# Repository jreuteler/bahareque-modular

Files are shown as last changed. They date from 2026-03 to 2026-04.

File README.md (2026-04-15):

# BaharequeModular

### Open-Source Prefabricated Panel Construction System

**Community-built, 80–100 year housing from local materials.**

> *This project is in active development. This initial publication is a work in progress — documentation will be refined, technical drawings improved, and the system built and tested in Colombia (Eje Cafetero region). All findings, test results, and design iterations will be published here as they happen. Feedback, suggestions, and contributions are welcome — file an issue or submit a pull request.*

---

## Related Techniques

This system builds on a worldwide family of traditional frame-and-infill construction: **bahareque** (Colombia), **quincha** (Peru/Chile), **wattle-and-daub** (global), **Fachwerk/colombage** (Europe), **dhajji-dewari** (Kashmir), **gaiola pombalina** (Portugal), **bajareque** (Honduras), **taquezal** (Nicaragua), **tabique** (Mexico/Philippines), **tsuchikabe** (Japan), **pau-a-pique** (Brazil). See [Philosophy](en/01-philosophy.md) for how each tradition informs this design.

## Why This Exists

Billions of people live in housing that fails — in earthquakes, floods, or simply from age. Most "affordable housing" lasts 15–20 years, trapping families in endless rebuild cycles.

**Bioconstruction** (bamboo, earth, lime) gives beautiful, breathable buildings with millennia of proven performance in tropical climates — but often lacks structural safety for seismic zones.

**Modern construction** (steel, concrete) gives safety and permits — but is expensive, requires specialized skills, and has no soul.

This system bridges both:

- **Traditional where it's seen** — lime plaster, guadua bamboo, natural textures
- **Modern where it matters** — galvanized steel L-angle frame carries seismic loads
- **80–100 year lifespan** — you build once, not every generation
- **Community-producible** — screw-clamping needs no welding, no specialized tools
- **Permaculture-integrated** — uses local bamboo, turns invasive grass into fiber reinforcement
- **Open source** — because the knowledge to build safe, beautiful, affordable housing should not be locked behind patents or consulting fees

## Quick Specs

| | |
|---|---|
| **Panel size** | 1.0 m × 2.5 m (vertical, scalable to any height) |
| **Dry-assembly weight** | ~75 kg (2 people — shipped to site before in-situ mortar pour) |
| **Finished weight (baseline mix)** | ~440 kg (≈ 176 kg/m²) |
| **Finished weight (optimized bahareque mix)** | ~360 kg (≈ 144 kg/m²) |
| **Frame** | L 40×40×4 mm, hot-dip galvanized steel (ASTM A36 / ICONTEC NTC 2542) |
| **Infill** | Structural bamboo strips, screw-clamped (30 % cavity density at baseline spec) |
| **Bracing** | Diagonal bamboo strips (3–5× seismic improvement) |
| **Mortar (baseline)** | 1:4 cement:sand + pozzolanic admixture |
| **Mortar (optimized)** | Pozzolanic lime + fly ash/RHA + pasto estrella fiber |
| **Pour method** | In-situ vertical pour (preferred) or workshop vibration-table pour |
| **Finish** | Lime plaster + lime wash |
| **Wall thickness** | ~85 mm |
| **Variants** | P (pass-through), O (outlet), S (switch), W (water) |
| **Integrated electrical** | 12V lighting + 120V mains, snap-connect between panels |

> _Combined-profile diagram pending — the previous SVG (`svg/11-combined-profile-face.svg`) shows T-bar geometry and is not representative of the current L 40×40×4 angle frame. See [`SVG-STATUS.md`](SVG-STATUS.md) for the full SVG regeneration task list._

## Repository Structure

```
bahareque-modular/
├── README.md              ← You are here
├── LICENSE-CERN-OHL-S-v2.txt
├── LICENSE-CC-BY-SA-4.0.txt
├── en/                    ← English documentation
│   ├── 01-philosophy.md
│   ├── 02-panel-anatomy.md
│   ├── 03-materials.md
│   ├── 04-construction-process.md
│   ├── 05-structural-performance.md
│   ├── 06-corrosion-prevention.md
│   ├── 08-contributing.md
│   ├── 09-cost-estimate.md
│   ├── 10-environmental-impact.md
│   ├── 11-transport-handling.md
│   ├── 12-climate-adaptation.md
│   ├── 13-bamboo-treatment.md
│   └── 14-acoustic-upgrade.md
├── de/                    ← Deutsche Dokumentation
├── es/                    ← Documentación en español
├── pt/                    ← Documentação em português
├── it/                    ← Documentazione in italiano
├── fr/                    ← Documentation en français
├── svg/                   ← Technical diagrams (language-neutral)
└── stl/                   ← 3D printable panel model
```

## Licensing

| Content | License |
|---|---|
| Hardware designs (SVGs, STLs, construction specs) | [CERN-OHL-S v2](LICENSE-CERN-OHL-S-v2.txt) |
| Documentation (text, educational content) | [CC BY-SA 4.0](LICENSE-CC-BY-SA-4.0.txt) |

**What this means:** You can freely use, modify, and distribute everything. But modifications must remain open source under the same licenses. No one can close this — not even us.

### License FAQ — Plain Language

**Can I build a house with this system?**
Yes. Free. No permission needed. No fees. No registration.

**Can I build panels and sell them?**
Yes. But you must share any design modifications you make under the same open licenses. You cannot patent your modifications.

**Can I teach a course using these documents?**
Yes. Credit the project and share any new materials you create under CC BY-SA 4.0.

**Can I patent a variation of this system?**
No. The CERN-OHL-S v2 license requires that anyone who distributes the design or products based on it grants a royalty-free patent license. This prevents anyone — including us — from patenting the system or its derivatives.

**Can a company use this commercially?**
Yes. Companies can manufacture and sell panels built with this system. They must share any design modifications under CERN-OHL-S v2. They cannot add patent restrictions.

**Why two licenses?**
CERN-OHL-S v2 is designed for physical hardware — it protects the panel design, construction method, and STL files, and includes patent defense. CC BY-SA 4.0 is designed for written works — it protects the documentation, diagrams, and educational content, and is recognized worldwide in 40+ languages. Together they cover everything.

**What if someone ignores the license?**
The same thing that happens with any open-source license violation: the community notices, the violation is documented, and legal action can follow. CC BY-SA has been upheld in courts worldwide. CERN-OHL-S is backed by CERN's legal framework.

**Can someone take this project private / close the source?**
No. Both licenses are copyleft / share-alike. Every derivative must remain open under the same terms. This is permanent and irrevocable.

## Contributing

This is a living project. We need:

- **Builders** — try it, document your experience, share what worked and what didn't
- **Engineers** — structural testing, seismic analysis, code compliance research
- **Bamboo experts** — adaptation notes for species beyond Guadua angustifolia
- **Translators** — help bring the documentation to more languages
- **Designers** — improve the SVGs, create assembly animations, render visualizations

File an issue. Submit a PR. All contributions inherit the same open licenses.

## Origin & Contact

Designed by **Jan Reuteler** (janreuteler@icloud.com), Switzerland.

Developed for the Colombian Andes (Eje Cafetero, ~2,000 m altitude) using locally available *Guadua angustifolia* — the strongest structural bamboo in the Americas. The principles apply to any tropical or subtropical region with access to structural bamboo, cement, and basic steel fabrication.

---

# BaharequeModular

### Offenes vorgefertigtes Paneel-Bausystem

**Gemeinschaftlich gebaut, 80–100 Jahre Lebensdauer, aus lokalen Materialien.**

> *Dieses Projekt befindet sich in aktiver Entwicklung. Diese erste Veröffentlichung ist ein Zwischenstand — die Dokumentation wird laufend verbessert, technische Zeichnungen verfeinert und das System in Kolumbien (Region Eje Cafetero) gebaut und getestet. Alle Erkenntnisse, Testergebnisse und Designänderungen werden hier veröffentlicht. Feedback, Vorschläge und Beiträge sind willkommen — erstellen Sie ein Issue oder einen Pull Request.*

## Warum dieses Projekt existiert

Milliarden Menschen leben in Häusern, die versagen — bei Erdbeben, Überschwemmungen oder einfach durch Alterung. Die meisten «bezahlbaren» Häuser halten 15–20 Jahre und zwingen Familien in endlose Wiederaufbauzyklen.

**Biokonstruktion** (Bambus, Erde, Kalk) liefert schöne, atmungsaktive Gebäude mit jahrtausendealter Bewährung in tropischen Klimazonen — aber oft ohne ausreichende Erdbebensicherheit.

**Moderne Bauweise** (Stahl, Beton) liefert Sicherheit und Baugenehmigungen — ist aber teuer, erfordert Fachkräfte und hat keine Seele.

Dieses System vereint beides:

- **Traditionell, wo man es sieht** — Kalkputz, Guadua-Bambus, natürliche Texturen
- **Modern, wo es zählt** — verzinkter Stahl-T-Profilrahmen trägt Erdbebenlasten
- **80–100 Jahre Lebensdauer** — einmal bauen, nicht jede Generation
- **Gemeinschaftlich herstellbar** — Schraubklemmsystem braucht kein Schweissen, kein Spezialwerkzeug
- **Permakultur-integriert** — nutzt lokalen Bambus, verwandelt invasive Gräser in Faserverstärkung
- **Open Source** — weil das Wissen, sicheres, schönes, bezahlbares Wohnen zu bauen, nicht hinter Patenten oder Beraterhonoraren eingesperrt sein darf

## Kurzspezifikationen

| | |
|---|---|
| **Paneelgrösse** | 1,0 m × 2,5 m (vertikal, skalierbar auf jede Höhe) |
| **Gewicht — Trockenmontage** | ~75 kg (2 Personen, vor Ort-Mörtelguss) |
| **Gewicht — fertig (Standardmischung)** | ~440 kg (≈ 176 kg/m²) |
| **Gewicht — fertig (optimierte Bahareque-Mischung)** | ~360 kg (≈ 144 kg/m²) |
| **Rahmen** | L-Winkel 40×40×4 mm, feuerverzinkter Stahl (ASTM A36) |
| **Füllung** | Bambus-Strukturstreifen, schraubgeklemmt (30 % Hohlraumdichte) |
| **Aussteifung** | Diagonale Bambus-Aussteifung (3–5× Erdbebenverbesserung) |
| **Mörtel** | 1:4 Zement:Sand + puzzolanisches Zusatzmittel (Standard), oder hydraulischer Kalk + Flugasche/RHA + Pasto-Estrella-Fasern (optimiert) |
| **Gussverfahren** | Vor-Ort-Vertikalguss (bevorzugt) oder Werkstatt-Rütteltisch |
| **Oberfläche** | Kalkputz + Kalkanstrich |
| **Wandstärke** | ~85 mm |

> _Hinweis: Die Übersetzungen (DE/ES/FR/IT/PT) außerhalb dieser Schnellspezifikation spiegeln noch die vorherige T-Profil-Spezifikation wider und werden in einem nachfolgenden Update angeglichen._

## Lizenzierung

| Inhalt | Lizenz |
|---|---|
| Hardware-Designs (SVGs, STLs, Bauspezifikationen) | CERN-OHL-S v2 |
| Dokumentation (Texte, Bildungsinhalte) | CC BY-SA 4.0 |

Sie dürfen alles frei nutzen, verändern und verbreiten. Änderungen müssen unter denselben Lizenzen offen bleiben.

### Lizenz-FAQ

**Kann ich ein Haus mit diesem System bauen?**
Ja. Kostenlos. Ohne Genehmigung. Ohne Gebühren. Ohne Registrierung.

**Kann ich Paneele herstellen und verkaufen?**
Ja. Aber Sie müssen alle Designänderungen unter denselben offenen Lizenzen teilen. Sie können Ihre Änderungen nicht patentieren.

**Kann ich einen Kurs mit diesen Dokumenten geben?**
Ja. Nennen Sie das Projekt und teilen Sie neues Material unter CC BY-SA 4.0.

**Kann jemand eine Variante dieses Systems patentieren?**
Nein. Die CERN-OHL-S v2 Lizenz verlangt, dass jeder, der das Design oder darauf basierende Produkte verbreitet, eine gebührenfreie Patentlizenz erteilt.

**Kann ein Unternehmen dies kommerziell nutzen?**
Ja. Unternehmen können Paneele herstellen und verkaufen. Designänderungen müssen unter CERN-OHL-S v2 geteilt werden. Patentbeschränkungen dürfen nicht hinzugefügt werden.

**Kann jemand dieses Projekt schliessen?**
Nein. Beide Lizenzen sind Copyleft / Share-Alike. Jedes Derivat muss offen bleiben. Dies ist dauerhaft und unwiderruflich.

## Ursprung & Kontakt

Entworfen von **Jan Reuteler** (janreuteler@icloud.com), Schweiz.

Entwickelt für die kolumbianischen Anden (Eje Cafetero, ~2.000 m Höhe) mit lokal verfügbarer *Guadua angustifolia* — dem stärksten Strukturbambus der Amerikas. Die Prinzipien sind auf jede tropische oder subtropische Region mit Zugang zu Strukturbambus, Zement und einfacher Stahlverarbeitung anwendbar.

---

# BaharequeModular

### Sistema Abierto de Paneles Prefabricados

**Construido por la comunidad, 80–100 años de vida útil, con materiales locales.**

> *Este proyecto está en desarrollo activo. Esta publicación inicial es un trabajo en progreso — la documentación se irá refinando, los dibujos técnicos mejorados, y el sistema será construido y probado en Colombia (región del Eje Cafetero). Todos los hallazgos, resultados de pruebas e iteraciones de diseño se publicarán aquí. Comentarios, sugerencias y contribuciones son bienvenidos — abra un issue o envíe un pull request.*

## Por qué existe este proyecto

Miles de millones de personas viven en viviendas que fallan — en terremotos, inundaciones o simplemente por el paso del tiempo. La mayoría de la «vivienda asequible» dura 15–20 años, atrapando a las familias en ciclos interminables de reconstrucción.

**Bioconstrucción** (guadua, tierra, cal) ofrece edificios hermosos y transpirables con milenios de rendimiento comprobado en climas tropicales — pero frecuentemente sin suficiente seguridad sísmica.

**Construcción moderna** (acero, concreto) ofrece seguridad y permisos — pero es costosa, requiere mano de obra especializada y carece de alma.

Este sistema une ambos mundos:

- **Tradicional donde se ve** — pañete de cal, guadua, texturas naturales
- **Moderno donde importa** — marco de acero galvanizado en T soporta cargas sísmicas
- **80–100 años de vida útil** — se construye una sola vez, no cada generación
- **Producible por la comunidad** — el sistema de sujeción por tornillo no requiere soldadura ni herramientas especializadas
- **Integrado con permacultura** — usa guadua local, convierte pastos invasivos en refuerzo de fibra
- **Código abierto** — porque el conocimiento para construir vivienda segura, bella y asequible no debe estar encerrado detrás de patentes ni honorarios de consultoría

## Especificaciones rápidas

| | |
|---|---|
| **Tamaño del panel** | 1,0 m × 2,5 m (vertical, escalable a cualquier altura) |
| **Peso — ensamble en seco** | ~75 kg (2 personas, antes del vertido in-situ del mortero) |
| **Peso — terminado (mezcla base)** | ~440 kg (≈ 176 kg/m²) |
| **Peso — terminado (mezcla bahareque optimizada)** | ~360 kg (≈ 144 kg/m²) |
| **Marco** | Ángulo L 40×40×4 mm, acero galvanizado en caliente (ASTM A36 / ICONTEC NTC 2542) |
| **Relleno** | Tiras de bambú estructural, sujetadas con tornillos (30 % de densidad de cavidad) |
| **Arriostramiento** | Tiras diagonales de bambú (mejora sísmica 3–5×) |
| **Mortero** | 1:4 cemento:arena + adición puzolánica (base), o cal hidráulica + ceniza volante/RHA + fibras de pasto estrella (optimizado) |
| **Método de vertido** | Vertido vertical in-situ (preferido) o mesa vibratoria en taller |
| **Acabado** | Pañete de cal + lechada de cal |

> _Nota: Las traducciones (DE/ES/FR/IT/PT) fuera de esta especificación rápida aún reflejan la especificación anterior de perfil T y se actualizarán en una revisión posterior._
| **Espesor de muro** | ~85 mm |

## Licenciamiento

| Contenido | Licencia |
|---|---|
| Diseños de hardware (SVGs, STLs, especificaciones constructivas) | CERN-OHL-S v2 |
| Documentación (textos, contenido educativo) | CC BY-SA 4.0 |

Puede usar, modificar y distribuir todo libremente. Las modificaciones deben permanecer abiertas bajo las mismas licencias. Nadie puede cerrar esto — ni siquiera nosotros.

### Preguntas Frecuentes sobre la Licencia

**¿Puedo construir una casa con este sistema?**
Sí. Gratis. Sin permiso. Sin tarifas. Sin registro.

**¿Puedo fabricar paneles y venderlos?**
Sí. Pero debe compartir cualquier modificación de diseño bajo las mismas licencias abiertas. No puede patentar sus modificaciones.

**¿Puedo dar un curso usando estos documentos?**
Sí. Cite el proyecto y comparta cualquier material nuevo bajo CC BY-SA 4.0.

**¿Se puede patentar una variación de este sistema?**
No. La licencia CERN-OHL-S v2 requiere que cualquier persona que distribuya el diseño o productos basados en él otorgue una licencia de patente libre de regalías.

**¿Puede una empresa usar esto comercialmente?**
Sí. Las empresas pueden fabricar y vender paneles. Deben compartir modificaciones de diseño bajo CERN-OHL-S v2. No pueden agregar restricciones de patente.

**¿Alguien puede cerrar el código fuente de este proyecto?**
No. Ambas licencias son copyleft / share-alike. Cada derivado debe permanecer abierto. Esto es permanente e irrevocable.

## Origen y contacto

Diseñado por **Jan Reuteler** (janreuteler@icloud.com), Suiza.

Desarrollado para los Andes colombianos (Eje Cafetero, ~2.000 m de altitud) usando *Guadua angustifolia* disponible localmente — el bambú estructural más fuerte de las Américas. Los principios son aplicables a cualquier región tropical o subtropical con acceso a bambú estructural, cemento y fabricación básica de acero.

---

# BaharequeModular

### Sistema Aberto de Painéis Pré-fabricados

**Construído pela comunidade, 80–100 anos de vida útil, com materiais locais.**

> *Este projeto está em desenvolvimento ativo. Esta publicação inicial é um trabalho em andamento — a documentação será refinada, os desenhos técnicos melhorados, e o sistema será construído e testado na Colômbia (região do Eje Cafetero). Todos os resultados e iterações de design serão publicados aqui. Comentários, sugestões e contribuições são bem-vindos.*

Documentação completa: [pt/](pt/)

**Licença:** Hardware: CERN-OHL-S v2 · Documentação: CC BY-SA 4.0

Pode construir, fabricar, vender, ensinar — tudo livre. Modificações devem permanecer abertas. Ninguém pode patentear variações. Ninguém pode fechar o código. Permanente e irrevogável.

Projetado por **Jan Reuteler** (janreuteler@icloud.com), Suíça.

---

# BaharequeModular

### Sistema Aperto di Pannelli Prefabbricati

**Costruito dalla comunità, 80–100 anni di vita utile, con materiali locali.**

> *Questo progetto è in sviluppo attivo. Questa pubblicazione iniziale è un lavoro in corso — la documentazione verrà perfezionata, i disegni tecnici migliorati, e il sistema sarà costruito e testato in Colombia (regione dell'Eje Cafetero). Tutti i risultati e le iterazioni di design saranno pubblicati qui. Commenti, suggerimenti e contributi sono benvenuti.*

Documentazione completa: [it/](it/)

**Licenza:** Hardware: CERN-OHL-S v2 · Documentazione: CC BY-SA 4.0

Si può costruire, fabbricare, vendere, insegnare — tutto libero. Le modifiche devono rimanere aperte. Nessuno può brevettare variazioni. Nessuno può chiudere il codice. Permanente e irrevocabile.

Progettato da **Jan Reuteler** (janreuteler@icloud.com), Svizzera.

---

# BaharequeModular

### Système Ouvert de Panneaux Préfabriqués

**Construit par la communauté, 80–100 ans de durée de vie, avec des matériaux locaux.**

> *Ce projet est en développement actif. Cette publication initiale est un travail en cours — la documentation sera affinée, les dessins techniques améliorés, et le système sera construit et testé en Colombie (région de l'Eje Cafetero). Tous les résultats et itérations de conception seront publiés ici. Commentaires, suggestions et contributions sont les bienvenus.*

Documentation complète : [fr/](fr/)

**Licence :** Hardware : CERN-OHL-S v2 · Documentation : CC BY-SA 4.0

Vous pouvez construire, fabriquer, vendre, enseigner — tout est libre. Les modifications doivent rester ouvertes. Personne ne peut breveter des variations. Personne ne peut fermer le code. Permanent et irrévocable.

Conçu par **Jan Reuteler** (janreuteler@icloud.com), Suisse.

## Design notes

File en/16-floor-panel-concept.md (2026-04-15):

# Floor Panel Concept — Bamboo Bowstring Beam

> **Status: Concept under refinement — not tested.** This document describes a proposed extension of the BaharequeModular panel system for horizontal floor/ceiling spans. All structural estimates are analytical and require lab validation. Contributions, critique, and testing offers are welcome.

## The Goal

Extend BaharequeModular from a wall system to a **complete building system** — walls, floors, and ceilings from the same production line, same materials, same skills. No concrete slab. No steel beams. No rebar.

## The Problem

A standard 85 mm wall panel fails when laid horizontally to span 4–5 m as a floor. The mortar cracks in tension on the bottom face — the panel was designed for compression (walls), not bending (floors).

## The Solution: Bamboo Bowstring Beam

A single T-bar frame (the same part used in wall panels) with a **tied-arch** mechanism inside:

- **Bamboo compression arch** — strips forced into a parabolic curve by graduated perpendicular cross-pieces sitting on top of the T-bar web
- **Bamboo tension tie** — 26 strips (30 × 35 mm) screw-clamped in a single layer across the bottom T-bar flange
- **Mortar** fills and stabilizes everything
- **Minimal steel in the span** — one longitudinal T-bar as central spine, plus perimeter T-bar frame for connections

Floor Panel Side View

Each material does what it does best:

| Material | Role | Strength used |
|---|---|---|
| Bamboo arch | Compression | 45 MPa (only 20–31% utilized) |
| Bamboo tie | Tension | 25 MPa at 30% utilization |
| Bamboo cross-pieces | Geometry control | Forces arch into parabolic shape |
| Mortar | Fill + stability | Compression zone above arch |
| T-bar frame | Edge connection | Shear at supports, connection to walls |

Floor Panel Top View

## How It Works

A bowstring beam (tied arch) converts the vertical floor load into horizontal thrust. The arch carries this thrust in compression. The tie resists it in tension. The two are in equilibrium — the mortar fills between them, providing stability and distributing local loads.

```
     load (people, furniture)
     ↓ ↓ ↓ ↓ ↓ ↓ ↓ ↓ ↓ ↓ ↓
┌───────────────────────────────┐
│  mortar (compression fill)    │
│   ╭───── bamboo ARCH ─────╮  │ ← compression
│   │    forced up by         │ │
│   │    cross-pieces         │ │
│   ╰─────────────────────────╯ │
│  ════ bamboo TIE ════════════ │ ← tension
└───────────────────────────────┘
     ↑                       ↑
   wall                    wall
```

The arch rise (distance from tie to arch crown) determines how much thrust is generated. A taller arch = less thrust = fewer tie strips needed.

## Specifications (180 mm panel, recommended)

| Property | Value |
|---|---|
| Panel dimensions | 1.0 m wide × 4.0 or 5.0 m span |
| Total depth | 180 mm |
| T-bar frame | Standard T 60×60 mm (7 mm thick, 53 mm web) — single frame at bottom |
| Longitudinal T-bar | Standard T 60×60 mm (7 mm thick, 53 mm web) — single bar centered along the span |
| Bamboo arch | 27 strips × 20×20 mm × 2 layers, forced into parabola |
| Cross-pieces | 30×30 mm perpendicular bamboo, graduated 0→40 mm |
| Bamboo tie | 26 strips × 30×35 mm, single layer, screw-clamped (13 per side of longitudinal T-bar) |
| Arch rise | 127 mm (tie to crown) |
| Weight | ~325 kg/m² |

## Structural Performance

| Span | Thrust | Arch ratio | Combined tie ratio | Deflection | Status |
|---|---|---|---|---|---|
| 4.0 m | 121 kN | 0.31 (69% reserve) | 0.42 (58% reserve) | 2.2 mm / 13.3 limit | OK |
| 5.0 m | 189 kN | 0.49 (51% reserve) | 0.65 (35% reserve) | 5.0 mm / 16.7 limit | OK |

Floor load: 4.5 kN/m² (dead 2.5 + live 2.0, per NSR-10 residential). Self-weight included.

Combined tie capacity: bamboo tie (205 kN) + longitudinal T-bar in tension (86 kN) = 291 kN.

## Longitudinal T-Bar — Central Spine

A single standard T-bar (T 60×60 mm (7 mm thick, 53 mm web)) runs the full span length, centered in the 1 m width, positioned 10 mm above the bottom panel surface. This converts the panel from a pure bowstring into a hybrid bowstring + reinforced beam.

```
CROSS-SECTION (looking along span):

    ←────────── 1,000 mm ──────────→
    ┌──────────────────────────────────┐
    │           mortar                 │
    │    ╭──── bamboo arch ────╮       │  180 mm
    │    │                     │       │
    │    ╰─────────────────────╯       │
    │  ═ tie ═══ ┬─┤ ═══ tie ═════    │
    │            │w│                   │  ← longitudinal T-bar
    │         ┌──┴─┴──┐                │     10 mm from bottom
    └─────────┘flange └────────────────┘
              ←30mm→
         13 strips    13 strips
         each side    each side
```

### Why It Matters

The bamboo tie alone carries 205 kN — at a 5 m span with 189 kN of thrust, that is 98% utilization (2% reserve). This is the weakest link in the entire panel.

The longitudinal T-bar adds 86 kN of steel tension capacity (345 mm² × 250 MPa yield), bringing the combined capacity to 291 kN — a **42% increase** for just 13.5 kg of steel.

| | Bamboo tie only | Bamboo tie + T-bar |
|---|---|---|
| Tension capacity | 205 kN | 291 kN |
| Tie ratio (5 m) | 0.98 | 0.65 |
| Safety factor (5 m) | 2.04 | 2.90 |

### Additional Benefits

- **Redundancy** — hybrid system: if the bowstring mechanism partially fails, the T-bar alone carries 78% of the required bending moment as a reinforced beam
- **Deflection** — steel stiffness (E = 200 GPa) significantly reduces mid-span deflection
- **Clamping anchor** — the V-profile strips at the supports can be welded to the longitudinal T-bar where they cross, creating a steel-to-steel connection
- **Soffit rail** — the flange at 10 mm from bottom provides a continuous steel rail for temporary soffit panel clamps during the pour

### Specification

| Property | Value |
|---|---|
| Profile | Standard T 60×60 mm (7 mm thick, 53 mm web) |
| Length | Full span (4.0 or 5.0 m) |
| Position | Centered in 1 m width, 10 mm from bottom surface |
| Weight | 10.8 kg (4 m) / 13.5 kg (5 m) |
| Cost | ~$15–20 |
| Tie strip layout | 13 strips per side (26 total, same as before) |

The same T-bar profile used in the perimeter frame. Same stock, same supplier, one extra cut per panel.

## Critical Detail: Tie Strip Clamping

The bamboo tension tie carries the full horizontal thrust of the arch — 121 kN (4 m span) or 189 kN (5 m span), shared across 26 strips. Per strip:

| Span | Tension per strip | With safety factor 2.0 |
|---|---|---|
| 4.0 m | 4,654 N | 9,308 N |
| 5.0 m | 7,269 N | 14,538 N |

If the clamping fails, the entire bowstring mechanism fails. This is the most critical connection in the panel.

### The Problem with Smooth Clamping

Each tie strip crosses the transverse T-bar at each support end. The T-bar flange is only 30 mm wide — providing 30 mm of clamping length per end. With smooth steel-on-bamboo friction (μ ≈ 0.4), the pull-out capacity is marginal at 4 m and insufficient at 5 m.

### Solution: V-Profile Clamping Strip

A steel clamping strip with a stamped **V-tooth profile** (teeth facing the bamboo) converts the connection from friction to mechanical interlock:

```
    screw    screw    screw
       ↓        ↓        ↓
      ╔═╗      ╔═╗      ╔═╗
──────╝ ╚──────╝ ╚──────╝ ╚──  top V-strip (teeth down)
  ╲╱╲╱╲╱╲╱╲╱╲╱╲╱╲╱╲╱╲╱╲╱╲╱╲   teeth indent into bamboo
  ════════════════════════════   bamboo tie strips
  ╱╲╱╲╱╲╱╲╱╲╱╲╱╲╱╲╱╲╱╲╱╲╱╲╱   teeth indent into bamboo (offset)
──────────────────────────────  bottom V-strip (teeth up)
══════════════════════════════  T-bar flange
```

Two V-profile strips sandwich the bamboo — the bottom strip sits on the T-bar flange (teeth up), the top strip presses down (teeth down). The teeth are **offset by half a pitch** (3 mm) so they engage different fibers on each face, avoiding stress concentration and splitting risk.

### Clamping Strip Specification

| Property | Value |
|---|---|
| Material | 3 mm galvanized steel flat bar |
| Width | 100 mm |
| V-tooth pitch | 6 mm |
| V-tooth depth | 2 mm |
| Length | 1,000 mm (full panel width — one strip clamps all 26 ties) |
| Screws | M5, every 2nd strip (13 screws per end) |
| Quantity | 4 per panel (top + bottom at each support end) |
| Cost | ~$5/panel |
| Fabrication | Stamp or press V-profile into flat bar with toothed die |

### Capacity Estimate

Each V-tooth creates a shear lip in the bamboo:

- Shear area per tooth: 30 mm (strip width) × 1.5 mm (indent) = 45 mm²
- Bamboo shear strength parallel to grain: ~7 MPa
- Resistance per tooth: 315 N
- Teeth per strip (100 mm at 6 mm pitch): ~16 teeth
- Mechanical interlock per face: 16 × 315 = **5,040 N**
- Double-sided (top + bottom): 2 × 5,040 = **10,080 N per end**
- **Both ends: ~20,160 N**

| Span | Required (SF=2.0) | Double V-profile capacity | Reserve |
|---|---|---|---|
| 4.0 m | 9,308 N | 20,160 N | 117% |
| 5.0 m | 14,538 N | 20,160 N | 39% |

These estimates are conservative — they ignore the mortar bond that encases the entire clamping zone after the pour.

### Support Node: Teak End Block

The V-profile clamping must anchor to something solid at the supports. HDPE blocks — used as spacers in wall panels — are too soft for this role: HDPE creeps under sustained load (losing 60–70% of strength over decades) and is 15× less stiff than wood. A floor panel under permanent dead load needs a material that holds its shape for 50+ years.

**Solution: a teak end block at each support.**

```
CROSS-SECTION AT SUPPORT:

    ┌──────────────────────────────┐ 180 mm
    │          mortar              │
    │    ┌────────────────────┐    │
    │    │                    │    │
    │    │    TEAK BLOCK      │    │ 60 mm
    │    │    60 × 60 mm      │    │
    │    │                    │    │
    │    └────────────────────┘    │
    │    ════ tie strips ═════    │
    └──────────────────────────────┘
         ←── 60 mm ──→
           (along span)
```

| Property | Value |
|---|---|
| Species | Tectona grandis (teak) |
| Cross-section | 60 × 60 mm |
| Length | 1,000 mm (full panel width) |
| Grain direction | Parallel to thrust (along span) |
| Quantity | 2 per panel (one per support end) |
| Weight | ~2.4 kg per block |
| Cost | ~$3.50 per block |
| Source | B-grade pieces and offcuts from structural teak — hidden inside mortar, appearance irrelevant |

**Why teak works here:**

| Property | HDPE | Teak |
|---|---|---|
| Compressive strength ∥ grain | 22 MPa | 58 MPa |
| Stiffness | 1.0 GPa | 13 GPa |
| 50-year creep | 60–70% loss | <5% loss |
| Rot resistance | Immune | Class 1 (natural oils) |
| Screw-holding (M5) | Poor | ~1,350 N withdrawal per screw |
| Bolt holes (M12) | Crush risk | Clean, tight, no splitting |

Arch bearing stress on the teak block (5 m span): 189,000 N / 60,000 mm² = 3.15 MPa — just **5.4% utilization** of teak's 58 MPa capacity.

**The teak block serves as a multi-function structural node:**

1. **Arch bearing** — arch strips push against its inner face
2. **V-strip mounting** — screws for the clamping strips bite into teak
3. **Overlength bolt passage** — M12 × 110 mm bolts drill clean through 60 mm
4. **Geometry anchor** — defines exact arch start point at each support
5. **No treatment needed** — teak's natural oils resist rot inside mortar

HDPE spacer blocks remain in mid-span zones where forces are low and their role is geometry only.

### Testing Priority

A pull-out test of a single clamped strip is the simplest and most critical validation: clamp one 30 × 35 mm bamboo strip between V-profile strips on a teak block, pull to failure, measure peak force. This can be done with a hydraulic jack and a bathroom scale in minutes.

## Integrated Services

Services are embedded during the pour — same approach as wall panels:

- **Electrical conduit** (12V + 120V) in the core — ceiling lights below, floor outlets above
- **Water pipes** (CPVC/PEX) horizontal runs in the core
- **Recessed LED lights** — junction boxes flush with bottom T-bar flange
- **Snap-connect** at panel edges — circuits continue from wall to floor to wall

## Acoustic Performance

The mortar mass provides STC 52–55 (airborne sound). Impact noise (footsteps) is addressed by:

- **Pasto estrella fiber** (3–5% by volume) in the upper mortar zone — free invasive grass, millions of fiber-mortar interfaces absorb vibration
- **Cork underlay** (3 mm) under terracotta tiles — $4/m², adds IIC +15–20
- Combined: IIC 58–63 (luxury hotel level) at minimal cost

## Construction Process

Poured in place on top of wall panels:

1. Set T-bar frame on connector shelf (~25 kg — easy to carry)
2. **Bolt adjacent floor panel frames together** — 2× M12 through shared longitudinal flanges (at 1/3 and 2/3 of span)
3. Bolt floor frame to connector shelf — 2× M12 vertical at each support end
4. Clamp soffit panel from below — positioned **10–15 mm below the T-bar bottom flange** to allow mortar to flow under and fully encase the steel frame from below. The soffit defines the ceiling surface.
5. Screw-clamp bamboo tie strips to bottom flange
6. Insert teak end blocks at support zones
7. Lay bamboo arch strips into teak block recesses at designated heights
8. Install conduit, pipes, junction boxes
9. Pour mortar — flows down past the flange, encasing the bottom of the T-bar frame. Standard mix for lower zone, fiber-rich for upper zone.
10. Vibrator probe along the span — eliminates voids, ensures mortar fills under and around the flange
11. Screed top surface flat
12. Cure 7+ days
13. Remove soffit → reuse for next bay. The ceiling face is a smooth mortar surface with the steel frame fully hidden inside (10–15 mm mortar cover below the flange).
14. Lime plaster ceiling directly onto the mortar surface — no bare steel visible
15. Cork + terracotta tiles on top

> **Access panel rule:** Always leave at least one floor panel frame unbolted and unpoured per bay until all neighboring panels are poured and cured. This access panel allows workers to reach the panel-to-panel bolts for tightening and inspection. It is bolted and poured last.

## What's Novel

Exhaustive search of academic literature, patents, and built projects found **no existing system** that combines:

1. Bamboo compression arch within a floor element
2. Bamboo tension tie at the bottom
3. Tied-arch (bowstring) mechanism
4. Mortar encasement

Each principle is well-established individually. The combination is new. Closest prior art:

| Existing work | What's different |
|---|---|
| Curved laminated bamboo-concrete T-beam (2023) | No tension tie, glulam not strips |
| Bamboo-reinforced concrete (Ghavami, 1979+) | Always straight reinforcement, never arched |
| Bowstring trusses (steel/timber) | Never bamboo, never mortar-encased |
| Ferrocement bamboo panels (India) | Flat, short spans, no arch |

## What Needs Testing

Before building floor panels, the following must be validated:

1. **Does the tied-arch action develop?** — Load a test panel, measure horizontal thrust at supports
2. **Does the forced arc hold under load?** — Do cross-pieces maintain the arch geometry?
3. **Bamboo tie tension** — Does the 30×35 mm clamped bundle maintain capacity under arch thrust?
4. **Composite action** — Does the mortar-bamboo bond hold in the arch under compression?
5. **Impact sound** — Measure IIC with and without pasto estrella fiber
6. **Connection** — Test the overlength bolt system (wall-floor-wall triple flange)

A single bending test (simply supported, uniform load) answers questions 1–4 in one afternoon.

## Weight Optimization: Dense Bamboo End Zones

In a bowstring beam, the arch rise is near zero at the supports — the mortar above the arch is at maximum depth but carries no compression. Shear is maximum at the supports, but at only 5% utilization (0.075 MPa vs 1.5 MPa capacity). This means the end zones contain the most mortar doing the least structural work.

**The idea:** replace most of the mortar in the end zones with densely packed bamboo strips.

### Geometry

End zone: first and last 750 mm of the span. The mortar depth above the arch varies from ~140 mm at the support to ~80 mm at 750 mm.

### Fabrication

1. Bundle bamboo strips (20 × 30 mm) tightly, wire-tied into a solid block
2. Cut block ~10 mm wider than the panel cavity (~1,010 mm)
3. Press-fit into the end zone above the arch — the bamboo's natural spring wedges it tight against the T-bar web and panel edges, self-clamping with no fasteners
4. During the mortar pour, mortar penetrates the small irregular gaps between strips, locking everything permanently

With rectangular strips packed tight, the natural surface irregularity of split bamboo yields approximately 60% bamboo / 40% mortar by volume.

### Weight Saving

| | Solid mortar (current) | Dense bamboo packing |
|---|---|---|
| Bamboo | — | 0.099 m³ × 700 kg/m³ = 69 kg |
| Mortar | 0.165 m³ × 2,100 kg/m³ = 347 kg | 0.066 m³ × 2,100 kg/m³ = 139 kg |
| **Total (both ends)** | **347 kg** | **208 kg** |
| **Saving** | — | **~139 kg (11% of panel weight)** |

### Why It Works

- **Shear transfer:** bamboo has good shear strength (~8 MPa) — the dense pack with mortar-filled gaps transfers support shear better than unreinforced mortar alone
- **Bearing capacity:** bamboo excels in compression (45 MPa) — directly above the support, this is an advantage
- **No bending moment** at the supports — the end zones don't need mortar's mass for structural depth
- **Simple fabrication:** pre-assembled blocks can be cut to width and press-fit, adding one easy step to the construction process

## Future Option: Half-Culm Voided Panel

For spans beyond 5 m, split guadua culms (⌀100 mm, open cavity down, drilled air holes) can be embedded in the compression zone above the arch. The hollow cores displace mortar, and the culm walls contribute compression capacity. This increases depth (220+ mm) without proportional weight increase. See detailed analysis in the Suroeste project documentation.

## Implications

If validated, this floor panel makes BaharequeModular a **complete building system**:

- **Walls** — standard 85 mm panel
- **Floors/ceilings** — 180 mm bowstring panel
- **Connections** — bolted T-bar flanges at every junction
- **Electrical** — integrated in all panels, snap-connected
- **Plumbing** — integrated in floor and wall panels
- **Ceiling finish** — lime plaster on floor panel bottom

One panel system. One production line. One set of skills. No rebar, no structural steel beams — bamboo and mortar carry the loads, with one standard T-bar as a central spine for redundancy. Steel only at edges and center for connections and tension backup.

**A bamboo bowstring beam cast in mortar. It doesn't exist yet. We intend to build and test it.**

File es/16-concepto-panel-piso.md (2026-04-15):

# Concepto de Panel de Piso — Viga Arco de Bambú

> **Estado: Concepto en desarrollo — no probado.** Este documento describe una propuesta de extensión del sistema BaharequeModular para luces horizontales de piso/techo. Todas las estimaciones estructurales son analíticas y requieren validación en laboratorio. Contribuciones, críticas y ofertas de ensayos son bienvenidas.

## El Objetivo

Extender BaharequeModular de un sistema de muros a un **sistema constructivo completo** — muros, pisos y techos desde la misma línea de producción, mismos materiales, mismas habilidades. Sin losa de concreto. Sin vigas de acero. Sin refuerzo de acero.

## El Problema

Un panel de muro estándar de 85 mm falla cuando se coloca horizontalmente para cubrir luces de 4–5 m como piso. El mortero se fisura en tracción en la cara inferior — el panel fue diseñado para compresión (muros), no para flexión (pisos).

## La Solución: Viga Arco de Bambú (Bowstring Beam)

Un solo marco de perfil T (la misma pieza usada en paneles de muro) con un mecanismo de **arco atirantado** interior:

- **Arco de bambú en compresión** — tiras forzadas en una curva parabólica por piezas transversales perpendiculares graduadas sobre el alma del perfil T
- **Tirante de bambú en tracción** — 26 tiras (30 × 35 mm) sujetadas con tornillos en una sola capa en el ala inferior del perfil T
- **Mortero** rellena y estabiliza todo
- **Cero acero en la luz** — acero solo en el marco perimetral del perfil T para conexiones

Vista lateral del panel de piso

Cada material hace lo que mejor sabe hacer:

| Material | Función | Resistencia utilizada |
|---|---|---|
| Arco de bambú | Compresión | 45 MPa (solo 20–31% utilizado) |
| Tirante de bambú | Tracción | 25 MPa al 30% de utilización |
| Piezas transversales | Control geométrico | Fuerzan el arco en forma parabólica |
| Mortero | Relleno + estabilidad | Zona de compresión sobre el arco |
| Marco de perfil T | Conexión perimetral | Corte en apoyos, conexión a muros |

Vista superior del panel de piso

## Cómo Funciona

Una viga arco (arco atirantado) convierte la carga vertical del piso en empuje horizontal. El arco lleva este empuje en compresión. El tirante lo resiste en tracción. Los dos están en equilibrio — el mortero rellena entre ellos, proporcionando estabilidad y distribuyendo cargas locales.

## Especificaciones (panel de 180 mm, recomendado)

| Propiedad | Valor |
|---|---|
| Dimensiones del panel | 1,0 m ancho × 4,0 o 5,0 m de luz |
| Profundidad total | 180 mm |
| Marco de perfil T | Estándar 30×30×3 mm, alma de 85 mm — un solo marco en la parte inferior |
| Arco de bambú | 27 tiras × 20×20 mm × 2 capas, forzado en parábola |
| Piezas transversales | Bambú de 30×30 mm, graduadas de 0→40 mm |
| Tirante de bambú | 26 tiras × 30×35 mm, una sola capa, sujetadas con tornillos |
| Flecha del arco | 127 mm (tirante a corona) |
| Peso | ~325 kg/m² |

## Rendimiento Estructural

| Luz | Empuje | Ratio arco | Ratio tirante | Deflexión | Estado |
|-----|---|---|---|---|---|
| 4,0 m | 121 kN | 0,31 (69% reserva) | 0,92 (8% reserva) | 2,2 mm / 13,3 límite | OK |
| 5,0 m | 189 kN | 0,49 (51% reserva) | 0,98 (2% reserva) | 5,0 mm / 16,7 límite | OK |

Carga de piso: 4,5 kN/m² (muerta 2,5 + viva 2,0, según NSR-10 residencial). Peso propio incluido.

## Detalle Crítico: Sujeción de las Tiras del Tirante

El tirante de bambú lleva todo el empuje horizontal del arco — 121 kN (luz de 4 m) o 189 kN (luz de 5 m), repartido entre 26 tiras. Por tira:

| Luz | Tracción por tira | Con factor de seguridad 2,0 |
|-----|---|---|
| 4,0 m | 4.654 N | 9.308 N |
| 5,0 m | 7.269 N | 14.538 N |

Si la sujeción falla, todo el mecanismo de arco atirantado falla. Esta es la conexión más crítica del panel.

### El Problema con Sujeción Lisa

Cada tira del tirante cruza el perfil T transversal en cada apoyo. El ala del perfil T tiene solo 30 mm de ancho — proporcionando 30 mm de longitud de sujeción por extremo. Con fricción lisa acero-bambú (μ ≈ 0,4), la capacidad de extracción es marginal a 4 m e insuficiente a 5 m.

### Solución: Tira de Sujeción con Perfil en V

Una tira de sujeción de acero con un **perfil dentado en V** estampado (dientes hacia el bambú) convierte la conexión de fricción a interbloqueo mecánico:

```
    tornillo  tornillo  tornillo
       ↓         ↓         ↓
      ╔═╗       ╔═╗       ╔═╗
──────╝ ╚───────╝ ╚───────╝ ╚──  Tira con perfil V (dientes abajo)
═════════╤════════╤════════╤════  Tiras de bambú del tirante
─────────┴────────┴────────┴────  Ala del perfil T (lisa)
```

El bambú se apoya sobre el ala lisa del perfil T. La tira en V presiona desde arriba, con los dientes indentando ~1,5–2 mm en la superficie del bambú. Para extraerse, el bambú debe cortar por cizallamiento cada indentación — no solo superar la fricción.

### Especificación de la Tira de Sujeción

| Propiedad | Valor |
|---|---|
| Material | Pletina de acero galvanizado de 3 mm |
| Ancho | 100 mm |
| Paso de dientes en V | 6 mm |
| Profundidad de dientes | 2 mm |
| Longitud | 1.000 mm (ancho completo del panel — una tira sujeta las 26 tiras del tirante) |
| Tornillos | M5, cada 2 tiras (13 tornillos por extremo) |
| Cantidad | 2 por panel (uno por apoyo) |
| Costo | ~$3/panel |
| Fabricación | Estampar o prensar perfil V en pletina con troquel dentado |

### Estimación de Capacidad

Cada diente en V crea un labio de cizallamiento en el bambú:

- Área de corte por diente: 30 mm (ancho de tira) × 1,5 mm (profundidad) = 45 mm²
- Resistencia al corte del bambú paralelo a la fibra: ~7 MPa
- Resistencia por diente: 315 N
- Dientes por tira (100 mm a paso de 6 mm): ~16 dientes
- Interbloqueo mecánico por extremo: 16 × 315 = **5.040 N**
- Más fricción en cara inferior: ~3.072 N
- **Total por extremo: ~8.112 N → ambos extremos: ~16.224 N**

| Luz | Requerido (FS=2,0) | Capacidad perfil V | Reserva |
|-----|---|---|---|
| 4,0 m | 9.308 N | 16.224 N | 74% |
| 5,0 m | 14.538 N | 16.224 N | 12% |

Estas estimaciones son conservadoras — ignoran la adherencia del mortero que encapsula toda la zona de sujeción después del vertido.

### Prioridad de Ensayo

Un ensayo de extracción de una sola tira sujetada es la validación más simple y crítica: sujetar una tira de bambú de 30 × 35 mm con el perfil V, tirar hasta la falla, medir la fuerza máxima. Esto se puede hacer con un gato hidráulico y una balanza en minutos.

## Lo Que es Nuevo

Búsqueda exhaustiva de literatura académica, patentes y proyectos construidos no encontró **ningún sistema existente** que combine:

1. Arco de bambú en compresión dentro de un elemento de piso
2. Tirante de bambú en tracción en la parte inferior
3. Mecanismo de arco atirantado (bowstring)
4. Encapsulamiento en mortero

Cada principio está bien establecido individualmente. La combinación es nueva. Coincidencias más cercanas:

| Trabajo existente | Qué falta |
|---|---|
| Viga T de bambú laminado curvo-concreto (2023) | Sin tirante de tracción, bambú laminado no tiras |
| Concreto reforzado con bambú (Ghavami, 1979+) | Siempre refuerzo recto, nunca en arco |
| Cerchas bowstring (acero/madera) | Nunca en bambú, nunca encapsuladas en mortero |
| Paneles de ferrocemento con bambú (India) | Planos, luces cortas, sin arco |

## Lo Que Necesita Pruebas

1. **¿Se desarrolla la acción de arco atirantado?** — Cargar un panel de prueba, medir el empuje horizontal en los apoyos
2. **¿Se mantiene el arco forzado bajo carga?** — ¿Las piezas transversales mantienen la geometría del arco?
3. **Tracción del tirante de bambú** — ¿El paquete de 30×35 mm sujetado mantiene su capacidad bajo el empuje del arco?
4. **Acción compuesta** — ¿Se mantiene la adherencia mortero-bambú en el arco bajo compresión?
5. **Sonido de impacto** — Medir IIC con y sin fibra de pasto estrella
6. **Conexión** — Probar el sistema de pernos de longitud extra (unión muro-piso-muro con triple ala)

Un solo ensayo de flexión (simplemente apoyado, carga uniforme) responde las preguntas 1–4 en una tarde.

## Optimización de Peso: Zonas de Extremo con Bambú Denso

En una viga arco atirantado, la flecha del arco es cercana a cero en los apoyos — el mortero sobre el arco tiene máxima profundidad pero no lleva compresión. El cortante es máximo en los apoyos, pero con solo 5% de utilización (0,075 MPa vs 1,5 MPa de capacidad). Esto significa que las zonas de extremo contienen más mortero haciendo menos trabajo estructural.

**La idea:** reemplazar la mayor parte del mortero en las zonas de extremo con tiras de bambú densamente empacadas.

### Geometría

Zona de extremo: primeros y últimos 750 mm de la luz. La profundidad de mortero sobre el arco varía de ~140 mm en el apoyo a ~80 mm a 750 mm.

### Fabricación

1. Empaquetar tiras de bambú (20 × 30 mm) apretadamente, amarradas con alambre en un bloque sólido
2. Cortar el bloque ~10 mm más ancho que la cavidad del panel (~1.010 mm)
3. Insertar a presión en la zona de extremo sobre el arco — la elasticidad natural del bambú lo acuña firmemente contra el alma del perfil T y los bordes del panel, auto-sujetándose sin fijaciones
4. Durante el vertido de mortero, este penetra los pequeños espacios irregulares entre tiras, bloqueando todo permanentemente

Con tiras rectangulares empacadas apretadamente, la irregularidad natural de la superficie del bambú rajado produce aproximadamente 60% bambú / 40% mortero por volumen.

### Ahorro de Peso

| | Mortero sólido (actual) | Empaque denso de bambú |
|---|---|---|
| Bambú | — | 0,099 m³ × 700 kg/m³ = 69 kg |
| Mortero | 0,165 m³ × 2.100 kg/m³ = 347 kg | 0,066 m³ × 2.100 kg/m³ = 139 kg |
| **Total (ambos extremos)** | **347 kg** | **208 kg** |
| **Ahorro** | — | **~139 kg (11% del peso del panel)** |

### Por Qué Funciona

- **Transferencia de cortante:** el bambú tiene buena resistencia al cortante (~8 MPa) — el empaque denso con mortero en los intersticios transfiere el cortante del apoyo mejor que el mortero sin refuerzo
- **Capacidad de aplastamiento:** el bambú sobresale en compresión (45 MPa) — directamente sobre el apoyo, esto es una ventaja
- **Sin momento flector** en los apoyos — las zonas de extremo no necesitan la masa del mortero para profundidad estructural
- **Fabricación simple:** bloques pre-ensamblados se pueden cortar al ancho e insertar a presión, agregando un paso fácil al proceso constructivo

## Implicaciones

Si se valida, este panel de piso convierte a BaharequeModular en un **sistema constructivo completo**:

- **Muros** — panel estándar de 85 mm
- **Pisos/techos** — panel bowstring de 180 mm
- **Conexiones** — alas de perfil T empernadas en cada unión
- **Electricidad** — integrada en todos los paneles
- **Plomería** — integrada en paneles de piso y muro
- **Acabado de techo** — pañete de cal en la cara inferior del panel de piso

Un sistema de paneles. Una línea de producción. Un conjunto de habilidades. Cero acero en cualquier luz — bambú y mortero llevan todo. Acero solo en los bordes para conexiones.

**Una viga arco de bambú fundida en mortero. Aún no existe. Queremos construirla y probarla.**

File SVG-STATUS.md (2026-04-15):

# SVG Regeneration — Status & Pending Tasks

The bahareque-modular documentation has shifted from a **T 60×60×7 mm T-bar** panel frame to an **L 40×40×4 mm equal-leg angle** panel frame. The text has been updated across all English chapters (see `en/02-panel-anatomy.md`, `en/03-materials.md`, `en/04-construction-process.md`, `en/05-structural-performance.md`, `en/10-environmental-impact.md`, `en/11-transport-handling.md`, `en/14-acoustic-upgrade.md`). The SVG diagrams have **not** been updated yet.

> **Chapter 07 (building integration) temporarily removed.** The panel-to-connector / ring-beam interface needs a full structural re-resolution for the L-angle panel side (the connector ring beam profile choice itself is open). The chapter has been moved out of the published docs to `../bahareque-modular-inprogress/` (sibling of this repo, not pushed to GitHub) until that decision is settled and the body text + SVGs can be revised together. The four SVGs that were chapter-07-only (`08-building-integration`, `14-floor-connection-detail`, `15-corner-piece-detail`, `16-foundation-channel`) are no longer referenced from any published chapter.

This file tracks which SVGs are **currently linked** in the documentation (representative of the L-angle spec or structurally neutral enough to reuse), and which are **pending regeneration** (still show T-bar geometry and have been unlinked from the docs pending revision).

## SVGs currently linked in docs (representative for L-angle spec)

These nine SVGs are retained in the documentation because they either do not show the panel frame profile specifically, or they show geometric elements that remain valid under the L-angle spec:

| File | Used in chapter | Notes |
|---|---|---|
| `svg/01-panel-exploded.svg` | 02-panel-anatomy | Exploded view — to be regenerated with L-angle frame in a future revision; retained provisionally |
| `svg/05-diagonal-bracing.svg` | (referenced conceptually in 02 and 05) | Diagonal bracing geometry — independent of frame profile choice |
| `svg/06-mortar-pour.svg` | 04-construction-process | Mortar pour process — independent of frame profile |
| `svg/07-assembly-sequence.svg` | 04-construction-process | High-level assembly sequence — retained provisionally pending L-angle regeneration |
| `svg/08-building-integration.svg` | 07-building-integration | Building-level integration diagram — largely independent of panel-frame detail |
| `svg/09-profile.svg` | 02-panel-anatomy, 05-structural-performance | Panel side profile (the )( profile) — geometry stays the same with L-angle |
| `svg/10-panel-face-view.svg` | 02-panel-anatomy | Panel face view — face layout independent of frame profile |
| `svg/12-floor-panel-side.svg` | 16-floor-panel-concept | Floor panel side view — separate element from wall panels |
| `svg/13-floor-panel-top.svg` | 16-floor-panel-concept | Floor panel top view — separate element |

## SVGs unlinked from docs (pending L-angle regeneration)

These SVGs show T-bar-specific geometry and have been **unlinked from the English chapters** until regenerated for the L 40×40×4 angle frame. The files themselves remain in `svg/` for reference but are no longer rendered into the published documentation:

| File | Was linked in | Issue | Pending action |
|---|---|---|---|
| `svg/02-tbar-profile.svg` | 02-panel-anatomy | Shows T 60×60×7 cross-section | **Regenerate as L 40×40×4 angle profile** |
| `svg/03-panel-cross-section.svg` | 02-panel-anatomy | Shows T-bar web in center of panel cross-section | **Regenerate with L-angle frame asymmetric about panel centerline** |
| `svg/04-screw-clamping.svg` | 04-construction-process | Shows clamping strip screwing through T-bar web | **Regenerate with clamping strip screwing through L-angle vertical web** |
| `svg/15-corner-piece-detail.svg` | 07-building-integration | Shows T-bar corner piece geometry | **Regenerate for L-angle corner detail** |
| `svg/16-foundation-channel.svg` | 07-building-integration | Shows T-bar bottom engaging foundation brick channel | **Regenerate for L-angle foundation interface** |
| `svg/17-wall-panel-frame.svg` | 04-construction-process | Shows rectangular T-bar frame | **Regenerate for L-angle rectangular frame** |
| `svg/14-floor-connection-detail.svg` | 07-building-integration | Shows T-bar panel connecting to T-bar ring beam / floor connector | **Regenerate with L-angle panel side + T 60×60 ring beam (ring beam T-bar is unchanged; panel-side interface geometry changes)** |
| `svg/11-combined-profile-face.svg` | (not currently linked) | Shows T-bar + panel face combined | **Regenerate or retire** |
| `svg/panel-2500mm.svg` | (not currently linked) | T-bar based | **Regenerate or retire** |
| `svg/panel-T60-150mm.svg` | (not currently linked) | T-bar based | **Regenerate or retire** |
| `svg/panel-T150-200mm.svg` | (not currently linked) | T-bar based | **Regenerate or retire** |
| `svg/panel-universal-cross-section.svg` | (not currently linked) | T-bar based | **Regenerate or retire** |

## Tasks — pending

1. **Regenerate core cross-section SVGs** for L 40×40×4 frame: `02-tbar-profile.svg` (rename to `02-angle-profile.svg`), `03-panel-cross-section.svg`, `17-wall-panel-frame.svg`
2. **Regenerate interface detail SVGs**: `04-screw-clamping.svg`, `15-corner-piece-detail.svg`, `16-foundation-channel.svg`, `14-floor-connection-detail.svg`
3. **Review & regenerate assembly / exploded SVGs** for L-angle: `01-panel-exploded.svg`, `07-assembly-sequence.svg`
4. **Retire or update** the panel size/thickness variant SVGs (`panel-2500mm.svg`, `panel-T60-150mm.svg`, `panel-T150-200mm.svg`, `panel-universal-cross-section.svg`, `11-combined-profile-face.svg`)
5. **Re-link updated SVGs** in the chapters once regenerated, replacing the inline `> _… pending …_` notes
6. **Cascade SVG updates to language translations** (`de/svg/`, `es/svg/`, `fr/svg/`, `it/svg/`, `pt/svg/`) — each language folder has its own `svg/` subfolder that mirrors the English set
7. **Regenerate PDFs** (`BaharequeModular-*.pdf`) via `generate_pdfs.py` after all text + SVG updates are complete

## Translations

The English chapters have been updated to reflect the L-angle spec and corrected weight figures. **The 5 translation folders (de, es, fr, it, pt) have NOT been updated** — they still reflect the T-bar spec and the old weight figures (155 kg total). When the English text is finalized, the translations need to be cascaded with the same changes, and the language-specific `svg/` folders need to sync with the regenerated English diagrams.

## Source of truth

If a diagram and the text disagree, **the text is the source of truth** until SVG regeneration catches up. The L 40×40×4 spec is definitive; any SVG still showing T-bar geometry is out of date and should not be used for fabrication or structural reference.

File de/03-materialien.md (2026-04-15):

# Materialien

## Stückliste (pro Paneel)

| Material | Spezifikation | Menge | Anmerkungen |
|---|---|---|---|
| L-Winkelstahl | L 40×40×4 mm, feuerverzinkt (ASTM A36 / ICONTEC NTC 2542 äquivalent) | 2× 1,0 m + 2× 2,5 m = 7,0 m | Kolumbianisches Lagermaterial (Gerdau Diaco, Aceros Arequipa, Acesco, Ferrasa). 6-m-Standardlängen, mit Trennschleifer geschnitten |
| Klemmleisten | 40×3 mm Flachstahl, verzinkt, passende Löcher | 4× 1,0 m = 4,0 m | Oben + unten, beide Seiten |
| Eckbleche + Schrauben | Flachblech-Verstärkungen + M12/M8 Schrauben | 1 Set | Steifere Eckverbindung anstelle reiner Schweissnaht |
| Schrauben | Edelstahl, selbstschneidend | ~28 pro Paneel | Durch Klemmleiste → Bambus → HDPE → Steg (alle ~70 mm, eine pro zwei Streifen) |
| HDPE-Blöcke | 30×30 mm Querschnitt, recycelt | 2× 1,0 m = 2,0 m | Auf oberen + unteren L-Winkel-Stegen |
| Bambusstreifen (vertikal) | Borat-behandelt, ~20 mm breit | ~54 Streifen × 2,5 m | ~27 pro Seite |
| Bambusstreifen (diagonal) | Borat-behandelt, 60×20 mm | 2× ~2,69 m | 1 pro Seite, gegenüberliegende Ecken |
| Verzinkter Draht | Bindedraht | ~5 m | ~16–20 Bindungen an Kreuzungen |
| PVC-Leerrohr | 16 mm Elektro | ~5 m | Kabelschutz |
| 12V-Kabel | 2-adrig | ~6 m | Beleuchtungsstromkreis |
| 120V-Kabel | 3-adrig (L+N+PE) | ~6 m | Netzstromkreis |
| E10-Fassungen | Schraubfassungen | 6 | 3 pro Seite |
| Snap-Stecker | 2-polig (12V) + 3-polig (120V) | 2 + 2 | An beiden Vertikalkanten |
| Hühnerdraht | Verzinktes Sechseckgeflecht, 25 mm | ~5,5 m² | Beide Seiten + Überlappung |
| Zementmörtel (Basis) | 1:4 Zement:Sand + Zusätze | ~0,147 m³ Netto-Hohlraum (nach 30 % Guadua + Stahlverdrängung) | ~310 kg nass / ~294 kg ausgehärtet (Dichte ~2 000 kg/m³) |
| Puzzolanischer Kalkmörtel mit Pasto estrella (optimiert) | Hydraulischer Kalk + 30 % Flugasche/RHA + Pasto-estrella-Fasern | ~0,147 m³ gleicher Hohlraum | ~270 kg nass / ~257 kg ausgehärtet (Dichte ~1 750 kg/m³) |
| PP-Faser | 6–12 mm gehäckselt | ~200 g | Rissverhinderung bei Aushärtung |
| Puzzolanischer Zusatz | Vulkanasche / Reishülsenasche / Metakaolin | ~2 kg | pH-Senkung, Dauerhaftigkeit |

**Kalkputz und Kalkanstrich werden auf der Baustelle nach der Paneelinstallation aufgetragen — sie sind nicht Teil des Paneels selbst.**

---

## Materialdetails

### Strukturbambus

Das System verwendet gespaltene Struktur-Bambusstreifen als primäres Ausfachungsmaterial. Die Referenzart ist **Guadua angustifolia** (in Lateinamerika als *Guadua* bekannt, in Ecuador als *Caña Guadua*, in einigen Regionen als *Tacuara*) — der stärkste Strukturbambus Amerikas. Jedoch kann jede grosskalibrige Struktur-Bambusart angepasst werden.

Schlüsseleigenschaften von Guadua angustifolia:

- **Zugfestigkeit:** 150–200 MPa (vergleichbar mit Baustahl)
- **Wachstum:** Erreicht Erntedurchmesser (10–15 cm) in 4–5 Jahren
- **Verbreitung:** 0–2.000 m Höhe in den tropischen Amerikas (Kolumbien, Ecuador, Mittelamerika)
- **Ernte:** Schnitt nach 4–6 Jahren (maximale Lignifizierung). Jüngere Halme sind zu weich; ältere werden spröde.
- **Behandlung:** Boratlösung (Borax + Borsäure) nach modifizierter Boucherie-Methode oder Tauchen. Verhindert Insektenbefall und Pilzfäule. Ungiftig, wirksam für 20+ Jahre wenn in Mörtel eingebettet.

#### Alternativen für andere Regionen

| Art | Region | Anmerkungen |
|-----|---|---|
| *Dendrocalamus asper* | Südostasien | Grosser Durchmesser, stark. Direkter Ersatz. |
| *Bambusa bambos* | Süd-/Südostasien | Dornig, stark. Erfordert breitere Streifen. |
| *Phyllostachys edulis* (Moso) | China, gemässigte Zonen | Kleinerer Durchmesser. Breitere, dünnere Streifen verwenden. |
| *Phyllostachys bambusoides* | Japan, gemässigte Zonen | Gute Festigkeit. Kleinere Halme. |
| *Guadua chacoensis* | Argentinien, Paraguay | Naher Verwandter von G. angustifolia. |

Das System funktioniert mit jedem Strukturbambus, der in Streifen gespalten werden kann. Passen Sie Streifenbreite und -abstand an die verfügbare Art an.

### Stahl-L-Winkelrahmen

- **Profil:** L 40×40×4 mm gleichschenkliges Winkelprofil (ASTM A36 / ICONTEC NTC 2542)
- **Masse:** ~2,42 kg/m; Paneelrahmen total ~17 kg + ~4 kg Klemmleisten + ~1 kg Eckbleche/Verbindungselemente = **~22 kg pro Paneel**
- **Verzinkung:** Feuerverzinkt nach ISO 1461, mindestens 85 μm Zinkbeschichtung
- **Lebensdauer:** 80–100 Jahre in nicht-küstennahen tropischen Umgebungen bei der angegebenen Zinkdicke (der Paneeldienst ist innerhalb der alkalischen Mörtelmatrix kontinuierlich abgestützt, die freiliegenden Stahl selbst passiviert)
- **Beschaffung:** Massenartikel weltweit. In Kolumbien: Gerdau Diaco, Aceros Arequipa, Acesco, Ferrasa, Colmena/Sidenal, Perfilamos del Cauca. Lagerware in 6-m-Längen bei praktisch jedem Stahlbauhändler. Keine Sonderbestellung, keine Sonderanfertigung, keine asymmetrischen Stege
- **Alternative Profile:** L 50×50×4 oder L 50×50×5 (etwas schwerer, ebenfalls Lagerware) sind direkte Ersatzprofile. SHS (quadratisches Hohlprofil) 40×40×2 funktioniert strukturell ebenfalls, erfordert aber Klemmleisten, die geschweisst statt durch den Steg geschraubt werden
- **Warum nicht T-Profil:** Frühere Versionen dieses Dokuments spezifizierten T 60×60×7 mm (~45 kg pro Paneel). Kontinuierlich abgestützter Paneeldienst erfordert nicht den symmetrischen Steg des T-Profils — ein einseitiger L-Winkel-Steg ist strukturell gleichwertig bei etwa der halben Stahlmasse, halben Kosten und dramatisch besserer Verfügbarkeit. Offene T-Profile bleiben nur dort die richtige Wahl, wo Schwachachs-Knickwiderstand wichtig ist (z. B. freistehende Stützen — geschlossenes Vierkantrohr wird in diesem System bevorzugt gegenüber T-Profil).

### HDPE-Distanzblöcke

- **Quelle:** Recycelte HDPE-Schneidbretter, Rohrabschnitte oder Plattenmaterial
- **Eigenschaften:** Keine Wasseraufnahme, fäulnissicher, formstabil, leicht zu bearbeiten
- **Bearbeitung:** Tischkreissäge oder Bandsäge zum Zuschneiden. Oberfräse oder Stemmeisen für Eckkerben.

#### Alternativen zu HDPE

| Material | Vorteile | Nachteile |
|---|---|---|
| **Recyceltes HDPE** (bevorzugt) | Fäulnissicher, keine Wasseraufnahme, weit verbreitet aus Abfallstrom | Erfordert Schneidwerkzeuge |
| **Marine-Hartholz** (Teak, Ipe, Greenheart) | Stark, natürlich fäulnisbeständig, leicht zu bearbeiten | Teuer, degradiert dennoch über Jahrzehnte in feuchter Umgebung |
| **Behandeltes Weichholz** (CCA- oder Borat-behandelte Kiefer) | Günstig, weit verbreitet | Kürzere Lebensdauer (20–40 Jahre), muss evtl. ersetzt werden |
| **Dichte Gummiblöcke** (recycelter Reifengummi) | Fäulnissicher, stossabsorbierend, gratis aus Altreifen | Schwieriger präzise zu bearbeiten, kann sich über Zeit komprimieren |
| **Beton-/Mörtelblöcke** | Keine Kosten, in Formen gegossen, permanent | Spröde, schwieriger für Diagonalkerben, schwer |
| **3D-gedruckte Blöcke** (PETG oder ASA) | Präzise Geometrie inkl. Kerben, reproduzierbar | Erfordert 3D-Drucker, UV-Degradation bei Exposition |

Die kritische Anforderung ist: Der Block muss sein 30-mm-Mass über die Gebäudelebensdauer beibehalten, um das )( Streifenprofil zu erhalten. HDPE erfüllt dies am besten, aber jedes Material, das feuchtigkeits- und druckbeständig ist, funktioniert.

### Mörtel

- **Basismischung:** 1 Teil Portlandzement Typ I : 4 Teile sauberer Flusssand (gut abgestuft, 0–4 mm)
- **PP-Faser:** 200 g pro Paneel (~1 kg pro m³). Verhindert plastische Schwindrisse bei der Aushärtung.
- **Puzzolanischer Zusatz:** 5–10% Zementersatz.
  - **Vulkanasche** — verfügbar in Andenregionen, natürlich puzzolanisch
  - **Reishülsenasche (RHA)** — verfügbar in Reisanbaugebieten (Asien, Lateinamerika)
  - **Metakaolin** — verarbeiteter Kaolinton, weltweit verfügbar aber teurer
  - **Funktion:** Reagiert mit Calciumhydroxid im Zement, senkt den pH-Wert von ~12,5 auf ~10–11 über die Zeit. Dies verlangsamt den Abbau eingebetteter Guadua.
- **Wasser:** Sauber, trinkbar. W/Z-Wert ~0,45–0,50 für giessfähige Konsistenz auf dem Rütteltisch.

### Kalkputz (vor Ort)

- **Typ:** Hydraulischer Kalk (NHL 3.5 oder NHL 5) oder gelöschter Kalk (Sumpfkalk) + Sand
- **Mischung:** 1:2,5 bis 1:3 Kalk:Sand
- **Optionale Faser:** Gehäckseltes getrocknetes Gras (Sternengras, Sisal, Hanf) bei ~1 cm Länge. Erhöht Zugfestigkeit und Rissbeständigkeit. Natürliche Zellulose hält 30+ Jahre in Kalk (pH ~10, viel weniger aggressiv als Zement).
- **Auftrag:** Handgeglättet, 3–5 mm. Die Textur ist die Schönheit — maschinenperfekt ist nicht das Ziel.

### Kalkanstrich (vor Ort)

- Gelöschter Kalk + Wasser, mit Pinsel in dünnen Schichten aufgetragen
- Dringt ein und verbindet sich chemisch mit dem Kalkputz (Karbonatisierung)
- Alle 5–10 Jahre erneuern zur Instandhaltung
- Kann mit natürlichen Pigmenten (Erdoxiden) eingefärbt werden

### Hühnerdraht

- Verzinktes Sechseckgeflecht, 25 mm Maschenweite, 0,7–0,9 mm Draht
- Auf die Paneelfläche geklammert oder gebunden vor dem Mörtelauftrag
- Bietet mechanischen Verbund für Mörtelhaftung
- Beide Seiten

### Feines Aluminiumgitter (optional)

- Standard-Insekten-/Staubschutzgitter, 1–1,5 mm Maschenweite, Aluminium
- Unter dem Hühnerdraht auf beiden Seiten platziert
- Blockiert Insekten, Feinstaub und Pollen am Eindringen durch die Mörtelmatrix
- Als sekundäre Eigenschaft bietet es auch messbare Hochfrequenzdämpfung
- Nicht erforderlich für die strukturelle Funktion — je nach lokalen Insekten-/Staubverhältnissen hinzufügen

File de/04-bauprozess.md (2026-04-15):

# Bauprozess

> **SVG-Aktualisierung ausstehend:** Einige Diagramme in diesem Kapitel wurden für die frühere T-Profil-Rahmenspezifikation erzeugt und sind vorübergehend entkoppelt, bis sie für die aktuelle **L 40×40×4 mm Winkel**-Spezifikation neu erzeugt sind. Siehe [`SVG-STATUS.md`](../SVG-STATUS.md) im Repository-Stammverzeichnis.

## Werkstatteinrichtung

Alle Paneele werden in einer überdachten Werkstatt gebaut — wetterunabhängig, qualitätskontrolliert, fliessbandeffizient. Mindestanforderungen an die Werkstatt:

- Überdachte Fläche: ~6 × 4 m (Dach, offene Seiten akzeptabel)
- Schweissstation (nur für Rahmenfertigung)
- Ständerbohrmaschine oder Handbohrmaschine
- 2× Rütteltische (~1,2 × 2,7 m pro Stück) für das Werkstatt-Verguss-Produktionsmodell, **oder** Schalung + Vor-Ort-Mörtelpumpe für das bevorzugte Vor-Ort-Verguss-Modell (siehe [Paneelaufbau § Gewichtsaufschlüsselung](02-paneel-aufbau.md))
- Sandvorrat für Bett
- Mörtelmischer (elektrisch oder von Hand)
- Einfaches Handwerkzeug: Schraubenzieher, Drahtschneider, Zangen, Klammergerät

Montagesequenz

## Produktionsschritte

### Schritt 1: Rahmenfertigung

> _Wandpaneel-Rahmen-Diagramm ausstehend — die frühere Rahmen-SVG zeigt T-Profil-Geometrie und ist nicht repräsentativ für den L-Winkelrahmen. Siehe `SVG-STATUS.md`._

1. L 40×40×4 Winkel auf Länge schneiden: 2× 1,0 m (oben/unten) + 2× 2,5 m (Seiten). Lagermaterial von Gerdau Diaco / Acesco / Ferrasa, 6-m-Stangen
2. Ecken auf 45° auf Gehrung schneiden (oder gerade schneiden mit einem Schenkel über dem anderen — beides ergibt einen sauberen rechteckigen Rahmen)
3. Ecken in einer Lehre schweissen — alle Rahmen identisch. Optionale kleine Eckbleche (60×60×3 Blech) können über jede Innenecke geschweisst werden für Steifigkeit beim Handhaben
4. Klemmlöcher alle ~70 mm entlang der oberen und unteren Winkel-Stege bohren (eines pro zwei Bambusstreifen, ~14 Löcher pro Leiste, ~28 total)
5. Den fertigen Rahmen feuerverzinken (Chargenprozess — 20–50 Rahmen auf einmal versenden)

**Alle Rahmen sind identisch, unabhängig von der Paneelvariante.** Die Lehre gewährleistet konsistente Masse. Eine Lehre, ein Rahmen, für immer.

### Schritt 2: HDPE-Blöcke

1. HDPE-Material auf 30 × 30 mm × 1.000 mm zuschneiden (2 pro Paneel)
2. Eckkerben schneiden: 10 × 10 mm an jedem Ende (4 Kerben pro Block, 8 pro Paneel)
3. Blöcke auf obere und untere L-Winkel-Stege montieren mit Schrauben oder Klebstoff

### Schritt 3: Elektrik

1. 12V-Kabel durch PVC-Leerrohr führen
2. 120V-Kabel durch separates PVC-Leerrohr führen
3. E10-Fassungen montieren (3 nahe am oberen Rand, jede Seite)
4. Für Typ O/S: Steckdosendose montieren, Anschlusskabel zum Hauptkabel
5. Für Typ S: Schalterdose auf 120 cm Höhe montieren
6. Für Typ W: Wasser-Steigleitungen montieren (CPVC/PEX-Versorgung, PVC-Abfluss) mit verschlossenen Anschlussstutzen
7. Snap-Stecker an beiden Vertikalkanten anbringen (2-polig für 12V, 3-polig für 120V)

### Schritt 4: Bambusstreifen (Seite 1)

1. Paneelrahmen flach auf Arbeitstisch legen, Seite 1 nach oben
2. Vertikale Bambusstreifen gegen den Steg legen, zwischen den HDPE-Blöcken
3. ~20 mm Lücken zwischen den Streifen lassen für Mörteldurchdringung
4. PVC-Leerrohr mit Kabeln zwischen die Streifen legen, am Steg anliegend
5. Diagonalstreifen durch die untere linke HDPE-Kerbe fädeln, quer zur oberen rechten Kerbe (auf Steghöhe)
6. Diagonale vorspannen und an beiden Enden sichern

> _Schraubklemm-Diagramm ausstehend — die frühere Klemm-SVG zeigt T-Profil-Steggeometrie; das L-Winkel-Klemmdetail ist im Prinzip ähnlich (Klemmleiste → Bambus → Schraube durch Steg), aber geometrisch anders. Siehe `SVG-STATUS.md`._

### Schritt 5: Schraubklemmung (Seite 1)

1. Stahl-Klemmleiste (Flachstahl 3 mm × 40 mm × 1.000 mm) über die Bambusstreifen am oberen Winkel-Steg legen
2. Löcher in der Klemmleiste mit Löchern im L-Winkel-Steg ausrichten
3. Edelstahlschrauben eindrehen durch: Klemmleiste → Bambusstreifen → Steglöcher
4. Die Klemmleiste biegt sich, um natürliche Dickenvariation auszugleichen — selbstjustierend
5. Am unteren Winkel wiederholen
6. Diagonale an jeder Vertikalstreifen-Kreuzung mit Draht binden (~8–10 Bindungen)

**Zeit: ~5 Minuten pro Seite für die Klemmung, ~3 Minuten für die Drahtbindungen**

### Schritt 6: Wenden und wiederholen (Seite 2)

1. Paneel wenden
2. Schritte 4–5 auf der anderen Seite wiederholen
3. Diagonale auf Seite 2 verläuft von oben links nach unten rechts (gegenüber der Diagonalen auf Seite 1 — zusammen bilden sie ein X)

### Schritt 7: Gitter

1. Hühnerdraht über Seite 1 legen, 20 mm über den Rahmenrand hinausragend (für Überlappung mit benachbarten Paneelen)
2. Am Rahmen und an den Bambusstreifen klammern oder binden
3. Bei Verwendung von Aluminium-Insektengitter: unter dem Hühnerdraht platzieren
4. Wenden und auf Seite 2 wiederholen

### Schritt 8: Mörtelverguss

Mörtelverguss-Prozess

Dies ist die zentrale Innovation in der Anwendungsmethode:

1. **Rütteltisch vorbereiten:** Ebene Fläche, Motor darunter montiert
2. **Sandbett ausbreiten:** ~30 mm sauberer, trockener Sand auf der Tischfläche. Der Sand passt sich allen Unregelmässigkeiten der Paneelfläche an und verhindert das Anhaften des Mörtels am Tisch.
3. **Paneel mit der Vorderseite nach unten** auf das Sandbett legen (Hühnerdrahtseite berührt Sand)
4. **Mörtel mischen:** 1:4 Zement:Sand + PP-Faser + puzzolanischer Zusatz, W/Z ~0,45–0,50 (giessfähig aber nicht flüssig)
5. **Mörtel über die offene Rückseite** des Paneels giessen, Lücken zwischen Streifen füllen und das Gitter bedecken
6. **Vibration starten:** Tisch 30–60 Sekunden laufen lassen. Die Vibration:
   - Treibt Mörtel durch die Lücken zwischen den Streifen
   - Füllt den zentralen Hohlraum vollständig
   - Eliminiert Hohlräume und Lufteinschlüsse
   - Mörtel dringt bis zum Frontflächengitter vor (das jetzt auf Sand liegt)
7. **Abziehen** — überschüssigen Mörtel bündig mit den Rahmenkanten abstreichen
8. **Glätten** (dies wird die Innenseite)

> **Rütteltisch-Bauanleitung:** Eine DIY-Rütteltisch-Konstruktion (Motor, Plattform, Federn) wird in diesem Repository veröffentlicht, sobald das Design getestet und als sicher bestätigt wurde. Bis dahin funktioniert jede flache Plattform mit einem Betonrüttler, der an der Kante befestigt wird, für erste Versuche.

**Warum Rütteltisch auf Sandbett?**
- Schwerkraft + Vibration = vollständige Füllung, keine Hohlräume
- Sandbett = keine Form nötig, Sand passt sich der Paneelform an
- Keine Sprühausrüstung nötig (günstiger als Sprühmörtel)
- Einseitiger Verguss füllt beide Seiten — Mörtel fliesst durch die Streifenlücken
- Gleichbleibende Qualität — Vibration eliminiert menschliche Fehler

### Schritt 9: Aushärtung

1. Paneel mit Plastikfolie abdecken, um Feuchtigkeit zu halten
2. Mindestens 7 Tage feucht halten (Sprühnebel oder feuchte Jutesäcke)
3. Volle Festigkeit nach 28 Tagen
4. Paneele können nach 7 Tagen vertikal (hochkant) gestapelt werden, um Platz zu sparen
5. Jedes Paneel mit Variantentyp und Produktionsdatum beschriften

**Produktionsrate: 3–4 Paneele pro Tag** mit 2 parallel laufenden Rütteltischen, Team von 4–6 Personen. Aktive Arbeit pro Paneel: ~15–20 Minuten. Passive Aushärtung: 7–28 Tage (Paneele härten aus, während neue produziert werden).

### Schritt 10: Transport und Installation

1. Paneele zur Baustelle transportieren mittels einfachem A-Rahmen-Wagen oder Lastwagen
2. Paneele in den Stahlgebäuderahmen an den Stützenpositionen verschrauben (vorgeschweisste Schraubwinkel an Stützen)
3. Benachbarte Paneele berühren sich Mörtel an Mörtel
4. Snap-Connect-Elektrik zwischen benachbarten Paneelen verbinden (12V + 120V)
5. Stromkreise vor dem Verputzen testen

### Schritt 11: Fertigstellung vor Ort

1. Fugen zwischen Paneelen mit Mörtel füllen
2. Hühnerdrahtstreifen über Fugen anbringen (falls nicht bereits durch die Paneelränder überlappend)
3. Kalkputz auftragen: 3–5 mm, handgeglättet, beide Seiten
4. Aushärten lassen (3–5 Tage feucht halten)
5. Kalkanstrich auftragen: 2–3 dünne Schichten mit Pinsel

Die fertige Wand ist fugenlos — keine sichtbaren Fugen, kein sichtbarer Stahl, keine sichtbaren Schrauben. Nur glatter Kalkputz mit der Textur einer handgefertigten Wand.

### Schritt 12: Bad-Abdichtung

Bad- und Duschbereiche erfordern eine wasserdichte Behandlung anstelle von Kalkputz:

1. **Duschwände:** Flüssige Abdichtungsmembran (Sika-1 oder ähnlich) direkt auf die Mörtel-Paneelfläche auftragen — 2 Anstriche, mit Pinsel. Dann flexibler Fliesenkleber + Keramik-/Porzellanfliesen. **Kein Kalkputz im Duschbereich.**
2. **Badezimmerboden (gesamt):** Abdichtungsmembran auf der Plattenoberfläche + Keramikfliesen. Die Platte muss ein Gefälle von 2 % zum Bodenablauf aufweisen (während des Plattengusses geformt).
3. **Badezimmerwände ausserhalb der Dusche:** Kalkputz ist akzeptabel, oder Fliesen für leichte Reinigung.
4. **Decke (unter Galerie):** Kalkputz — nicht direkt besprüht.

Die Mörtel-Paneeloberfläche bietet ausgezeichnete Haftung für die Flüssigmembran — keine zusätzliche Vorbereitung nötig. Einfach die Paneelfläche reinigen und auftragen.

### Entwässerung (in der Platte geplant)

Alle Entwässerungen müssen VOR dem Guss der Fundamentplatte installiert werden:

- **Toilettenabfluss:** 4" (100 mm) PVC-Rohr zur Klärgrube. Position ist fix — kann später nicht verschoben werden.
- **Duschbodenablauf:** 2" (50 mm) PVC mit Geruchsverschluss. Platte im Duschbereich um ~20 mm vertieft, um Wasser zurückzuhalten.
- **Spülbeckenabflüsse:** 1,5" (40 mm) PVC mit Geruchsverschluss. Spülbecken Küche durch die Platte; Waschbecken Bad durch das W-Typ-Wasserpaneel oder die Platte.
- **Reinigungsöffnung:** Zugängliche Armatur ausserhalb des Gebäudes an der Abflussleitung.

Das W-Typ-Paneel liefert Versorgungs-Steigleitungen (warm/kalt CPVC). Entwässerung ist immer in der Platte — Schwerkraftentwässerung benötigt Gefälle, das Paneele nicht bieten können.

## Qualitätscheckliste

- [ ] Rahmenmasse innerhalb ±2 mm
- [ ] Alle Klemmlöcher gebohrt und ausgerichtet
- [ ] Bambusstreifen Borat-behandelt (grünlich/bläulicher Farbton sichtbar)
- [ ] Diagonale vorgespannt (sollte beim Klopfen klingen)
- [ ] Alle Drahtbindungen straff
- [ ] Elektrostromkreise vor Mörtelverguss getestet (12V und 120V)
- [ ] Mörtelkonsistenz korrekt (Setztest)
- [ ] Vibration volle 30–60 Sekunden gelaufen
- [ ] Keine sichtbaren Hohlräume auf der Vergussseite nach Vibration
- [ ] Paneel mit Typ und Datum beschriftet
- [ ] Mindestens 7 Tage ausgehärtet vor Handhabung

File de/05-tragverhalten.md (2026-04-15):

# Tragverhalten

## Systemarchitektur

Dieses Paneelsystem wurde für die Zusammenarbeit **mit einem Stahl-Stützen-Riegel-Rahmen** konzipiert — die Konfiguration, die wir für mehrstöckige Gebäude in Erdbebenzonen empfehlen. In dieser Konfiguration übernimmt der Stahlrahmen die Schwerkraft- und seismischen Lasten, während die Paneele seitliche Aussteifung, Wetterschutz, thermische Masse und integrierte Installationen liefern.

Die Paneele sind jedoch **strukturell in der Lage, ohne Stahlrahmen zu funktionieren**. Mit einer Drucktragfähigkeit, die typische Wohnlasten weit übersteigt (zwei seitliche L-Winkel-Posten L 40×40×4), kann eine Paneelreihe bequem ein Obergeschoss und Dach tragen, ohne eine unabhängige Stahlstruktur. Ein einfacher Holz- oder Bambus-Ringbalken am oberen Rand verbindet die Paneele und verteilt die Dachlast.

**Zwei Konfigurationen:**

| Konfiguration | Einsatzbereich | Rolle der Paneele |
|---|---|---|
| **Mit Stahlrahmen** (empfohlen) | Mehrstöckig, hohe Erdbebenzonen, Gewerbe/Institutionen | Ausfachung — Paneele werden in den Rahmen geschraubt, Stahl trägt Primärlasten |
| **Ohne Stahlrahmen** (einfacher, kostengünstiger) | Eingeschossig + Galerie/Zwischengeschoss, moderate Erdbebenzonen, Wohnbau | Tragend — Paneele tragen Dach und Obergeschoss direkt |

Die folgenden Tragfähigkeitsschätzungen gelten für beide Konfigurationen. Der Stahlrahmen fügt Redundanz und Biegesteifigkeit hinzu, ist aber nicht erforderlich, damit die Paneele strukturell funktionieren.

## Seismisches Verhalten

### Diagonalverstrebung

Jedes Paneel enthält zwei diagonale Bambusstreifen (einen pro Seite, gegenüberliegende Ecken), die von vorne betrachtet ein X bilden. Unter seismischer Belastung:

1. **Schub → Zug-Umwandlung:** Wenn sich der Gebäuderahmen seitlich verformt, gerät eine Diagonale auf Zug, während die gegenüberliegende auf Druck beansprucht wird. Die Bambusdiagonale auf Zug widersteht der Schubkraft effizient — Bambus hat eine ausgezeichnete Zugfestigkeit (150–200 MPa für Guadua angustifolia).
2. **Vorspannung:** Diagonalen werden mit leichter Vorspannung eingebaut, wodurch Schlaffheit eliminiert und sofortige Lastabtragung gewährleistet wird.
3. **Drahtbindungsgitter:** Verzinkte Drahtbindungen an jeder Diagonal-Vertikal-Kreuzung (~16–20 Bindungen total) verteilen die Diagonalkraft über die gesamte Paneelfläche und verhindern lokales Versagen.

**Geschätzte Verbesserung: 3–5× Schubsteifigkeit** im Vergleich zu Paneelen ohne Diagonalverstrebung.

### Das )( Profil

Die HDPE-Blöcke halten die Bambusstreifen oben und unten 30 mm vom Steg entfernt. Auf halber Höhe biegen sich die Streifen nach innen zum Steg. Der Mörtel füllt diesen variierenden Spalt und erzeugt einen natürlichen Bogenquerschnitt:

- **Widerstand gegen Kräfte senkrecht zur Wandebene:** Der Mörtelbogen wirkt wie ein flaches Gewölbe und verteilt Wind- oder Stossbelastungen effizient auf die steifen Rahmenkanten.
- **Mechanische Verzahnung:** Der Mörtel mit variabler Dicke verriegelt die Bambusstreifen — sie können nicht herausgezogen werden, ohne den Mörtel zu brechen.

### Duktiles Versagensverhalten

Die Kombination aus Bambusstreifen, Drahtbindungen und Mörtel erzeugt einen Verbundwerkstoff, der schrittweise versagt:

1. Zuerst: Mörtel reisst (sichtbare Warnung)
2. Dann: Drahtbindungen dehnen sich (Energieabsorption)
3. Dann: Bambusstreifen verformen sich (hohe Duktilität)
4. Der Stahlrahmen bleibt durchgehend intakt — das Gebäude stürzt nicht ein

Dies unterscheidet sich grundlegend von unbewehrtem Mauerwerk, das spröde versagt (plötzlicher Einsturz ohne Vorwarnung).

## Brandwiderstand

- **Mörtelummantelung:** Die Bambusstreifen sind vollständig in Mörtel eingebettet (~85 mm Wanddicke). Mörtel ist nicht brennbar und wirkt als Wärmeisolierung für den Bambus.
- **Bambusverkohlung:** Selbst wenn Feuer den Mörtel durchdringt, verkohlt Bambus langsam und vorhersagbar (ähnlich wie Holzbau). Der dahinterliegende Stahlrahmen behält seine strukturelle Integrität.
- **Kalkputz-Finish:** Nicht brennbar. Bietet zusätzlichen Brandschutz.
- **Kein freiliegender Bambus:** Nach Installation und Verputzen ist kein Bambus sichtbar oder für Flammen zugänglich.

## Thermisches Verhalten

- **Thermische Masse:** ~85 mm Mörtel bieten erhebliche thermische Masse — absorbiert tagsüber Wärme, gibt sie nachts ab. Reduziert Temperaturschwankungen in tropischen Klimazonen.
- **Atmungsaktivität:** Kalkputz ist dampfdiffusionsoffen. Feuchtigkeit durchdringt die Wand, statt eingeschlossen zu werden, was Kondenswasser und Schimmel verhindert.
- **Keine Dämmschicht:** Das System enthält keine thermische Dämmschicht. In tropischen Klimazonen (dem primären Zielgebiet) ist thermische Masse wertvoller als Dämmung. Für gemässigte Klimazonen kann eine äussere Dämmschicht ausserhalb des Kalkputzes hinzugefügt werden.

## Akustisches Verhalten

Der dichte Mörtelkern bietet gute Schalldämmung:

- **Geschätzter STC (Sound Transmission Class):** 40–45 für eine einzelne Paneelwand
- **Mit Kalkputz auf beiden Seiten:** STC 42–48
- **Vergleich:** Standard-Betonblockwand: STC 40–45. Das Paneelsystem ist vergleichbar.

## Tragfähigkeit

> **Haftungsausschluss:** Die untenstehenden Werte sind konservative analytische Schätzungen basierend auf Materialeigenschaften und Geometrie. Sie basieren NICHT auf Labortests. Verwenden Sie diese Werte nicht für die Tragwerksplanung ohne unabhängige Überprüfung. Die tatsächliche Leistung hängt von Materialqualität, Verarbeitungsqualität und Anschlussdetails ab. Siehe [Erforderliche Tests](#erforderliche-tests) weiter unten.

### Paneeleigengewicht

| Komponente | Gewicht |
|---|---|
| Stahl-L-Winkelrahmen (L 40×40×4, 7 m bei 2,42 kg/m + Klemmleisten + Eckbleche) | ~22 kg |
| Mörtel-Kernfüllung (Basis: Zement-Sand, ~0,147 m³, ausgehärtete Dichte ~2 000 kg/m³) | ~294 kg |
| Bambusstreifen + Diagonalen (~30 % Hohlraumdichte) | ~38 kg |
| HDPE-Blöcke, Draht, Gitter, Leerrohr, Kabel | ~6 kg |
| Kalkputz (10 mm beidseitig) | ~100 kg |
| **Gesamtgewicht Paneel, Basismischung** | **~460 kg** |
| **Gewicht pro m² Wand, Basis** | **~184 kg/m²** |
| Gesamtgewicht Paneel, optimierte Bahareque-Mischung (puzzolanischer Kalk + Pasto estrella + 5 mm Putz) | ~380 kg |
| Gewicht pro m² Wand, optimiert | ~152 kg/m² |
| Trockenmontage-Versandgewicht (Rahmen + Bambus + Gitter + Installationen, vor dem Mörtelguss) | ~75 kg |

Zum Vergleich: 150 mm Betonblockwand ≈ 180 kg/m². Das Paneelsystem (Basismischung) ist etwa gleich schwer wie konventionelles Mauerwerk pro Flächeneinheit, die optimierte Bahareque-Mischung etwa 15 % leichter. Entscheidend für die Logistik: das **Trockenmontage-Versandgewicht (~75 kg)** ist die Form, in der das Paneel von der Werkstatt zur Baustelle transportiert wird (Mörtel wird vor Ort gegossen).

### Axiale (vertikale) Last

Jedes Paneel hat zwei vertikale seitliche L-Winkel-Posten, die erhebliche Drucklasten tragen können:

| Element | Querschnitt | Konservative axiale Tragfähigkeit |
|---|---|---|
| Seitlicher L-Winkel-Posten (L 40×40×4 mm) | A ≈ 304 mm² | ~36 kN pro Posten (bei σ = 120 MPa, ~50 % der A36-Fliessgrenze) |
| Zwei seitliche Posten pro Paneel | 2 × 304 mm² | ~72 kN pro Paneel (~7 200 kg) |

**Was das in der Praxis bedeutet:**

Ein typisches eingeschossiges Haus mit Galerie/Zwischengeschoss und Dachziegeldach erzeugt ungefähr 200–400 kg Last pro Laufmeter Wand (Dach + Decke + Zwischengeschossdecke + Nutzlast). Ein einzelnes 1-m-Paneel kann das **18–36-Fache** dieses Bedarfs tragen. **Die Paneele benötigen keinen separaten Stahlrahmen, um ein Obergeschoss und Dach zu tragen.**

Bei Verwendung **mit Stahlrahmen** ist diese axiale Tragfähigkeit reine Sicherheitsreserve — der Stahl trägt die Schwerkraftlasten. Bei Verwendung **ohne Stahlrahmen** sind die Paneele die tragende Struktur. In diesem Fall verteilt ein Holz- oder Bambus-Ringbalken am oberen Wandrand die Dachlast gleichmässig über alle Paneele und verbindet sie miteinander.

Knicken ist bei diesen Laststufen kein Problem **wenn der L-Winkel im Paneelverbund eingebettet ist**: Die 85 mm Mörtelwanddicke bietet dem Winkelrahmen kontinuierliche Seitensteifigkeit, und das Verhältnis von Paneelhöhe zu Wanddicke (~2 500/85 ≈ 29) liegt deutlich innerhalb akzeptierter Schlankheitsgrenzen für bewehrte Wände.

**Wichtig: Schwachachs-Limitation offener Profile.** Offene Strukturprofile — L-Winkel, T-Profile, C-Profile — haben minimale Steifigkeit um ihre Schwachachse. Ein freistehender L 40×40×4 Posten ohne Paneelabstützung (I_min ≈ 3,8 × 10⁴ mm⁴ um die Schwachachse durch die Ferse) würde unter mässiger Last knicken. Die oben angegebene Tragfähigkeit von 36 kN pro L-Winkel ist die **axiale Fliessgrenze** und ist NUR erreichbar, wenn der Winkel kontinuierlich durch die Paneelfüllung (Mörtel + Guadua) abgestützt wird. Diese Unterscheidung ist entscheidend für die Bauablauffolge — der L-Winkelrahmen darf nicht axial belastet werden, bevor die Paneele gegossen, ausgehärtet sind und die Verbundlast tragen. Für freistehende Stützen in mehrgeschossigen Gebäuden sind offene Profile nicht geeignet — verwenden Sie stattdessen quadratisches Hohlprofil (SHS).

### Laterale (horizontale / Schub-) Last

Dies ist der primäre strukturelle Beitrag der Paneele — der Widerstand gegen horizontale Kräfte aus Wind und Erdbeben.

**Ohne Diagonalverstrebung (nur Mörtel + Vertikalstreifen):**

Konservative Schätzung basierend auf der Mörtelschubfestigkeit (τ ≈ 0,3 MPa für 1:4 Zement:Sand-Mörtel) über den Paneelquerschnitt:

- Schubfläche: ~85 mm × 1.000 mm = 85.000 mm²
- Konservative Schubtragfähigkeit: 85.000 × 0,3 = ~25 kN pro Paneel
- Mit Sicherheitsfaktor 3: **~8 kN Gebrauchslast pro Paneel**

**Mit Diagonalverstrebung (die ausgelegte Konfiguration):**

Der diagonale Bambusstreifen (60 × 20 mm, Guadua angustifolia) auf Zug:

- Querschnitt: 1.200 mm²
- Konservative Zugfestigkeit: 80 MPa (bei ~50% der publizierten 150–200 MPa)
- Diagonale Zugtragfähigkeit: 1.200 × 80 = ~96 kN
- Horizontalkomponente (cos 69°): ~96 × 0,36 = ~34 kN pro Diagonale
- Zwei Diagonalen (eine pro Seite, eine auf Zug): ~34 kN
- Drahtbindungen und Mörtelverzahnung liefern zusätzlichen Widerstand
- Mit Sicherheitsfaktor 3: **~12–15 kN Gebrauchsschublast pro Paneel**

**Im Kontext:** Ein 3 m breiter Wandabschnitt (3 Paneele) liefert ~36–45 kN Schubwiderstand. Ein eingeschossiges Wohngebäude in einer moderaten Erdbebenzone (PGA 0,2g) mit 30 kN seismischer Masse über der Wand benötigt ungefähr 6 kN Fundamentschubwiderstand pro Laufmeter Wand. Drei Paneele pro Meter liefern das 4–5-Fache dieses Bedarfs.

Dies sind sehr konservative Zahlen. Die Mörtelmatrix, das Drahtbindungsgitter und das )( Profil tragen alle zusätzlichen Widerstand bei, der oben nicht berücksichtigt wurde.

### Querlast (Wind / Stoss)

Das Paneel widersteht Druck senkrecht zur Wandfläche (Windsog/-druck, Stoss):

- Der durch das )( Profil erzeugte Mörtelbogen wirkt als flaches Gewölbe zwischen den steifen oberen und unteren L-Winkeln
- Konservative Schätzung für gleichmässigen Winddruck, wobei das Paneel als einseitig eingespannte Platte behandelt wird:

| Parameter | Wert |
|---|---|
| Paneelspannweite (zwischen oberem/unterem L-Winkel) | 2,5 m |
| Paneelbreite | 1,0 m |
| Mörteldicke (Minimum, in der Mitte) | ~55 mm |
| Mörtelbiegezugfestigkeit (konservativ) | 1,0 MPa |
| Geschätzte gleichmässige Drucktragfähigkeit | ~0,7 kPa |
| Mit Sicherheitsfaktor 2 | **~0,35 kPa Gebrauchslast** |

**Im Kontext:** 0,35 kPa ≈ Windgeschwindigkeit ~25 m/s (90 km/h). Für höhere Windzonen übernimmt der Stahlrahmen (nicht das Paneel) die Windlast über die Riegel-Stützen-Verbindungen. Das Paneel muss nur den lokalen Druck zwischen seinen eigenen Rahmenelementen aufnehmen.

Das Bambusstreifen-Gitter und die Drahtbindungen bieten erheblichen zusätzlichen Querlastwiderstand, der im einfachen Plattenmodell nicht erfasst wird — das Paneel ist ein Verbundwerkstoff, keine reine Mörtelplatte.

### Punktlasten (Einrichtungsgegenstände, Regale, Schränke)

| Befestigungsart | Ankermethode | Konservative Tragfähigkeit |
|---|---|---|
| Leichte Gegenstände (Bilder, Uhren, Handtuchhaken) | Mauernagel oder Schraube in Mörtel | 5–10 kg pro Anker |
| Mittlere Gegenstände (Regale, Spiegel, kleine Schränke) | Kunststoff-Spreizdübel in Mörtel (6–8 mm) | 15–25 kg pro Anker |
| Schwere Gegenstände (Küchenschränke, Warmwasserspeicher, TV-Halterung) | Durchgangsschraube zum L-Winkel-Steg | 50–100 kg pro Anker |
| Sehr schwere Gegenstände (Bücherregal, voller Vorratsschrank) | Mehrere Durchgangsschrauben zum L-Winkel + Verteilplatte | 200+ kg pro Befestigungspunkt |

**Tipp:** Der L-Winkel-Steg verläuft an einer bekannten Position (entlang einer Paneelseite, in der Wandtiefe). Balkensucher oder Magnet lokalisieren ihn leicht. Durchgangsschrauben zum Steg bieten zuverlässige, hochbelastbare Verankerung, vergleichbar mit Stahlständer-Rahmenbau.

### Zusammenfassung — Konservative Tragfähigkeit in kg pro Paneel

Für Bauherren und Nicht-Ingenieure hier dieselben Zahlen in Kilogramm. Dies sind **sehr konservative Gebrauchslasten** (bereits durch Sicherheitsfaktoren von 2–3 geteilt). Die tatsächlichen Bruchlasten liegen 2–3× höher.

| Lastart | Richtung | Konservative Gebrauchslast | Was das in der Praxis bedeutet |
|---|---|---|---|
| **Schub (Erdbeben/Wind)** | Horizontal, in der Wandebene | **~1.200–1.500 kg pro Paneel** | Eine horizontale Kraft von 1,2–1,5 Tonnen am oberen Rand eines einzelnen Paneels, bevor es als an der Gebrauchsgrenze betrachtet werden sollte. Ein typisches eingeschossiges Haus benötigt ~600 kg Schubwiderstand pro Laufmeter Wand — ein Paneel liefert das 2-Fache davon. |
| **Querlast (Winddruck)** | Senkrecht zur Wandfläche | **~90 kg verteilt über die Paneelfläche** | Entspricht ~36 kg/m² gleichmässigem Druck. Eine sich stark gegen die Wand lehnende Person (~80 kg auf ~0,3 m²) liegt deutlich innerhalb der Kapazität. |
| **Axial (vertikal)** | Abwärts, durch das Paneel | **Übertrifft Wohnlasten weit (~7 200 kg axiale Fliessgrenze pro Paneel im Verbund)** | Die zwei seitlichen L-Winkel tragen weit mehr als ein typisches Dach + Obergeschoss pro Laufmeter Wand. Paneele können ein Obergeschoss und Dach ohne separaten Stahlrahmen tragen. |
| **Punktlast auf Mörtel** | Auszug / Abscheren am Anker | **~15–25 kg pro Anker** | Ein Regalbrett mit 2 Ankern hält 30–50 kg sicher. |
| **Punktlast auf L-Winkel** | Durchgangsschraube | **~50–100 kg pro Schraube** | Ein Küchenschrank mit 4 Durchgangsschrauben hält 200–400 kg sicher. |

> **Wichtig:** Dies sind Schätzungen, keine geprüften Werte. Sie werden durch physische Tests validiert. Verwenden Sie sie nicht für die Tragwerksplanung ohne unabhängige Überprüfung. Im Zweifelsfall schwere Gegenstände am Stahlgebäuderahmen befestigen, nicht am Paneel.

## Dauerhaftigkeit (80–100 Jahre Auslegungslebensdauer)

| Komponente | Abbauprozess | Prävention | Erwartete Lebensdauer |
|---|---|---|---|
| Stahlrahmen | Korrosion | Feuerverzinkung (85 μm+) | 80–100 Jahre (nicht küstennah) |
| Bambusstreifen | Insektenbefall, Pilzfäule | Boratbehandlung + Mörtelummantelung (alkalisch, anaerob) | 80+ Jahre |
| Mörtel | Karbonatisierung, Verwitterung | Geschützt durch Kalkputz (Opferschicht) | 100+ Jahre |
| Kalkputz | Oberflächenerosion, Mikrorisse | Selbstheilung (Karbonatisierung füllt Risse), erneuerbarer Kalkanstrich | Unbegrenzt bei Instandhaltung |
| Kalkanstrich | UV-Abbau, Regenerosion | Alle 5–10 Jahre erneuern | 5–10 Jahre pro Anstrich |
| Elektrik | Isolationsabbau | PVC-Leerrohr ermöglicht Kabelaustausch ohne Wandöffnung | Kabel: 30–50 Jahre, austauschbar |
| HDPE-Blöcke | Keine nennenswerten | UV-geschützt (innerhalb der Wand) | 100+ Jahre |

### Instandhaltungsplan

| Intervall | Massnahme | Geschätzte Kosten |
|---|---|---|
| Alle 5–10 Jahre | Kalkanstrich erneuern | 50–100 $ pro Gebäude |
| Alle 15–20 Jahre | Kalkputz inspizieren, Risse ausbessern | 100–300 $ pro Gebäude |
| Alle 30–40 Jahre | Elektrik inspizieren, Kabel bei Bedarf ersetzen | 200–500 $ pro Gebäude |
| Nach 40 Jahren | Stahlrahmen an zugänglichen Stellen inspizieren (bei Bedarf punktuell nachverzinken) | 200–400 $ |
| **Lebensdauer total** | | **1.400–2.000 $** |

## Erforderliche Tests

**Alle oben genannten Tragfähigkeitswerte sind analytische Schätzungen.** Sie werden durch physische Tests im Rahmen der Projektentwicklung validiert. Die ersten Paneele werden gebaut und getestet, bevor ein Gebäude bezogen wird.

Geplantes Testprogramm:

- [ ] **Schubtests** (ASTM E564 oder gleichwertig) — Paneele mit und ohne Diagonalen, zur Validierung der geschätzten 3–5× Verbesserung
- [ ] **Querbelastungstests** — gleichmässiger Druck und Punktstoss, zur Validierung des )( Profil-Vorteils
- [ ] **Brandwiderstandstests** (ASTM E119 oder gleichwertig) — Zeit bis zum Tragversagen
- [ ] **Zyklische Erdbebentests** — massstäblicher Rütteltisch oder quasi-statische zyklische Belastung, zur Überprüfung des duktilen Versagensverhaltens
- [ ] **Verbindungstests** — Paneel-zu-Stützen-Schraubwinkel-Tragfähigkeit, Snap-Stecker-Dauerhaftigkeit
- [ ] **Langzeit-Verwitterungstests** — beschleunigte Alterung von mörtelummantelten Bambusproben
- [ ] **Schalldämmungstests** (ASTM E90) — STC-Messung
- [ ] **Punktlast-Auszugstests** — Mauerwerksanker- und Durchgangsschrauben-Tragfähigkeit in Mörtel + L-Winkel

Testergebnisse werden in diesem Repository veröffentlicht, sobald sie vorliegen. Wenn Sie Zugang zu Prüfeinrichtungen haben und beitragen möchten, melden Sie sich bitte — gemeinschaftliches Testen mit verschiedenen Bambusarten und Mörtelmischungen macht dieses System für alle besser.

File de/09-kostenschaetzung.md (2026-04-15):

# Kostenschätzung

> **Haftungsausschluss:** Dies sind reine Materialkostenschätzungen, basierend auf Preisen von 2025 in Kolumbien (Region Eje Cafetero). Arbeitskosten sind nicht enthalten — das System ist für Gemeinschaftsproduktion konzipiert, bei der Arbeit beigetragen, nicht gekauft wird. Die Preise variieren erheblich nach Region, Währung und Lieferkette. Verwenden Sie diese als Ausgangspunkt, nicht als Budget.

In diesem Projekt werden zwei Mörtelmischungen dokumentiert: die **Basismischung** (Zement-Sand-Mörtel + 30 % Guadua-Anteil + 10 mm Kalkputz beidseitig) und die **optimierte Bahareque-Mischung** (puzzolanischer Kalk + Pasto-estrella-Fasern + 30 % Guadua + 5 mm Kalkputz). Beide Kostenaufstellungen sind unten gezeigt.

## Kosten pro Paneel — Basismischung (nur Material)

| Material | Spezifikation | Menge pro Paneel | Stückpreis (USD) | Total (USD) |
|---|---|---|---|---|
| L-Winkelstahl | L 40×40×4 mm, ASTM A36 | 7,0 m | 4,00 $/m | 28,00 $ |
| Verzinkung | Feuerverzinkt, Chargenprozess | 1 Rahmen | 2,00 $ | 2,00 $ |
| Klemmleisten | 40×3 mm Flachstahl, verzinkt | 4,0 m | 1,00 $/m | 4,00 $ |
| Eckbleche + Schrauben | Flachblech + M12/M8 | 1 Set | 3,00 $ | 3,00 $ |
| Edelstahlschrauben | Selbstschneidend, A2 | 40 Stk. | 0,08 $ | 3,20 $ |
| HDPE-Blöcke | Recycelt, 30×30 mm | 2,0 m | 1,50 $/m | 3,00 $ |
| Bambusstreifen (vertikal + horizontal, 30 % Hohlraumdichte) | Borat-behandelte Guadua | ~400 m total | 0,05 $/m | 20,00 $ |
| Bambusstreifen (diagonal) | 60×20 mm, behandelt | ~5,4 m | 0,30 $/m | 1,60 $ |
| Drahtbindungen | Verzinkt | 5 m | 0,10 $/m | 0,50 $ |
| PVC-Leerrohr | 16 mm Elektro | 5 m | 0,30 $/m | 1,50 $ |
| 12V-Kabel + Fassungen | 2-adrig + 6× E10 | 1 Set | 3,00 $ | 3,00 $ |
| 120V-Kabel + Stecker | 3-adrig + Snap-Stecker | 1 Set | 4,00 $ | 4,00 $ |
| Hühnerdrahtgeflecht | Verzinktes Sechseck, 25 mm | 5,5 m² | 0,80 $/m² | 4,40 $ |
| Zement | Portland Typ I | ~54 kg | 0,15 $/kg | 8,10 $ |
| Sand (Mörtel) | Sauberer Flusssand | ~240 kg | 0,02 $/kg | 4,80 $ |
| PP-Faser | Gehäckselt 6–12 mm | 200 g | 5,00 $/kg | 1,00 $ |
| Puzzolanischer Zusatz | Vulkanasche oder RHA | 2 kg | 0,50 $/kg | 1,00 $ |
| **Paneel-Zwischensumme — Basis** | | | | **~93 $** |

### Fertigstellung vor Ort, Basis (pro Paneelfläche)

| Material | Menge pro Paneel | Kosten (USD) |
|---|---|---|
| Kalkputz (10 mm beidseitig) | ~25 kg Kalk + ~65 kg Sand | 6,50 $ |
| Kalkanstrich (beidseitig) | ~2 kg Kalk | 0,50 $ |
| **Fertigstellung Zwischensumme — Basis** | | **7,00 $** |

### **Gesamte Materialkosten pro Paneel — Basis: ~100 USD**

### Kosten pro m² fertige Wand — Basis

- Paneelfläche: 1,0 m × 2,5 m = 2,5 m²
- Materialkosten pro m²: **~40 USD/m²**

## Kosten pro Paneel — optimierte Bahareque-Mischung (nur Material)

Die optimierte Mischung ersetzt Portland-Zement-Sand-Mörtel durch hydraulischen Kalk + Puzzolan, ersetzt PP-Faser durch Pasto-estrella (gratis, vor Ort gesammelt) und verwendet dünneren 5 mm Kalkputz. Gleicher L-Winkelrahmen, gleicher Bambusanteil, gleiche elektrische und tragende Komponenten.

| Material | Spezifikation | Menge pro Paneel | Stückpreis (USD) | Total (USD) |
|---|---|---|---|---|
| L-Winkelstahl + Verzinkung + Klemmleisten + Eckbleche | (wie Basis) | | | 37,20 $ |
| Edelstahlschrauben, HDPE, Bambus, Drahtbindungen, Leerrohr, Kabel, Geflecht | (wie Basis) | | | 41,20 $ |
| Hydraulischer Kalk (Hauptbindemittel) | NHL 3.5 oder NHL 5 | ~42 kg | 0,30 $/kg | 12,60 $ |
| Flugasche oder Reishülsenasche (Puzzolan, 30 % Zement-Äquivalent) | FA oder RHA | ~15 kg | 0,10 $/kg | 1,50 $ |
| Sand (Mörtel) | Sauberer Flusssand | ~200 kg | 0,02 $/kg | 4,00 $ |
| Pasto-estrella-Faser (getrocknetes Sterngras) | Vor Ort gesammelt | ~3 kg | gratis | 0,00 $ |
| **Paneel-Zwischensumme — optimiert** | | | | **~96 $** |

### Fertigstellung vor Ort, optimiert (pro Paneelfläche)

| Material | Menge pro Paneel | Kosten (USD) |
|---|---|---|
| Kalkputz (5 mm beidseitig) | ~12 kg Kalk + ~33 kg Sand | 3,30 $ |
| Kalkanstrich (beidseitig) | ~2 kg Kalk | 0,50 $ |
| **Fertigstellung Zwischensumme — optimiert** | | **3,80 $** |

### **Gesamte Materialkosten pro Paneel — optimiert: ~100 USD**

### Kosten pro m² fertige Wand — optimiert

- Materialkosten pro m²: **~40 USD/m²**

> **Beide Mischungen liegen materialkostenmässig etwa gleich** (~100 $/Paneel, ~40 $/m²). Die optimierte Mischung tauscht leicht höhere Kalk-/Puzzolan-Zutatenkosten (gegenüber günstigerem Portlandzement) gegen niedrigere Kalkputzkosten (dünner), null PP-Faserkosten und deutlich geringere graue CO₂-Emissionen (siehe [Umweltbilanz](10-umweltbilanz.md)). Die optimierte Mischung ist daher ein **klarer Gewinn bei CO₂ und Heritage-Authentizität bei praktisch gleichen Kosten**.

## Vergleich mit konventioneller Bauweise

| Wandsystem | Materialkosten pro m² (USD) | Lebensdauer | Anmerkungen |
|---|---|---|---|
| **Dieses Paneelsystem — Basis** | **~40 $** | **80–100 Jahre** | Beinhaltet Tragstruktur, Elektrik, Finish |
| **Dieses Paneelsystem — optimiert** | **~40 $** | **80–100 Jahre** | Gleicher Preis, weniger CO₂ |
| Betonblock (15 cm) | 25–35 $ | 40–60 Jahre | Erfordert Bewehrung, Verguss, Putz, Farbe, separate Elektrik |
| Gebrannter Ziegel | 30–45 $ | 60–80 Jahre | Erfordert Mörtel, Putz, Farbe, separate Elektrik |
| Gipskarton auf Stahlständern | 20–30 $ | 20–30 Jahre | Keine thermische Masse, nicht tragend, erfordert Farbe, separate Elektrik |
| Konventioneller Bahareque (vor Ort) | 15–25 $ | 15–30 Jahre | Keine Elektrik, Oberflächenqualität variabel, kurze Lebensdauer ohne Ingenieurberechnung |
| Adobe-Block | 10–20 $ | 20–40 Jahre | Schlechtes Erdbebenverhalten, keine Elektrik, erfordert dicke Wände |

**Zentrale Erkenntnis:** Das Paneelsystem kostet pro m² etwa **20–35 % mehr als Betonblock** — beinhaltet aber integrierte Elektrik, hat die 1,5–2-fache Lebensdauer, bietet bessere thermische und akustische Leistung und erzeugt eine hochwertigere Oberfläche. Wenn man die Kosten für die separate Verkabelung eines Betonblockhauses einrechnet (~8–15 $/m² für Leerrohre, Kabel, Steckdosen und deren Installationsarbeit), ist das Paneelsystem auf Basis vollständig-fertige-Wand-bezugsbereit kostenwettbewerbsfähig.

## Kosten pro Haus (Grobschätzung)

Ein einfaches eingeschossiges Haus mit Galerie (50 m² Grundfläche, ~70 m² Nutzfläche inkl. Galerie):

| Komponente | Menge | Kosten (USD) |
|---|---|---|
| Wandpaneele | ~40 Paneele (100 m² Wand) | 2.600–2.800 $ |
| Fundament (Beton, Bewehrung) | ~5 m³ Beton | 800–1.200 $ |
| Ringbalken (Holz/Bambus) | ~30 m | 200–400 $ |
| Dach (Dachziegel + Pfetten) | ~65 m² | 1.200–1.800 $ |
| Boden (Betonplatte oder Lehm) | ~50 m² | 400–800 $ |
| Fenster + Türen | ~8 Öffnungen | 600–1.200 $ |
| Elektroverteilung + Transformator | 1 Set | 200–400 $ |
| Sanitär (einfach) | Küche + Bad | 300–600 $ |
| **Material total** | | **6.300–9.200 $** |

Dies sind reine Materialkosten. Im Gemeinschaftsbau-Modell wird Arbeit beigetragen. Im Unternehmermodell kommen 40–60% für Arbeit hinzu.

**Zum Vergleich:** Ein vergleichbares Betonblockhaus im ländlichen Kolumbien kostet 12.000–20.000 $ (Material + Arbeit) und hält 40–60 Jahre. Dieses System erreicht vergleichbare oder bessere Qualität zu ungefähr der Hälfte der Kosten bei doppelter Lebensdauer.

## Strategien zur Kostenreduktion

| Strategie | Einsparung | Anmerkungen |
|---|---|---|
| Eigenen Bambus ernten | 30–40% der Bambuskosten | Erfordert 1+ Hektar Guadua-Bestand, 4–5 Jahre Reife |
| HDPE aus Abfall recyceln | 100% der HDPE-Kosten | Schneidbretter, Rohrreste, Industrieabfall |
| Vulkanasche verwenden (gratis) | 100% der Puzzolankosten | Verfügbar in Andenregionen, sammeln und sieben |
| Sternengras-Faser statt PP | 100% der Faserkosten | Invasives Gras, gratis, zirkuläre Nutzung |
| Chargen-Verzinkung (50+ Rahmen) | 15–20% der Verzinkungskosten | Mengenrabatt vom Verzinkungswerk |
| Gemeinschafts-Sandgrube | 50–80% der Sandkosten | Falls lokaler Flusssandzugang verfügbar |
| Eigenen Kalk aus Kalkstein brennen | 50–70% der Kalkkosten | Erfordert Ofen (einmaliger Bau), lokaler Kalkstein |

## Regionale Preisunterschiede

Materialkosten variieren stark nach Region. Die obigen Schätzungen gelten für Kolumbien. Grobe Multiplikatoren:

| Region | Multiplikator | Anmerkungen |
|---|---|---|
| Kolumbien (Eje Cafetero) | 1,0× (Referenz) | Guadua reichlich, Vulkanasche verfügbar |
| Ecuador, Peru | 0,8–1,1× | Ähnliche Materialien, Caña Guadua verfügbar |
| Mittelamerika | 1,0–1,3× | Bambus verfügbar, Stahl evtl. teurer |
| Philippinen, Indonesien | 0,7–1,0× | Bambus reichlich und günstig, Arbeit sehr günstig |
| Indien | 0,6–0,9× | Bambus und Arbeit sehr günstig, Stahl erschwinglich |
| Subsahara-Afrika | 0,8–1,2× | Bambusarten variieren, Zement evtl. teuer |
| Südeuropa | 2,0–3,0× | Materialien verfügbar aber teurer |

Diese Multiplikatoren sind grobe Richtwerte. Die grösste Einzelvariable sind die Bambuskosten — wenn Sie Ihren eigenen anbauen, ist er nahezu gratis.

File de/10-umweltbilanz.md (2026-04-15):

# Umweltbilanz

## CO₂-Fussabdruck pro Paneel — Basismischung

Die Werte unten beziehen sich auf die aktuelle Basisspezifikation: L 40×40×4 Stahlrahmen + 30 % Guadua-Hohlraumanteil + Zement-Sand-Mörtel (Basis) + 10 mm Kalkputz beidseitig. Siehe [Paneelaufbau](02-paneel-aufbau.md) und [Materialien](03-materialien.md) für Details.

| Material | Menge pro Paneel | Gebundenes CO₂ (kg) | Emissionsquelle |
|---|---|---|---|
| Portlandzement (~18 % der Mörtelmasse) | ~54 kg | 43,2 | Kalzinierung + Brennstoff (~0,8 kg CO₂/kg Zement) |
| Stahl L-Winkelrahmen + Klemmleisten | ~22 kg Stahl | 39,6 | Stahlherstellung (~1,8 kg CO₂/kg Stahl) |
| Verzinkung (Zink) | ~0,7 kg Zink | 2,8 | Zinkverhüttung (~4 kg CO₂/kg Zink) |
| Sand (~82 % der Mörtelmasse) | ~240 kg | 1,2 | Gewinnung + Transport |
| Hühnerdraht + Aluminiumgitter | ~2 kg | 3,6 | Stahldrahtproduktion |
| PVC-Leerrohr | ~0,3 kg | 0,6 | PVC-Herstellung (~2 kg CO₂/kg) |
| Kabel + Stecker | ~0,5 kg | 1,5 | Kupfer + Kunststoff |
| HDPE-Blöcke | ~0,5 kg | 0,5 | Bei Recycling: ~1 kg CO₂/kg (vs. 3 für Neuware) |
| Kalk (im Putz, Kalzinierung) | ~22 kg Kalk | 18,0 | Kalkstein-Kalzinierung (~0,8 kg CO₂/kg Kalk) |
| PP-Faser (Mörtelzusatz) | ~0,2 kg | 0,4 | Polypropylen-Herstellung |
| **Zwischensumme Emissionen** | | **~111 kg CO₂** | |
| Bambus (beim Wachstum gespeicherter Kohlenstoff) | ~38 kg Trockengewicht (30 % Hohlraumanteil) | **−60 bis −75 kg CO₂** | Bambus bindet ~1,6–2,0 kg CO₂ pro kg Trockenmasse |
| Kalkputz (absorbiert CO₂ bei Karbonatisierung) | ~22 kg Kalk | **−6 bis −9 kg CO₂** | Kalkkarbonatisierung erfasst ~30–50 % des Kalzinierungs-CO₂ über Jahrzehnte zurück |
| **Netto-CO₂ pro Paneel, Basismischung** | | **~30–45 kg CO₂** | |
| **Netto-CO₂ pro m² Wand, Basis** | | **~12–18 kg CO₂/m²** | |

## CO₂-Fussabdruck pro Paneel — optimierte Bahareque-Mischung

Die optimierte Mischung (puzzolanischer Kalk + Pasto-estrella + 30 % Guadua + 5 mm Putz) liefert geringere graue CO₂-Emissionen über mehrere Hebel:

| Hebel | CO₂-Differenz pro Paneel gegenüber Basis |
|---|---|
| 30 % Zement durch Flugasche oder RHA-Puzzolan ersetzen | −10 bis −13 kg |
| Portlandzement-Mörtel durch hydraulische Kalkbasis + Puzzolan ersetzen | −8 bis −12 kg |
| PP-Faser durch Pasto estrella (Sterngras) ersetzen | −0,5 kg |
| Dünnerer 5 mm Kalkputz beidseitig (−50 % Kalkvolumen) | −9 kg Kalzinierung, +4 kg geringere Karbonatisierungsrückgewinnung = **−5 kg netto** |
| **Gesamtreduktion** | **−24 bis −30 kg CO₂ pro Paneel** |
| **Netto-CO₂ pro Paneel, optimierte Mischung** | **~6 bis 20 kg CO₂** |
| **Netto-CO₂ pro m² Wand, optimiert** | **~3 bis 8 kg CO₂/m²** |

Mit lokal verfügbaren Puzzolanen (Vulkanasche in der kolumbianischen Kaffeeregion, Reishülsenasche aus Tolima/Valle del Cauca) und Pasto-estrella-Faser vom Grundstück selbst nähert sich die optimierte Bahareque-Mischung der **Klimaneutralität** pro Paneel. Wenn der Bambusbestand als bewirtschaftete CO₂-Senke geführt wird (Niederwaldrotation mit Biomasse-Permanenz), wird das System **CO₂-negativ**: Die Wand absorbiert über ihre Lebensdauer mehr CO₂ als beim Bau emittiert wurde.

## Vergleich mit konventionellen Wandsystemen

| Wandsystem | kg CO₂ pro m² | Verhältnis zu Basis-Paneel |
|---|---|---|
| **Dieses Paneelsystem — Basismischung** | **12–18** | **1× (Referenz)** |
| **Dieses Paneelsystem — optimierte Bahareque-Mischung** | **3–8** | **~0,4× Basis** |
| Betonblock (15 cm, verputzt) | 40–60 | 3–4× Basis |
| Gebrannter Ziegel (verputzt) | 50–80 | 3–5× Basis |
| Stahlbetonwand (15 cm) | 70–100 | 5–7× Basis |
| Gipskarton auf Stahlständern | 15–25 | 1–1,5× Basis |
| Konventioneller Bahareque (Lehmputz, kein Stahlrahmen) | 3–8 | 0,3–0,5× Basis |
| Adobe-Block | 5–10 | 0,4–0,7× Basis |

Die Basismischung des Paneelsystems erzeugt **~3× weniger CO₂ als Betonblock oder Ziegel** — die beiden häufigsten Wandmaterialien in Entwicklungsländern. Die optimierte Bahareque-Mischung erreicht das Niveau traditioneller Erdbauweise bei weit überlegener struktureller Leistung und Lebensdauer.

## Kohlenstoff pro Nutzungsjahr

Wenn die Lebensdauer einbezogen wird, wird der Vergleich noch deutlicher (bei 80–100 Jahren Auslegungslebensdauer für dieses System):

| Wandsystem | kg CO₂/m² | Lebensdauer (Jahre) | kg CO₂/m²/Jahr |
|---|---|---|---|
| **Dieses Paneelsystem — Basis** | 15 | 90 | **0,17** |
| **Dieses Paneelsystem — optimiert** | 5 | 90 | **0,06** |
| Betonblock | 50 | 50 | 1,00 |
| Gebrannter Ziegel | 65 | 70 | 0,93 |
| Gipskarton auf Stahlständern | 20 | 25 | 0,80 |
| Konventioneller Bahareque | 5 | 20 | 0,25 |

**Über seine Lebensdauer erzeugt dieses Paneelsystem ~5–15× weniger Kohlenstoff pro Nutzungsjahr als Betonblock.**

## Weg zur Klimaneutralität oder CO₂-Negativität

Das Paneelsystem ist bereits in der Basis kohlenstoffarm. Mit der optimierten Bahareque-Mischung und den folgenden weiteren Substitutionen wird es **CO₂-negativ**:

| Substitution | CO₂-Einsparung pro Paneel | Machbarkeit |
|---|---|---|
| Puzzolanischen Kalkmörtel verwenden (optimierte Mischung) | −20 bis −25 kg | Kernspezifikation — siehe oben |
| Recycelten Stahl verwenden (Elektrolichtbogenofen) | −8 bis −12 kg | Abhängig von lokaler Stahl-Lieferkette |
| Bambusanteil weiter erhöhen (45 % Hohlraum) | −5 bis −8 kg zusätzliche Sequestrierung | Material ist gratis/günstig |
| Bio-Kalk verwenden (holzbefeuerter Ofen mit Niederwald-Brennstoff) | −5 kg | Traditionelle Kalkproduktionsmethode |
| Dünnerer Putz (5 mm → 3 mm) | −5 kg | Traditionelle Bahareque-Praxis |
| **Gesamtes Reduktionspotenzial über das Optimierte hinaus** | **−43 bis −55 kg** | |

Bei maximaler Reduktion sinkt das Netto-CO₂ pro Paneel in den Bereich **−5 bis +5 kg** — klimaneutral bis leicht negativ. Wenn der Bambusbestand als permanente CO₂-Senke bewirtschaftet wird, ist das System über seine Nutzungsdauer zuverlässig **CO₂-negativ**.

## Wasserverbrauch

- **Mörtelmischung:** ~15–20 Liter pro Paneel (Aushärtungswasser wo möglich wiederverwendet)
- **Aushärtung:** ~50 Liter über 7 Tage (Sprühnebel-/Jutemethode)
- **Kalkputzmischung:** ~10 Liter pro Paneel
- **Total:** ~75–80 Liter pro Paneel, oder ~30 Liter pro m² Wand

Zum Vergleich: Betonblockproduktion verbraucht ~40–50 Liter pro m² Wand. Ziegelproduktion verbraucht ~100+ Liter pro m² (inklusive Ofenkühlung).

## Abfall

- **Stahlabschnitte:** Recycelt (Schrottwert)
- **Bambusabschnitte:** Kompostiert oder als Gartenstäbe/Mulch verwendet
- **Mörtelabfall:** Minimal — Rütteltisch-Verguss ist präzise. Überschuss wird im nächsten Paneel wiederverwendet.
- **Sandbett:** Unbegrenzt wiederverwendbar (Sand wird nicht verbraucht, nur verdichtet und gelockert)
- **HDPE-Abschnitte:** Recycelt oder für kleinere Blöcke wiederverwendet
- **Verpackungsabfall:** Minimal — die meisten Materialien kommen in Grossgebinden

Das System erzeugt **nahezu keinen Bauabfall**. Dies ist eine direkte Folge der Werkstatt-Vorfertigung — jeder Schnitt ist geplant, jedes Material ist abgemessen.

## Lebensende (nach 80–100 Jahren)

Wenn ein Paneel schliesslich das Ende seiner Lebensdauer erreicht:

| Material | Entsorgung | Umweltauswirkung |
|---|---|---|
| Stahlrahmen | Recyceln (100% recycelbar) | Positiv — Stahlschrott hat Wert |
| Mörtel + Bambus | Zerkleinern und als Zuschlag oder Füllmaterial verwenden | Inert — Mörtel ist Kalzium/Silizium/Sand, Bambus ist organisch |
| Kalkputz | Kehrt zu Kalziumkarbonat (Kalkstein) zurück | Klimaneutral — das bei der Karbonatisierung absorbierte CO₂ wird wieder freigesetzt, netto null |
| HDPE-Blöcke | Recyceln | Recycelbar |
| Kupferkabel | Recyceln (hoher Schrottwert) | Positiv |
| PVC-Leerrohr | Recyceln wo Anlagen vorhanden | Prinzipiell recycelbar |

**Kein Sondermüll.** Kein Asbest, keine Bleifarbe, kein synthetischer Isolierschaum, keine Druckimprägnierungschemikalien. Das Paneel besteht aus Stahl, Bambus, Sand, Zement und Kalk — es kehrt sauber in die Erde oder den Recyclingkreislauf zurück.

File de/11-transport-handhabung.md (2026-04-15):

# Transport und Handhabung

## Paneelspezifikationen für die Handhabung

| Eigenschaft | Wert |
|---|---|
| Masse | 1,0 m × 2,5 m × 85 mm |
| Trockenmontage-Gewicht (wie zur Baustelle geliefert) | **~75 kg** |
| Fertiges Paneelgewicht (Basismischung, nach Vor-Ort-Verguss + Aushärtung + Putz) | ~440 kg |
| Fertiges Paneelgewicht (optimierte Bahareque-Mischung) | ~360 kg |
| Schwerpunkt | Mitte (symmetrische Bauweise) |
| Empfindliche Bereiche | Ecken, Kanten (Mörtel kann nach dem Verguss bei Stoss abplatzen) |
| Mindest-Aushärtung vor Handhabung | 7 Tage nach Vor-Ort-Verguss |
| Mindest-Aushärtung vor Installation | 14 Tage empfohlen — Hinweis: Beim Vor-Ort-Verguss-Modell wird das Paneel aufgestellt und der Mörtel an Ort und Stelle gegossen, sodass „Installation" und „Verguss" auf der Baustelle gemeinsam stattfinden, nicht nacheinander |

## Primäres Produktionsmodell: Vor-Ort-Verguss

**Das primäre Produktionsmodell ist, die Trockenmontage (~75 kg) zur Baustelle zu liefern und den Mörtel vor Ort gegen Schalung zu giessen.** Das fertige ~440 kg Paneel wird nie als Einheit bewegt — es wird direkt Teil der Gebäudewand, was die Kosten für schwere Hebezeuge spart und das Transport-Risskrisiko eliminiert. Siehe [Bauprozess](04-bauprozess.md) für das vertikale Vor-Ort-Verguss-Protokoll.

Die Handhabung ausgehärteter Paneele (Abschnitte unten) gilt für das alternative Produktionsmodell: Werkstatt-Mörtelverguss auf einem Rütteltisch, mit vollständig ausgehärteten Paneelen, die als fertige Elemente zur Baustelle geliefert werden. Dieser Ansatz wird als dokumentierte Option für Bauherren beibehalten, die die Werkstattproduktion bevorzugen, fügt aber erheblichen Hebe-, Transport- und Ausschussraten-Aufwand hinzu.

## Tragen von Hand — Trockenmontage (~75 kg)

Die Trockenmontage (Stahl-L-Winkelrahmen + Bambus-Esterilla + Gitter + Installationen, vor dem Mörtel) wird von **2 Personen mit einem einfachen Gurtband** angehoben und positioniert. Keine Tragelehre, kein Kran, kein Gabelstapler erforderlich — dies ist einer der zentralen Betriebsvorteile des Vor-Ort-Verguss-Produktionsmodells.

### Einfaches Gurtband-Tragen (Trockenmontage)

1. Ein einzelnes 50 mm × 500+ kg belastbares Gurtband um das trockene Paneel auf halber Höhe wickeln (~125 cm vom unteren Rand)
2. Jeder Träger greift ein Ende des Gurtbands mit beiden Händen, auf gegenüberliegenden Längsseiten des Paneels stehend
3. Gemeinsam anheben; das Paneel hängt vertikal zwischen ihnen
4. Im normalen Tempo gehen; das Paneel kann 30–50 m getragen werden, bevor eine Pause nötig ist

**Gewicht pro Person: ~38 kg** — vollständig handhabbar für die Kurzdistanz-Transporte, die typisch sind für Werkstatt-zu-Lastwagen, Lastwagen-zu-Baustellenlager und Lager-zu-Installation.

## Tragen von Hand — ausgehärtetes fertiges Paneel (alternatives Werkstatt-Verguss-Modell)

Ein fertiges Paneel mit ~360–440 kg **kann nicht von Hand getragen werden**. Es erfordert mechanisches Heben (Kettenzug, Kompaktlader oder kleiner Mobilkran). Dies ist der Hauptgrund, warum das Vor-Ort-Verguss-Modell bevorzugt wird.

Wenn werkstattgegossene Paneele bewegt werden müssen (z. B. Pilotphasen-Produktion bevor das Vor-Ort-Protokoll validiert ist), verwenden Sie:

### Einfache Tragelehre (ausgehärtetes Paneel, ~360–440 kg)

Zwei Bambusstangen (3 m lang, 8–10 cm Durchmesser), durch Schlaufen aus schwerem Gurtband gefädelt, das um das Paneel auf 1/4 und 3/4 Höhe gewickelt ist:

1. Paneel flach hinlegen
2. Zwei Gurtbänder (50 mm breit, belastbar 1 000+ kg) um das Paneel wickeln bei ~60 cm und ~190 cm vom unteren Rand
3. Auf jeder Seite eine Bambusstange durch beide Gurtschlaufen fädeln
4. **4 Personen pro Stange, insgesamt 8 Träger** für ein Paneel mit Basismischung bei ~440 kg, oder 6 Träger für ein Paneel mit optimierter Mischung bei ~360 kg
5. Paneel hängt vertikal zwischen den Stangen

**Gewicht pro Person: ~55 kg (Basis) / ~45 kg (optimiert)** — am oberen Rand der sicheren manuellen Handhabung. Lange Strecken oder Treppen sollten stattdessen mechanisches Heben verwenden.

Für jeden routinemässigen Produktionsablauf **Gabelstapler, Kompaktlader oder Kettenzug statt manuellem Tragen** für ausgehärtete Paneele verwenden. Manuelles Tragen ausgehärteter Paneele ist nur eine Notfall-/Pilotoption.

### Anheben und Kippen

- **Ein Paneel niemals an einer Kante anheben** — der Mörtel kann unter Eigengewicht reissen, wenn er frei auskragt
- **Immer an zwei symmetrischen Punkten anheben**, oder von unten mit Abstützung an der Rückseite
- **Kippen von flach zu vertikal:** Zwei Personen halten die Oberkante, zwei heben die Unterkante. Langsam drehen. Unterkante während des Drehens auf einem gepolsterten Block abstützen.

## Werkstattlagerung

Nach der Aushärtung werden Paneele **vertikal (hochkant)** in einem A-Rahmen-Gestell gelagert:

- Paneele gegen beide Seiten eines Winkelrahmens lehnen (wie ein offenes Buch)
- 10–15 Paneele pro Gestellseite
- Paneele mit kleinen Holzdistanzstücken trennen für Luftzirkulation
- Mit Plane oder Dach vor direktem Regen schützen (aushärtender Mörtel kann durch starken Regen vor vollständiger Aushärtung ausgewaschen werden)
- Vom Boden fernhalten — untere Kante auf Kies oder Holzschiene stellen

**Platzbedarf:** ~3 m × 1 m Grundfläche pro 20–30 gelagerte Paneele.

## Lastwagentransport

### Beladen

1. Paneele vertikal im Laderaum aufstellen, an eine Seitenwand gelehnt
2. Holzdistanzstücke (Abschnitte, Bambus oder Schaumstoff) zwischen jedes Paneel legen
3. Paneele mit Ratschengurten an der Lastwagen-Seitenwand befestigen auf 1/3 und 2/3 Höhe
4. Paneele niemals flach aufeinander stapeln — das unterste Paneel bricht unter dem Gewicht des Stapels
5. Maximal ~15–20 Paneele pro Standard-Pickup (abhängig von Ladekapazität und Strassenverhältnissen)

### Strassenverhältnisse

- **Befestigte Strassen:** Keine besonderen Vorsichtsmassnahmen ausser Gurten
- **Unbefestigte/raue Strassen:** Geschwindigkeit reduzieren. Schaumstoff- oder Kartonpolster zwischen die Paneele legen. Fest gurten — Paneele können verrutschen und bei Stössen Kanten abplatzen.
- **Steile Steigungen:** Sicherstellen, dass Paneele zum Hang geneigt sind (nicht davon weg), um Umkippen zu verhindern
- **Distanz:** Keine Begrenzung. Paneele sind vollständig ausgehärtet und selbsttragend. Sie können jede Distanz transportiert werden.

### Entladen

1. Gurte von oben nach unten lösen
2. Zwei Personen pro Paneel — eine an der Oberkante, eine stützt die Unterkante
3. Jedes Paneel zum A-Rahmen-Lagergestell auf der Baustelle tragen
4. Paneele niemals fallen lassen oder schleifen — Mörtelkanten platzen leicht ab

## Kran / Hebezeug (für Obergeschosse)

Für zweigeschossige Gebäude müssen Paneele ins Obergeschoss gehoben werden:

- **Einfacher Mastbaum:** Eine Bambus- oder Stahlstange mit Seil und Rolle. Zwei Personen ziehen das Seil, eine führt das Paneel. Funktioniert für geringe Mengen.
- **Kettenzug am Riegel:** Einen **1 000 kg** Kettenzug am Stahlriegel des Gebäudes befestigen (500-kg-Kettenzüge reichen für ausgehärtete Paneele nicht aus). Am Traggurt des Paneels einhaken. Eine Person bedient, eine führt. Schnell und kontrolliert. Für Trockenmontage-Hübe (~75 kg) reicht ein 500-kg-Kettenzug reichlich.
- **Gabelstapler (falls verfügbar):** Gabel unter das Paneel (mit Karton geschützt). Anheben und direkt in Position setzen.

**Paneele nicht werfen, rollen oder schleifen.** Der Mörtel ist stark auf Druck, kann aber bei Punktbelastung reissen.

## Schäden und Reparatur

| Schadensart | Ursache | Reparatur |
|---|---|---|
| Eckabplatzung (klein) | Stoss beim Transport | Mit Mörtel füllen, überputzen. Nur kosmetisch. |
| Kantenriss (oberflächlich) | Anstossen bei Handhabung | Mit Kalkputz füllen. Beeinträchtigt Struktur nicht. |
| Durchgehender Riss (Mörtel) | Fallenlassen oder schwerer Stoss | Paneel evtl. beeinträchtigt. Prüfen: Wenn Stahlrahmen intakt und Riss <2 mm, mit Mörtel füllen und beobachten. Wenn Riss >5 mm oder Rahmen verbogen, Paneel ablehnen. |
| Gebrochener Snap-Stecker | Verhaken beim Transport | Stecker ersetzen (gelötet oder gecrimpt). |

**Ausschussrate:** Bei vernünftiger Sorgfalt ist mit <5% beschädigten Paneelen bei Transport und Handhabung zu rechnen, und <1% müssen abgelehnt werden. Abgelehnte Paneele können von Elektrokomponenten befreit und als Füllmaterial recycelt werden.

## Checkliste vor Transport

- [ ] Paneel mindestens 7 Tage ausgehärtet (14 empfohlen)
- [ ] Paneel mit Typ (P/O/S/W) und Produktionsdatum beschriftet
- [ ] Elektrostromkreise getestet (12V + 120V Durchgangsprüfung)
- [ ] Keine sichtbaren Risse >1 mm
- [ ] Ecken intakt
- [ ] Tragehilfen oder Tragelehre vorbereitet
- [ ] Laderaum sauber, Distanzstücke bereit, Gurte verfügbar
- [ ] Route geprüft auf Strassenverhältnisse (Brücken, Durchfahrtshöhe, Steigung)

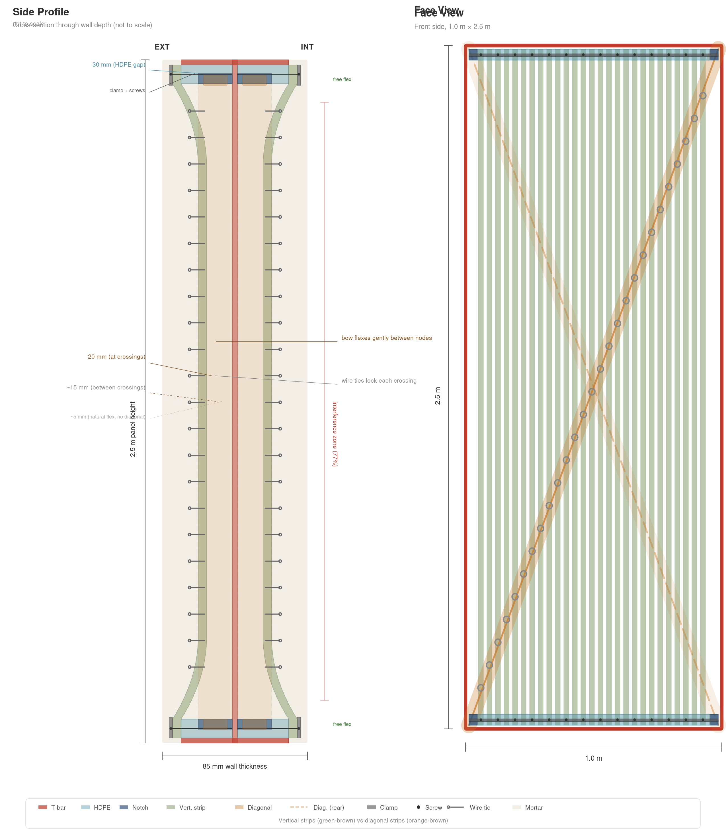
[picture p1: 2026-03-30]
svg/11-combined-profile-face.png

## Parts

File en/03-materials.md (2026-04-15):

# Materials

## Bill of Materials (per panel)

| Material | Specification | Quantity | Notes |
|---|---|---|---|
| L-angle steel | L 40×40×4 mm, hot-dip galvanized (ASTM A36 / ICONTEC NTC 2542 equivalent) | 2× 1.0 m + 2× 2.5 m = 7.0 m | Commodity Colombian stock (Gerdau Diaco, Aceros Arequipa, Acesco, Ferrasa). 6 m standard lengths, cut with chop saw |
| Clamping strips | 2 mm flat steel, galvanized, matching holes | 4× 1.0 m = 4.0 m | Top + bottom, both sides |
| Screws | Stainless steel, self-tapping | ~28 per panel | Through clamping strip → bamboo → HDPE → web (every ~70 mm, one per two strips) |
| HDPE blocks | 30×30 mm cross-section, recycled | 2× 1.0 m = 2.0 m | Top + bottom T-bars |
| Bamboo strips (vertical) | Borate-treated, ~20 mm wide | ~54 strips × 2.5 m | ~27 per side |
| Bamboo strip (diagonal) | Borate-treated, 60×20 mm | 2× ~2.69 m | 1 per side, opposing corners |
| Galvanized wire | Tie wire | ~5 m | ~16–20 ties at crossings |
| PVC conduit | 16 mm electrical | ~5 m | Cable protection |
| 12V cable | 2-core | ~6 m | Lighting circuit |
| 120V cable | 3-core (L+N+G) | ~6 m | Mains circuit |
| E10 sockets | Screw-base lamp holders | 6 | 3 per side |
| Snap connectors | 2-pin (12V) + 3-pin (120V) | 2 + 2 | Both vertical edges |
| Chicken wire | Galvanized hex mesh, 25 mm | ~5.5 m² | Both faces + overlap |
| Cement mortar (baseline) | 1:4 cement:sand + additives | ~0.147 m³ net cavity (after 30 % guadua + steel displacement) | ~310 kg wet / ~294 kg cured (density ~2 000 kg/m³) |
| Pozzolanic lime mortar with pasto estrella (optimized) | Hydraulic lime + 30 % fly ash/RHA + pasto estrella fibers | ~0.147 m³ same cavity | ~270 kg wet / ~257 kg cured (density ~1 750 kg/m³) |
| PP fiber | 6–12 mm chopped | ~200 g | Curing crack prevention |
| Pozzolanic admixture | Volcanic ash / rice husk ash / metakaolin | ~2 kg | pH reduction, durability |

**Lime plaster and lime wash are applied on-site after panel installation — not part of the panel itself.**

---

## Material Details

### Structural Bamboo

The system uses split structural bamboo strips as the primary infill material. The reference species is **Guadua angustifolia** (known as *guadua* across Latin America, *caña guadua* in Ecuador, *tacuara* in some regions) — the strongest structural bamboo in the Americas. However, any large-diameter structural bamboo species can be adapted.

Key properties of Guadua angustifolia:

- **Tensile strength:** 150–200 MPa (comparable to mild steel)
- **Growth:** Reaches harvest diameter (10–15 cm) in 4–5 years
- **Range:** 0–2,000 m altitude across tropical Americas (Colombia, Ecuador, Central America)
- **Harvest:** Cut at 4–6 years (maximum lignification). Younger culms are too soft; older ones become brittle.
- **Treatment:** Borate solution (borax + boric acid) by modified Boucherie method or soaking. Prevents insect attack and fungal decay. Non-toxic, effective for 20+ years when encased in mortar.

#### Alternatives for Other Regions

| Species | Region | Notes |
|---|---|---|
| *Dendrocalamus asper* | Southeast Asia | Large diameter, strong. Direct substitute. |
| *Bambusa bambos* | South/Southeast Asia | Thorny, strong. Requires wider strips. |
| *Phyllostachys edulis* (Moso) | China, temperate zones | Smaller diameter. Use wider, thinner strips. |
| *Phyllostachys bambusoides* | Japan, temperate zones | Good strength. Smaller culms. |
| *Guadua chacoensis* | Argentina, Paraguay | Close relative of G. angustifolia. |

The system works with any structural bamboo that can be split into strips. Adjust strip width and spacing for the available species.

### Steel L-angle frame

- **Profile:** L 40×40×4 mm equal-leg angle (ASTM A36 / ICONTEC NTC 2542)
- **Mass:** ~2.42 kg/m; panel frame total ~17 kg + ~4 kg clamping strips + ~1 kg gussets/fasteners = **~22 kg per panel**
- **Galvanizing:** Hot-dip per ISO 1461, minimum 85 μm zinc coating
- **Lifespan:** 80–100 years in non-coastal tropical environments at the specified zinc thickness (panel service is continuously braced within the alkaline mortar matrix, which self-passivates exposed steel)
- **Sourcing:** Commodity item worldwide. In Colombia: Gerdau Diaco, Aceros Arequipa, Acesco, Ferrasa, Colmena/Sidenal, Perfilamos del Cauca. Stocked in 6 m lengths at virtually every structural steel supplier. No special order, no custom fabrication, no asymmetric webs
- **Alternative profiles:** L 50×50×4 or L 50×50×5 (slightly heavier, also commodity stock) are drop-in substitutes. SHS (square hollow section) 40×40×2 also works structurally but requires clamping strips to be welded rather than screwed through the web
- **Why not T-bar:** earlier versions of this document spec'd T 60×60×7 mm (~45 kg per panel). Continuously-braced panel service does not require the T-profile's symmetric web — a single-sided L-angle web is structurally equivalent at roughly half the steel mass, half the cost, and dramatically better availability. Open T-profiles remain the correct choice only where weak-axis buckling resistance matters (e.g. freestanding columns — closed square tube is preferred over T-profile in this system).

### HDPE Spacer Blocks

- **Source:** Recycled HDPE cutting boards, pipe sections, or sheet stock
- **Properties:** Zero water absorption, rot-proof, dimensionally stable, easy to machine
- **Machining:** Table saw or band saw to cut to size. Router or chisel for corner notches.

#### Alternatives to HDPE

| Material | Pros | Cons |
|---|---|---|
| **Recycled HDPE** (preferred) | Rot-proof, zero water absorption, widely available from waste stream | Requires cutting tools |
| **Marine-grade hardwood** (teak, ipe, greenheart) | Strong, naturally rot-resistant, easy to machine | Expensive, still degrades over decades in moist environments |
| **Treated softwood** (CCA or borate-treated pine) | Cheap, widely available | Shorter lifespan (20–40 years), may need replacement |
| **Dense rubber blocks** (recycled tire rubber) | Rot-proof, shock-absorbing, free from waste tires | Harder to machine precisely, may compress over time |
| **Concrete/mortar blocks** | Zero cost, cast in molds, permanent | Brittle, harder to notch for diagonals, heavy |
| **3D-printed blocks** (PETG or ASA) | Precise geometry including notches, reproducible | Requires 3D printer, UV degradation if exposed |

The critical requirement is: the block must maintain its 30 mm dimension over the building's lifetime to preserve the )( strip profile. HDPE meets this best, but any material that resists moisture and compression will work.

### Mortar

- **Base mix:** 1 part Portland cement Type I : 4 parts clean river sand (well-graded, 0–4 mm)
- **PP fiber:** 200 g per panel (~1 kg per m³). Prevents plastic shrinkage cracks during curing.
- **Pozzolanic admixture:** 5–10% cement replacement.
  - **Volcanic ash** — available in Andean regions, naturally pozzolanic
  - **Rice husk ash (RHA)** — available in rice-growing regions (Asia, Latin America)
  - **Metakaolin** — processed kaolin clay, available globally but more expensive
  - **Function:** Reacts with calcium hydroxide in cement, reducing pH from ~12.5 to ~10–11 over time. This slows degradation of embedded guadua.
- **Water:** Clean, potable. W/C ratio ~0.45–0.50 for pourable consistency on vibration table.

### Lime Plaster (on-site)

- **Type:** Hydraulic lime (NHL 3.5 or NHL 5) or slaked lime (putty lime) + sand
- **Mix:** 1:2.5 to 1:3 lime:sand
- **Optional fiber:** Chopped dried grass (star grass, sisal, hemp) at ~1 cm length. Adds tensile strength and crack resistance. Natural cellulose lasts 30+ years in lime (pH ~10, much less aggressive than cement).
- **Application:** Hand-troweled, 3–5 mm. The texture is the beauty — machine-perfect is not the goal.

### Lime Wash (on-site)

- Slaked lime + water, brush-applied in thin coats
- Penetrates and bonds chemically with lime plaster (carbonation)
- Reapply every 5–10 years for maintenance
- Can be tinted with natural pigments (earth oxides) for color

### Chicken Wire

- Galvanized hexagonal mesh, 25 mm opening, 0.7–0.9 mm wire
- Stapled or tied to panel face before mortar application
- Provides mechanical key for mortar adhesion
- Both faces

### Fine Aluminum Mesh (optional)

- Standard insect/dust screen, 1–1.5 mm opening, aluminum
- Placed under chicken wire on both faces
- Blocks insects, fine dust, and pollen from entering through the mortar matrix
- As a secondary property, also provides measurable radio-frequency attenuation
- Not required for structural function — add based on local insect/dust conditions

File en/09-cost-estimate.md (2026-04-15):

# Cost Estimate

> **Disclaimer:** These are material cost estimates only, based on 2025 prices in Colombia (Eje Cafetero region). Labor is not included — the system is designed for community production where labor is contributed, not purchased. Prices vary significantly by region, currency, and supply chain. Use these as a starting point, not a budget.

Two mortar-mix specifications are documented throughout this project: the **baseline mix** (cement-sand mortar + 30 % guadua content + 10 mm lime plaster both faces) and the **optimized bahareque mix** (pozzolanic lime + pasto estrella fibers + 30 % guadua + 5 mm lime plaster). Both cost breakdowns are shown below.

## Cost Per Panel — Baseline Mix (materials only)

| Material | Specification | Qty per panel | Unit cost (USD) | Total (USD) |
|---|---|---|---|---|
| L-angle steel | L 40×40×4 mm, ASTM A36 | 7.0 m | $4.00/m | $28.00 |
| Galvanizing | Hot-dip, batch process | 1 frame | $2.00 | $2.00 |
| Clamping strips | 40×3 mm flat bar, galv. | 4.0 m | $1.00/m | $4.00 |
| Corner gussets + bolts | Flat plate + M12/M8 | 1 set | $3.00 | $3.00 |
| SS screws | Self-tapping, A2 | 40 pcs | $0.08 | $3.20 |
| HDPE blocks | Recycled, 30×30 mm | 2.0 m | $1.50/m | $3.00 |
| Bamboo strips (vertical + horizontal, 30 % cavity density) | Borate-treated guadua | ~400 m total | $0.05/m | $20.00 |
| Bamboo strips (diagonal) | 60×20 mm, treated | ~5.4 m | $0.30/m | $1.60 |
| Wire ties | Galvanized | 5 m | $0.10/m | $0.50 |
| PVC conduit | 16 mm electrical | 5 m | $0.30/m | $1.50 |
| 12V cable + sockets | 2-core + 6× E10 | 1 set | $3.00 | $3.00 |
| 120V cable + connectors | 3-core + snap connectors | 1 set | $4.00 | $4.00 |
| Chicken wire mesh | Galvanized hex, 25 mm | 5.5 m² | $0.80/m² | $4.40 |
| Cement | Portland Type I | ~54 kg | $0.15/kg | $8.10 |
| Sand (mortar) | Clean river sand | ~240 kg | $0.02/kg | $4.80 |
| PP fiber | Chopped 6–12 mm | 200 g | $5.00/kg | $1.00 |
| Pozzolanic admixture | Volcanic ash or RHA | 2 kg | $0.50/kg | $1.00 |
| **Panel subtotal — baseline** | | | | **~$93** |

### On-site finishing, baseline (per panel area)

| Material | Qty per panel | Cost (USD) |
|---|---|---|
| Lime plaster (10 mm each face, both faces) | ~25 kg lime + ~65 kg sand | $6.50 |
| Lime wash (both faces) | ~2 kg lime | $0.50 |
| **Finishing subtotal — baseline** | | **$7.00** |

### **Total material cost per panel — baseline: ~$100 USD**

### Cost per m² of finished wall — baseline

- Panel area: 1.0 m × 2.5 m = 2.5 m²
- Material cost per m²: **~$40 USD/m²**

## Cost Per Panel — Optimized Bahareque Mix (materials only)

The optimized mix replaces Portland cement-sand mortar with hydraulic-lime + pozzolan, replaces PP fiber with pasto estrella (free, collected on-site), and uses thinner 5 mm lime plaster. Same L-angle frame, same bamboo content, same electrical and structural components.

| Material | Specification | Qty per panel | Unit cost (USD) | Total (USD) |
|---|---|---|---|---|
| L-angle steel + galvanizing + clamping strips + gussets | (as baseline) | | | $37.20 |
| SS screws, HDPE, bamboo, wire ties, conduit, cables, mesh | (as baseline) | | | $41.20 |
| Hydraulic lime (core binder) | NHL 3.5 or NHL 5 | ~42 kg | $0.30/kg | $12.60 |
| Fly ash or rice husk ash (pozzolan, 30 % cement-equivalent) | FA or RHA | ~15 kg | $0.10/kg | $1.50 |
| Sand (mortar) | Clean river sand | ~200 kg | $0.02/kg | $4.00 |
| Pasto estrella fiber (dried star grass) | Collected on-site | ~3 kg | free | $0.00 |
| **Panel subtotal — optimized** | | | | **~$96** |

### On-site finishing, optimized (per panel area)

| Material | Qty per panel | Cost (USD) |
|---|---|---|
| Lime plaster (5 mm each face, both faces) | ~12 kg lime + ~33 kg sand | $3.30 |
| Lime wash (both faces) | ~2 kg lime | $0.50 |
| **Finishing subtotal — optimized** | | **$3.80** |

### **Total material cost per panel — optimized: ~$100 USD**

### Cost per m² of finished wall — optimized

- Material cost per m²: **~$40 USD/m²**

> **Both mixes land at approximately the same material cost** (~$100/panel, ~$40/m²). The optimized mix trades slightly higher lime/pozzolan ingredient cost (vs cheaper Portland cement) for lower lime-plaster cost (thinner), zero PP fiber cost, and substantially lower embodied CO₂ (see [Environmental Impact](10-environmental-impact.md)). The optimized mix is therefore a **clear win on carbon and heritage authenticity at essentially equal cost**.

## Comparison with Conventional Construction

| Wall system | Material cost per m² (USD) | Lifespan | Notes |
|---|---|---|---|
| **This panel system — baseline** | **~$40** | **80–100 years** | Includes structure, electrical, finish |
| **This panel system — optimized** | **~$40** | **80–100 years** | Same price, lower carbon |
| Concrete block (15 cm) | $25–35 | 40–60 years | Requires rebar, grout, plaster, paint, separate electrical |
| Fired brick | $30–45 | 60–80 years | Requires mortar, plaster, paint, separate electrical |
| Drywall on steel studs | $20–30 | 20–30 years | No thermal mass, not load-bearing, requires paint, separate electrical |
| Conventional bahareque (in-situ) | $15–25 | 15–30 years | No electrical, finish quality variable, short lifespan without engineering |
| Adobe block | $10–20 | 20–40 years | Poor seismic performance, no electrical, requires thick walls |

**Key insight:** The panel system costs about **20–35 % more per m² than concrete block** — but includes integrated electrical, has 1.5–2× the lifespan, provides better thermal and acoustic performance, and produces a superior finish. When you factor in the cost of wiring a concrete block house separately (~$8–15/m² for conduits, cables, outlets, and their install labor), the panel system is cost-competitive on a complete-wall-ready-to-occupy basis.

## Cost Per House (rough estimate)

A simple single-story house with loft (50 m² footprint, ~70 m² livable including loft):

| Component | Quantity | Cost (USD) |
|---|---|---|
| Wall panels | ~40 panels (100 m² of wall) | $2,600–2,800 |
| Foundation (concrete, rebar) | ~5 m³ concrete | $800–1,200 |
| Ring beam (timber/bamboo) | ~30 m | $200–400 |
| Roof (terracotta tiles + purlins) | ~65 m² | $1,200–1,800 |
| Floor (concrete slab or earthen) | ~50 m² | $400–800 |
| Windows + doors | ~8 openings | $600–1,200 |
| Electrical panel + transformer | 1 set | $200–400 |
| Plumbing (basic) | Kitchen + bathroom | $300–600 |
| **Total materials** | | **$6,300–9,200** |

This is materials only. In a community-build model, labor is contributed. In a contractor model, add 40–60% for labor.

**For context:** A comparable concrete block house in rural Colombia costs $12,000–20,000 (materials + labor) and lasts 40–60 years. This system achieves similar or better quality at roughly half the cost with twice the lifespan.

## Cost Reduction Strategies

| Strategy | Savings | Notes |
|---|---|---|
| Harvest own bamboo | 30–40% of bamboo cost | Requires 1+ hectares of guadua stand, 4–5 year maturity |
| Recycle HDPE from waste | 100% of HDPE cost | Cutting boards, pipe offcuts, industrial waste |
| Use volcanic ash (free) | 100% of pozzolan cost | Available in Andean regions, collect and sieve |
| Use star grass fiber instead of PP | 100% of fiber cost | Invasive grass, free, circular use |
| Batch galvanizing (50+ frames) | 15–20% of galv. cost | Volume discount from galvanizing plant |
| Community sand quarry | 50–80% of sand cost | If river sand access is available locally |
| Make own lime from limestone | 50–70% of lime cost | Requires kiln (one-time build), local limestone |

## Regional Price Variations

Material costs vary dramatically by region. The estimates above are for Colombia. Rough multipliers:

| Region | Multiplier | Notes |
|---|---|---|
| Colombia (Eje Cafetero) | 1.0× (baseline) | Guadua abundant, volcanic ash available |
| Ecuador, Peru | 0.8–1.1× | Similar materials, caña guadua available |
| Central America | 1.0–1.3× | Bamboo available, steel may cost more |
| Philippines, Indonesia | 0.7–1.0× | Bamboo abundant and cheap, labor very low |
| India | 0.6–0.9× | Bamboo and labor very low, steel affordable |
| Sub-Saharan Africa | 0.8–1.2× | Bamboo species vary, cement may be expensive |
| Southern Europe | 2.0–3.0× | Materials available but more expensive |

These multipliers are rough guides. The single biggest variable is bamboo cost — if you grow your own, it's nearly free.

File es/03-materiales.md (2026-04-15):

# Materiales

## Lista de Materiales (por panel)

| Material | Especificación | Cantidad | Notas |
|---|---|---|---|
| Ángulo L de acero | L 40×40×4 mm, galvanizado en caliente (ASTM A36 / NTC 2542 ICONTEC equivalente) | 2× 1,0 m + 2× 2,5 m = 7,0 m | Stock comercial colombiano (Gerdau Diaco, Aceros Arequipa, Acesco, Ferrasa). Barras de 6 m, corte con tronzadora |
| Tiras de sujeción | Platina 40×3 mm, galvanizada, agujeros coincidentes | 4× 1,0 m = 4,0 m | Superior + inferior, ambos lados |
| Cartelas + tornillería de esquina | Platina de refuerzo + tornillos M12/M8 | 1 juego | Conexión de esquina más rígida que solo cordón de soldadura |
| Tornillos | Acero inoxidable, autorroscantes | ~28 por panel | A través de tira de sujeción → bambú → HDPE → alma (cada ~70 mm, uno por cada dos tiras) |
| Bloques de HDPE | Sección transversal de 30×30 mm, reciclado | 2× 1,0 m = 2,0 m | Sobre las almas del ángulo L superior + inferior |
| Tiras de bambú (verticales) | Tratadas con borato, ~20 mm de ancho | ~54 tiras × 2,5 m | ~27 por lado |
| Tiras de bambú (diagonal) | Tratadas con borato, 60×20 mm | 2× ~2,69 m | 1 por lado, esquinas opuestas |
| Alambre galvanizado | Alambre de amarre | ~5 m | ~16–20 amarres en cruces |
| Conducto de PVC | Eléctrico de 16 mm | ~5 m | Protección de cables |
| Cable 12V | 2 conductores | ~6 m | Circuito de iluminación |
| Cable 120V | 3 conductores (L+N+T) | ~6 m | Circuito de red |
| Portalámparas E10 | Rosca base para bombillos | 6 | 3 por lado |
| Conectores rápidos | 2 pines (12V) + 3 pines (120V) | 2 + 2 | Ambos bordes verticales |
| Malla de gallinero | Malla hexagonal galvanizada, 25 mm | ~5,5 m² | Ambas caras + traslape |
| Mortero de cemento (base) | 1:4 cemento:arena + aditivos | ~0,147 m³ de cavidad neta (después del 30 % de guadua + desplazamiento del acero) | ~310 kg húmedo / ~294 kg curado (densidad ~2 000 kg/m³) |
| Mortero de cal puzolánica con pasto estrella (optimizado) | Cal hidráulica + 30 % de cenizas volantes/CCA + fibras de pasto estrella | ~0,147 m³ misma cavidad | ~270 kg húmedo / ~257 kg curado (densidad ~1 750 kg/m³) |
| Fibra de PP | Picada 6–12 mm | ~200 g | Prevención de grietas de curado |
| Adición puzolánica | Ceniza volcánica / ceniza de cascarilla de arroz / metacaolín | ~2 kg | Reducción de pH, durabilidad |

**El pañete de cal y la lechada de cal se aplican en obra después de la instalación del panel — no son parte del panel en sí.**

---

## Detalles de Materiales

### Bambú Estructural

El sistema usa tiras de bambú estructural partido como el material de relleno principal. La especie de referencia es **Guadua angustifolia** (conocida como *guadua* en toda Latinoamérica, *caña guadua* en Ecuador, *tacuara* en algunas regiones) — el bambú estructural más resistente de las Américas. Sin embargo, cualquier especie de bambú estructural de gran diámetro puede adaptarse.

Propiedades clave de la Guadua angustifolia:

- **Resistencia a la tracción:** 150–200 MPa (comparable al acero dulce)
- **Crecimiento:** Alcanza el diámetro de cosecha (10–15 cm) en 4–5 años
- **Distribución:** 0–2.000 m de altitud en las Américas tropicales (Colombia, Ecuador, Centroamérica)
- **Cosecha:** Se corta a los 4–6 años (máxima lignificación). Los culmos más jóvenes son muy blandos; los más viejos se vuelven frágiles.
- **Tratamiento:** Solución de borato (bórax + ácido bórico) por método Boucherie modificado o inmersión. Previene el ataque de insectos y la descomposición por hongos. No tóxico, efectivo por más de 20 años cuando está encapsulado en mortero.

#### Alternativas para Otras Regiones

| Especie | Región | Notas |
|---|---|---|
| *Dendrocalamus asper* | Sudeste Asiático | Gran diámetro, resistente. Sustituto directo. |
| *Bambusa bambos* | Sur/Sudeste de Asia | Espinoso, resistente. Requiere tiras más anchas. |
| *Phyllostachys edulis* (Moso) | China, zonas templadas | Diámetro menor. Usar tiras más anchas y delgadas. |
| *Phyllostachys bambusoides* | Japón, zonas templadas | Buena resistencia. Culmos más pequeños. |
| *Guadua chacoensis* | Argentina, Paraguay | Pariente cercano de G. angustifolia. |

El sistema funciona con cualquier bambú estructural que pueda partirse en tiras. Ajuste el ancho de tira y la separación según la especie disponible.

### Marco de Ángulo L de Acero

- **Perfil:** L 40×40×4 mm ángulo de alas iguales (ASTM A36 / NTC 2542 ICONTEC)
- **Masa:** ~2,42 kg/m; marco del panel total ~17 kg + ~4 kg tiras de sujeción + ~1 kg cartelas/tornillería = **~22 kg por panel**
- **Galvanizado:** En caliente según ISO 1461, mínimo 85 μm de recubrimiento de zinc
- **Vida útil:** 80–100 años en ambientes tropicales no costeros con el espesor de zinc especificado (el panel en servicio queda continuamente arriostrado dentro de la matriz alcalina del mortero, que auto-pasiva el acero expuesto)
- **Abastecimiento:** Producto comercial a nivel mundial. En Colombia: Gerdau Diaco, Aceros Arequipa, Acesco, Ferrasa, Colmena/Sidenal, Perfilamos del Cauca. Stock en barras de 6 m en prácticamente cualquier proveedor de acero estructural. Sin pedido especial, sin fabricación a medida, sin almas asimétricas
- **Perfiles alternativos:** L 50×50×4 o L 50×50×5 (ligeramente más pesados, también stock comercial) son sustitutos directos. SHS (perfil hueco cuadrado) 40×40×2 también funciona estructuralmente pero requiere que las tiras de sujeción se suelden en lugar de atornillarse a través del alma
- **¿Por qué no perfil T?:** Versiones anteriores de este documento especificaban T 60×60×7 mm (~45 kg por panel). El servicio del panel continuamente arriostrado no requiere el alma simétrica del perfil T — un alma de ángulo L de un solo lado es estructuralmente equivalente a aproximadamente la mitad de la masa de acero, la mitad del costo y disponibilidad dramáticamente mejor. Los perfiles T abiertos siguen siendo la elección correcta solo donde importa la resistencia al pandeo en el eje débil (p. ej. columnas independientes — el tubo cuadrado cerrado se prefiere sobre el perfil T en este sistema).

### Separadores de HDPE

- **Fuente:** Tablas de cortar de HDPE reciclado, secciones de tubería o láminas
- **Propiedades:** Cero absorción de agua, inmune a la pudrición, dimensionalmente estable, fácil de maquinar
- **Maquinado:** Sierra de mesa o sierra de banda para cortar a medida. Fresadora o formón para las muescas de esquina.

#### Alternativas al HDPE

| Material | Ventajas | Desventajas |
|---|---|---|
| **HDPE reciclado** (preferido) | Inmune a la pudrición, cero absorción de agua, ampliamente disponible del flujo de residuos | Requiere herramientas de corte |
| **Madera dura de grado marino** (teca, ipé, greenheart) | Resistente, naturalmente resistente a la pudrición, fácil de maquinar | Costosa, aún se degrada con las décadas en ambientes húmedos |
| **Madera blanda tratada** (pino tratado con CCA o borato) | Barata, ampliamente disponible | Vida útil más corta (20–40 años), puede necesitar reemplazo |
| **Bloques de caucho denso** (caucho de llantas recicladas) | Inmune a la pudrición, amortiguador, gratis del flujo de llantas | Más difícil de maquinar con precisión, puede comprimirse con el tiempo |
| **Bloques de concreto/mortero** | Costo cero, fundidos en moldes, permanentes | Frágiles, más difíciles de hacer muescas para las diagonales, pesados |
| **Bloques impresos en 3D** (PETG o ASA) | Geometría precisa incluyendo muescas, reproducible | Requiere impresora 3D, degradación UV si se expone |

El requisito crítico es: el bloque debe mantener su dimensión de 30 mm durante toda la vida útil de la edificación para preservar el perfil )( de las tiras. El HDPE cumple esto mejor, pero cualquier material que resista la humedad y la compresión funcionará.

### Mortero

- **Mezcla base:** 1 parte de cemento Portland Tipo I : 4 partes de arena de río limpia (bien gradada, 0–4 mm)
- **Fibra de PP:** 200 g por panel (~1 kg por m³). Previene las grietas de retracción plástica durante el curado.
- **Adición puzolánica:** 5–10% de reemplazo de cemento.
  - **Ceniza volcánica** — disponible en regiones andinas, naturalmente puzolánica
  - **Ceniza de cascarilla de arroz (CCA)** — disponible en regiones productoras de arroz (Asia, Latinoamérica)
  - **Metacaolín** — arcilla de caolín procesada, disponible globalmente pero más costosa
  - **Función:** Reacciona con el hidróxido de calcio del cemento, reduciendo el pH de ~12,5 a ~10–11 con el tiempo. Esto retarda la degradación de la guadua embebida.
- **Agua:** Limpia, potable. Relación A/C ~0,45–0,50 para consistencia vertible en mesa vibradora.

### Pañete de Cal (en obra)

- **Tipo:** Cal hidráulica (NHL 3.5 o NHL 5) o cal apagada (cal en pasta) + arena
- **Mezcla:** 1:2,5 a 1:3 cal:arena
- **Fibra opcional:** Pasto seco picado (estrella africana, sisal, cáñamo) en trozos de ~1 cm. Agrega resistencia a la tracción y a las grietas. La celulosa natural dura más de 30 años en la cal (pH ~10, mucho menos agresivo que el cemento).
- **Aplicación:** Aplicado a llana, 3–5 mm. La textura es la belleza — la perfección de máquina no es el objetivo.

### Lechada de Cal (en obra)

- Cal apagada + agua, aplicada con brocha en capas delgadas
- Penetra y se adhiere químicamente al pañete de cal (carbonatación)
- Reaplicar cada 5–10 años para mantenimiento
- Se puede teñir con pigmentos naturales (óxidos de tierra) para dar color

### Malla de Gallinero

- Malla hexagonal galvanizada, abertura de 25 mm, alambre de 0,7–0,9 mm
- Grapada o amarrada a la cara del panel antes de la aplicación de mortero
- Proporciona traba mecánica para la adherencia del mortero
- Ambas caras

### Malla Fina de Aluminio (opcional)

- Malla estándar contra insectos/polvo, abertura de 1–1,5 mm, aluminio
- Colocada debajo de la malla de gallinero en ambas caras
- Bloquea insectos, polvo fino y polen que puedan entrar por la matriz de mortero
- Como propiedad secundaria, también proporciona atenuación medible de radiofrecuencia
- No requerida para función estructural — agregar según las condiciones locales de insectos/polvo

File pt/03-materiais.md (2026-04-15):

# Materiais

## Lista de Materiais (por painel)

| Material | Especificação | Quantidade | Observações |
|---|---|---|---|
| Cantoneira L de aço | L 40×40×4 mm, galvanizada a quente (ASTM A36 / equivalente ICONTEC NTC 2542) | 2× 1,0 m + 2× 2,5 m = 7,0 m | Estoque comercial colombiano (Gerdau Diaco, Aceros Arequipa, Acesco, Ferrasa). Barras de 6 m, corte com serra-tronco |
| Tiras de fixação | Chato 40×3 mm, galvanizado, furos correspondentes | 4× 1,0 m = 4,0 m | Superior + inferior, ambos os lados |
| Cartelas de canto + parafusos | Chato de reforço + parafusos M12/M8 | 1 conjunto | Conexão de canto mais rígida que solda apenas |
| Parafusos | Aço inoxidável, autoperfurantes | ~28 por painel | Através da tira de fixação → bambu → PEAD → alma (a cada ~70 mm, um para cada duas tiras) |
| Blocos de PEAD | Seção de 30×30 mm, reciclado | 2× 1,0 m = 2,0 m | Sobre as almas das cantoneiras L superior + inferior |
| Tiras de bambu (verticais) | Tratadas com borato, ~20 mm de largura | ~54 tiras × 2,5 m | ~27 por lado |
| Tira de bambu (diagonal) | Tratada com borato, 60×20 mm | 2× ~2,69 m | 1 por lado, cantos opostos |
| Arame galvanizado | Arame de amarração | ~5 m | ~16–20 amarrações nos cruzamentos |
| Eletroduto de PVC | 16 mm elétrico | ~5 m | Proteção de cabos |
| Cabo 12V | 2 condutores | ~6 m | Circuito de iluminação |
| Cabo 120V | 3 condutores (F+N+T) | ~6 m | Circuito de rede |
| Soquetes E10 | Suportes de lâmpada rosca | 6 | 3 por lado |
| Conectores rápidos | 2 pinos (12V) + 3 pinos (120V) | 2 + 2 | Ambas as bordas verticais |
| Tela de galinheiro | Tela hexagonal galvanizada, 25 mm | ~5,5 m² | Ambas as faces + sobreposição |
| Argamassa de cimento (base) | 1:4 cimento:areia + aditivos | ~0,147 m³ cavidade líquida | ~310 kg úmida / ~294 kg curada (densidade ~2 000 kg/m³) |
| Argamassa de cal pozolânica com capim-estrela (otimizada) | Cal hidráulica + 30 % cinzas volantes/CCA + fibras de capim-estrela | ~0,147 m³ mesma cavidade | ~270 kg úmida / ~257 kg curada (densidade ~1 750 kg/m³) |
| Fibra de PP | 6–12 mm picada | ~200 g | Prevenção de fissuras na cura |
| Aditivo pozolânico | Cinza vulcânica / cinza de casca de arroz / metacaulim | ~2 kg | Redução de pH, durabilidade |

**O reboco de cal e a caiação são aplicados no local após a instalação do painel — não fazem parte do painel em si.**

---

## Detalhes dos Materiais

### Bambu Estrutural

O sistema usa tiras de bambu estrutural cortado como material de preenchimento principal. A espécie de referência é a **Guadua angustifolia** (conhecida como *guadua* em toda a América Latina, *caña guadua* no Equador, *tacuara* em algumas regiões) — o bambu estrutural mais resistente das Américas. No entanto, qualquer espécie de bambu estrutural de grande diâmetro pode ser adaptada.

Propriedades principais da Guadua angustifolia:

- **Resistência à tração:** 150–200 MPa (comparável ao aço doce)
- **Crescimento:** Atinge diâmetro de colheita (10–15 cm) em 4–5 anos
- **Distribuição:** 0–2.000 m de altitude nas Américas tropicais (Colômbia, Equador, América Central)
- **Colheita:** Cortada aos 4–6 anos (máxima lignificação). Colmos mais novos são muito macios; mais velhos ficam quebradiços.
- **Tratamento:** Solução de borato (bórax + ácido bórico) pelo método Boucherie modificado ou por imersão. Previne ataque de insetos e decomposição fúngica. Não tóxico, eficaz por mais de 20 anos quando encapsulado em argamassa.

#### Alternativas para Outras Regiões

| Espécie | Região | Observações |
|---|---|---|
| *Dendrocalamus asper* | Sudeste Asiático | Grande diâmetro, resistente. Substituto direto. |
| *Bambusa bambos* | Sul/Sudeste Asiático | Espinhoso, resistente. Requer tiras mais largas. |
| *Phyllostachys edulis* (Moso) | China, zonas temperadas | Diâmetro menor. Use tiras mais largas e finas. |
| *Phyllostachys bambusoides* | Japão, zonas temperadas | Boa resistência. Colmos menores. |
| *Guadua chacoensis* | Argentina, Paraguai | Parente próxima da G. angustifolia. |

O sistema funciona com qualquer bambu estrutural que possa ser cortado em tiras. Ajuste a largura e o espaçamento das tiras para a espécie disponível.

### Estrutura em Cantoneira L de Aço

- **Perfil:** L 40×40×4 mm cantoneira de abas iguais (ASTM A36 / ICONTEC NTC 2542)
- **Massa:** ~2,42 kg/m; estrutura do painel total ~17 kg + ~4 kg tiras de fixação + ~1 kg cartelas/parafusos = **~22 kg por painel**
- **Galvanização:** A quente conforme ISO 1461, revestimento mínimo de zinco de 85 μm
- **Vida útil:** 80–100 anos em ambientes tropicais não costeiros na espessura de zinco especificada (o painel em serviço fica continuamente contraventado dentro da matriz alcalina da argamassa, que auto-passiva o aço exposto)
- **Fornecimento:** Item comercial mundial. Na Colômbia: Gerdau Diaco, Aceros Arequipa, Acesco, Ferrasa, Colmena/Sidenal, Perfilamos del Cauca. Estoque em barras de 6 m em praticamente qualquer fornecedor de aço estrutural. Sem encomenda especial, sem fabricação sob medida, sem alma assimétrica
- **Perfis alternativos:** L 50×50×4 ou L 50×50×5 (um pouco mais pesados, também estoque comercial) são substitutos diretos. SHS (perfil tubular quadrado) 40×40×2 também funciona estruturalmente, mas exige que as tiras de fixação sejam soldadas em vez de parafusadas através da alma
- **Por que não perfil T:** Versões anteriores deste documento especificavam T 60×60×7 mm (~45 kg por painel). O serviço do painel continuamente contraventado não exige a alma simétrica do perfil T — uma alma de cantoneira L unilateral é estruturalmente equivalente com aproximadamente metade da massa de aço, metade do custo e disponibilidade dramaticamente melhor. Perfis T abertos continuam sendo a escolha correta apenas onde a resistência à flambagem no eixo fraco importa (p. ex. colunas independentes — o tubo quadrado fechado é preferido sobre o perfil T neste sistema).

### Blocos Espaçadores de PEAD

- **Origem:** Tábuas de corte de PEAD recicladas, seções de tubo ou chapas
- **Propriedades:** Zero absorção de água, imune ao apodrecimento, dimensionalmente estável, fácil de usinar
- **Usinagem:** Serra circular ou serra de fita para cortar no tamanho. Tupia ou formão para os entalhes dos cantos.

#### Alternativas ao PEAD

| Material | Vantagens | Desvantagens |
|---|---|---|
| **PEAD reciclado** (preferido) | Imune ao apodrecimento, zero absorção de água, amplamente disponível do fluxo de resíduos | Requer ferramentas de corte |
| **Madeira nobre resistente à água** (teca, ipê, maçaranduba) | Resistente, naturalmente resistente ao apodrecimento, fácil de usinar | Cara, ainda se degrada ao longo de décadas em ambientes úmidos |
| **Madeira mole tratada** (pinho tratado com CCA ou borato) | Barata, amplamente disponível | Vida útil mais curta (20–40 anos), pode precisar de substituição |
| **Blocos de borracha densa** (borracha de pneu reciclada) | Imune ao apodrecimento, absorve impacto, grátis de pneus usados | Mais difícil de usinar com precisão, pode comprimir ao longo do tempo |
| **Blocos de concreto/argamassa** | Custo zero, moldados, permanentes | Frágeis, mais difíceis de entalhar para diagonais, pesados |
| **Blocos impressos em 3D** (PETG ou ASA) | Geometria precisa incluindo entalhes, reproduzível | Requer impressora 3D, degradação UV se exposto |

O requisito crítico é: o bloco deve manter sua dimensão de 30 mm durante toda a vida útil da edificação para preservar o perfil )( das tiras. O PEAD atende melhor a isso, mas qualquer material que resista à umidade e à compressão funcionará.

### Argamassa

- **Traço base:** 1 parte de cimento Portland Tipo I : 4 partes de areia de rio limpa (bem graduada, 0–4 mm)
- **Fibra de PP:** 200 g por painel (~1 kg por m³). Previne fissuras por retração plástica durante a cura.
- **Aditivo pozolânico:** Substituição de 5–10% do cimento.
  - **Cinza vulcânica** — disponível nas regiões andinas, naturalmente pozolânica
  - **Cinza de casca de arroz (CCA)** — disponível em regiões produtoras de arroz (Ásia, América Latina)
  - **Metacaulim** — argila caulim processada, disponível globalmente mas mais cara
  - **Função:** Reage com o hidróxido de cálcio no cimento, reduzindo o pH de ~12,5 para ~10–11 ao longo do tempo. Isso retarda a degradação da guadua incorporada.
- **Água:** Limpa, potável. Relação A/C ~0,45–0,50 para consistência de vertimento na mesa vibratória.

### Reboco de Cal (no local)

- **Tipo:** Cal hidráulica (NHL 3.5 ou NHL 5) ou cal apagada (cal em pasta) + areia
- **Traço:** 1:2,5 a 1:3 cal:areia
- **Fibra opcional:** Capim seco picado (grama-estrela, sisal, cânhamo) em comprimento de ~1 cm. Adiciona resistência à tração e resistência a fissuras. A celulose natural dura mais de 30 anos na cal (pH ~10, muito menos agressivo que o cimento).
- **Aplicação:** Aplicado à mão com desempenadeira, 3–5 mm. A textura é a beleza — perfeição de máquina não é o objetivo.

### Caiação (no local)

- Cal apagada + água, aplicada com broxa em camadas finas
- Penetra e se liga quimicamente ao reboco de cal (carbonatação)
- Reaplicar a cada 5–10 anos para manutenção
- Pode ser tingida com pigmentos naturais (óxidos de terra) para coloração

### Tela de Galinheiro

- Tela hexagonal galvanizada, abertura de 25 mm, arame de 0,7–0,9 mm
- Grampeada ou amarrada à face do painel antes da aplicação da argamassa
- Proporciona aderência mecânica para a argamassa
- Ambas as faces

### Tela Fina de Alumínio (opcional)

- Tela padrão contra insetos/poeira, abertura de 1–1,5 mm, alumínio
- Colocada sob a tela de galinheiro em ambas as faces
- Bloqueia insetos, poeira fina e pólen de entrar pela matriz de argamassa
- Como propriedade secundária, também proporciona atenuação mensurável de radiofrequência
- Não necessária para função estrutural — adicione conforme condições locais de insetos/poeira

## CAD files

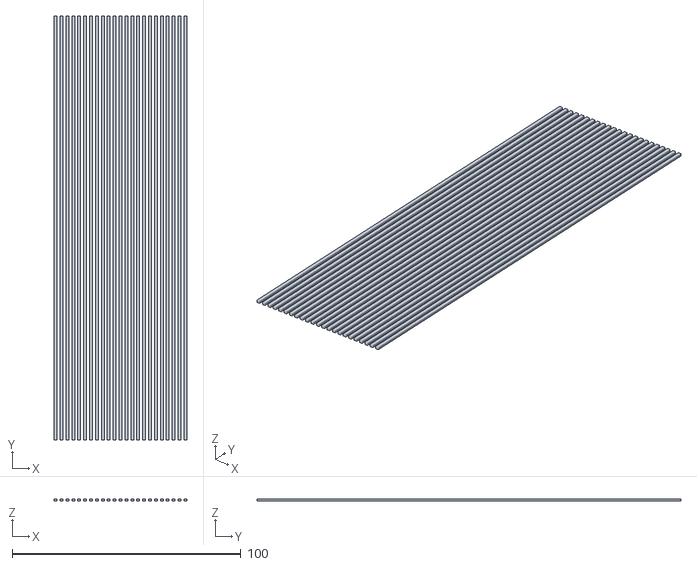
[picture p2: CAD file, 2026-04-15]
stl/03a_guadua_vert_front.stl
58.0 x 185.2 x 1.00

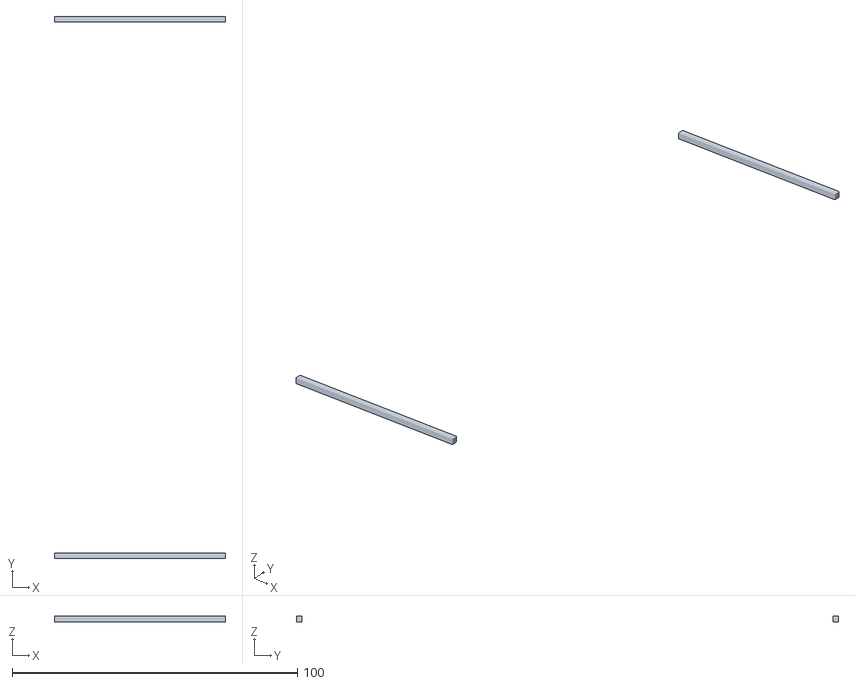
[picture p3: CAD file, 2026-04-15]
stl/02b_hdpe_rear.stl
60.1 x 190.2 x 2.00

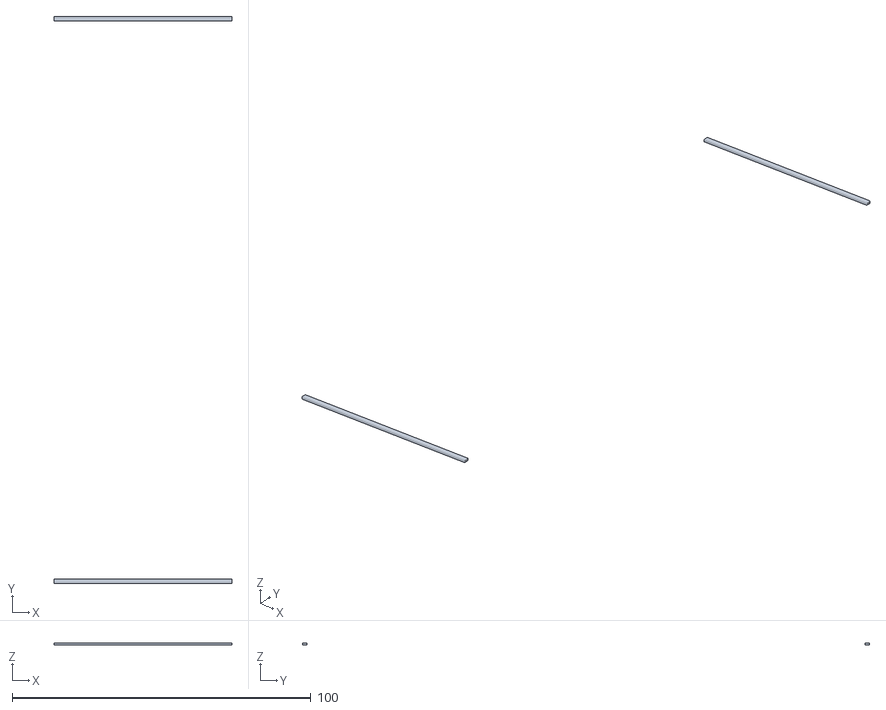
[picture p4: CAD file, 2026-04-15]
stl/06b_clamps_rear.stl
59.5 x 189.8 x 0.8

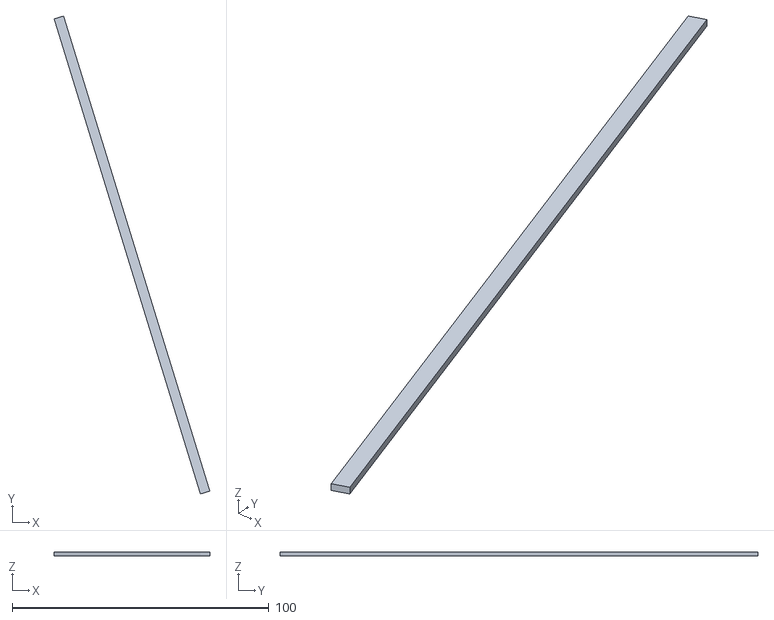
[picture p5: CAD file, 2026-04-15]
stl/05_guadua_diagonal_rear.stl
60.6 x 186.0 x 1.50

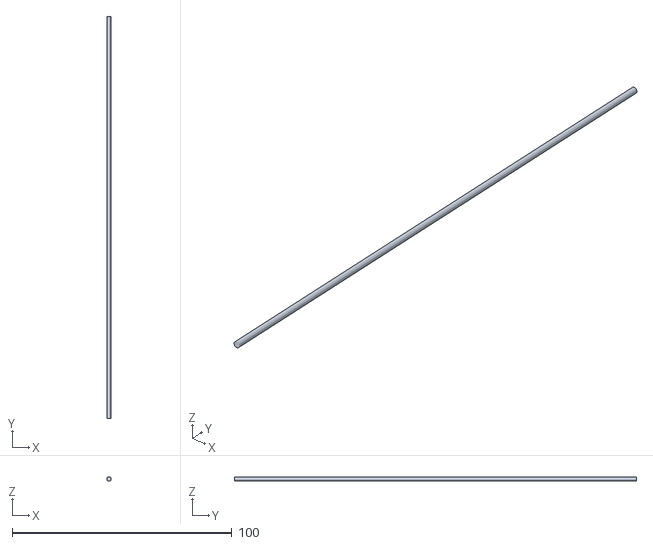
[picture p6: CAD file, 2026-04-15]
stl/07_conduit.stl
2.00 x 182.8 x 2.00

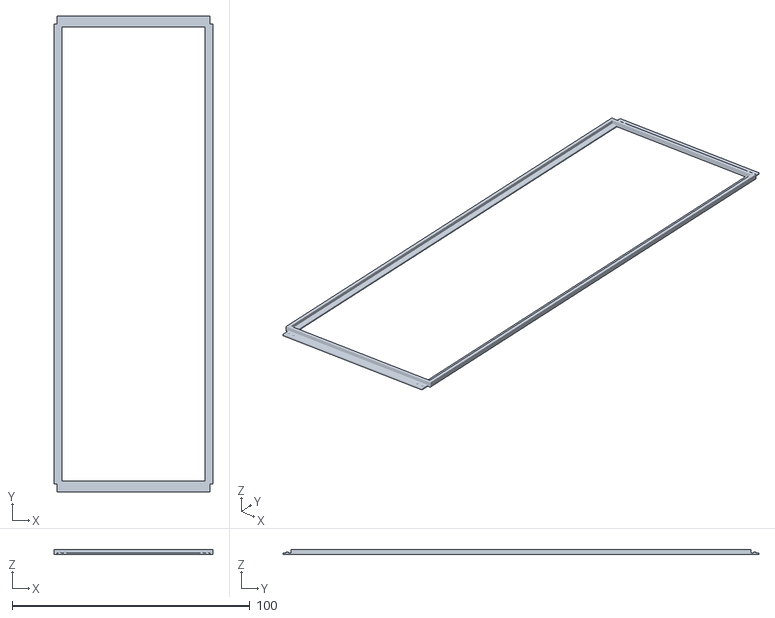
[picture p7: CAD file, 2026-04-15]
stl/01b_frame_rear.stl
66.8 x 200.0 x 1.93

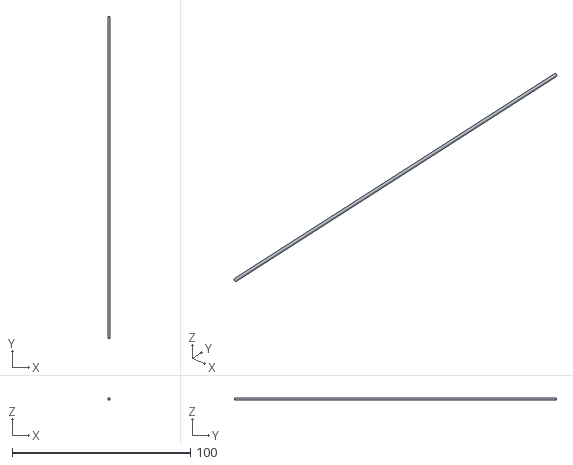
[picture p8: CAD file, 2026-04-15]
stl/08_cable_12v.stl
1.20 x 180.8 x 1.20

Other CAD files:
stl/03b_guadua_vert_rear.stl
stl/04_guadua_diagonal_front.stl
stl/02a_hdpe_front.stl
stl/01a_frame_front.stl
stl/09_cable_120v.stl
stl/06a_clamps_front.stl

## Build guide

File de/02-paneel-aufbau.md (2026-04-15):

# Paneelaufbau

Paneel Explosionsdarstellung

> **SVG-Aktualisierung ausstehend:** Einige Diagramme in diesem Kapitel werden von der früheren T-Profil-Spezifikation auf die aktuelle **L 40×40×4 mm Winkelprofil**-Spezifikation umgestellt. Einige T-Profil-spezifische SVGs wurden vorübergehend entfernt, bis sie neu erzeugt sind. Siehe [`SVG-STATUS.md`](../SVG-STATUS.md) im Repository-Stammverzeichnis für die vollständige SVG-Neuerzeugungsliste.

## Übersicht

Jedes Wandpaneel ist **1,0 m breit × 2,5 m hoch** (Hochformat). Das Paneelgewicht hängt von der Produktionsphase ab: Eine **Trockenmontage** (Rahmen + Bambus + Gitter + Installationen, vor dem Mörtelguss) wiegt ungefähr **~75 kg** und ist die Form, die von der Werkstatt zur Baustelle geliefert wird, um Mörtel vor Ort zu giessen. Sobald der Mörtel gegossen und ausgehärtet ist und die Vor-Ort-Oberflächen (Putz, Kalkanstrich) aufgebracht sind:

- **Basis-Gewicht der fertigen Wand:** ungefähr **~440 kg** pro Paneel (≈ 176 kg/m²) mit der dokumentierten Standardmischung (30 % Guadua-Anteil im Hohlraum + Zement-Sand-Mörtel + 10 mm Kalkputz auf beiden Seiten).
- **Optimierte Bahareque-Mischung:** ungefähr **~360 kg** pro Paneel (≈ 144 kg/m²) mit puzzolanischem Kalkmörtel mit Pasto-estrella-Fasern + 30 % Guadua + 5 mm Kalkputz auf beiden Seiten. Traditionelle kolumbianische Bahareque-Praxis auf das modulare System übertragen; leicht geringere graue Energie, etwas niedrigere Kosten, volle strukturelle Leistungsfähigkeit erhalten.

Jedes Paneel enthält integrierte Tragstruktur, Isolierung und Elektrosysteme. Eine Grösse. Vier Varianten.

> **Skalierbarkeit:** Die 2,5 m Höhe eignet sich für Standardwohnraumhöhen weltweit. Das System skaliert auf jede Höhe — 3,0 m für hohe Decken, 2,7 m für Gewerberäume, 2,0 m für Trennwände. Nur die vertikalen L-Winkel und Bambusstreifen ändern die Länge. Die Rahmenlehre, das Klemmsystem, der Mörtelprozess und das Elektrolayout bleiben identisch.

## Rahmen: L-Winkel 40×40×4 mm

> _Rahmenprofil-Diagramm ausstehend — SVG-Neuerzeugung für L 40×40×4 noch nicht verfügbar. Siehe `SVG-STATUS.md`._

Der Paneelrahmen ist ein handelsüblicher L-Winkel (warmgewalztes gleichschenkliges Winkelprofil, ASTM A36 / ICONTEC-Äquivalent, feuerverzinkt):

- **Profil:** L 40×40×4 mm (beide Schenkel 40 mm breit, 4 mm dick)
- **Ein Schenkel (Flansch):** 40 mm × 4 mm — zeigt nach aussen, bündig mit der Mörteloberfläche
- **Anderer Schenkel (Steg):** 40 mm × 4 mm — ragt nach innen, bietet strukturelle Tiefe und Klemmfläche für Bambusstreifen und Gitter
- **Wandstärke:** ~85 mm (der L-Winkel-Steg sitzt im Mörtelkern, Mörtel füllt ~41 mm beiderseits der Stegebene)
- **Ecken:** Auf Gehrung 45° geschnitten und in einer Lehre geschweisst — alle Rahmen identisch. Optionale Eckbleche für zusätzliche Steifigkeit
- **Klemmlöcher:** Alle ~70 mm entlang der oberen und unteren Schenkel gebohrt (ein Loch pro zwei Bambusstreifen). Bambus-Klemmleisten (Flachstahl 40×3) werden an diesen Löchern verschraubt
- **Verfügbarkeit:** Massenartikel, weltweit bei jedem grösseren Stahlhändler verfügbar. In Kolumbien: Gerdau Diaco, Aceros Arequipa, Acesco, Ferrasa, Colmena/Sidenal. In 6-m-Stangen vorrätig, mit Trennschleifer auf Mass geschnitten. Keine Sonderanfertigung, keine asymmetrischen Stege
- **Warum L-Winkel statt T-Profil:** Strukturell gleichwertig für den dauerhaft im Mörtel eingebetteten Rahmen (siehe [Tragverhalten](05-tragverhalten.md)), deutlich geringeres Stahlgewicht (~22 kg/Paneel gegenüber ~45 kg bei T 60×60×7), niedrigere Kosten, niedrigere graue CO₂-Emissionen und — entscheidend — als Lagermaterial verfügbar statt als bespoke asymmetrische Anfertigung

Der Rahmen ist das strukturelle Rückgrat. Alles andere wird daran befestigt.

## HDPE-Distanzblöcke

- **Grösse:** 30 × 30 mm Querschnitt, volle 1 m Breite
- **Position:** Auf oberen und unteren L-Winkel-Stegen montiert (2 pro Paneel)
- **Funktion:** Halten die Bambusstreifen oben und unten 30 mm vom Steg fern
- **Eckkerben:** 10 × 10 mm Aussparungen an jeder Ecke verankern die Diagonalstreifen auf Steghöhe
- **Material:** Recyceltes HDPE (aus Platte oder Rohr). Keine Fäulnis, keine Korrosion, formstabil

## Guadua-Vertikalstreifen

- **Material:** Borat-behandelte Guadua angustifolia, in Streifen gespalten
- **Masse:** ~20 mm breit × 2.500 mm lang
- **Abstand:** ~20 mm Lücken zwischen den Streifen (Mörteldurchdringung)
- **Menge:** ~27 Streifen pro Seite, ~54 total pro Paneel
- **Befestigung:** Schraubgeklemmt an den L-Winkel-Steg oben und unten über Klemmleisten

Diagonalverstrebung

### Das )( Profil

Side Profile

Oben und unten halten die HDPE-Blöcke die Streifen 30 mm vom Steg entfernt. Auf halber Höhe biegen sich die Streifen natürlich nach innen zum Steg — wodurch ein **)(** Querschnittprofil entsteht. Das ist kein Fehler; es ist das Design:

- Der Mörtel füllt den variierenden Spalt und erzeugt eine natürliche Bogenform
- Der Bogen widersteht Kräften senkrecht zur Wandebene (Wind, Stoss)
- Der Mörtel mit variabler Dicke verankert die Streifen mechanisch

## Bambus-Diagonalstreifen

- **Masse:** 60 × 20 mm, ~2.690 mm lang (Ecke zu Ecke diagonal)
- **Menge:** 1 pro Seite, von gegenüberliegenden Ecken (bildet ein X von vorne betrachtet)
- **Position:** Verläuft auf Steghöhe, durch die HDPE-Block-Eckkerben gefädelt
- **Vorgespannt:** Vor dem Befestigen stramm gezogen
- **Funktion:** Wandelt seismische Scherkräfte in Zug in der Diagonale um. Bietet **3–5× Verbesserung der Schubsteifigkeit** gegenüber Paneelen ohne Diagonalen.

### Drahtbindungen

Verzinkte Drahtbindungen an jeder Diagonal-Vertikal-Kreuzung (~8–10 pro Seite). Diese verriegeln die vertikalen und diagonalen Streifen zu einem starren Gitter, verteilen Punktlasten über die gesamte Paneelfläche und erzeugen ein duktiles Versagensmuster.

## PVC-Leerrohr

- **Grösse:** 16 mm Standard-Elektroleerrohr
- **Position:** Zwischen den Bambusstreifen, am Steg anliegend
- **Funktion:** Schützt 12V- und 120V-Kabel vor Mörtel und Schraubendruck. Ermöglicht Kabelaustausch durch Einziehen neuer Leitungen, ohne das Paneel zu öffnen.

## Elektrosysteme

Jedes Paneel enthält zwei unabhängige Stromkreise:

### 12V Beleuchtung
- 2-adriges Kabel im PVC-Leerrohr
- 6× E10-Schraubfassungen (3 pro Seite) nahe dem oberen Paneelrand
- Warmtonige Glüh- oder LED-Lampen (0,5–1W pro Stück) — Wandflutbeleuchtung
- 2-polige Snap-Stecker an beiden Vertikalkanten

### 120V Netz (je nach Variante)
- 3-adriges Kabel (L + N + PE) im PVC-Leerrohr
- 3-polige Snap-Stecker an beiden Vertikalkanten
- Wenn Paneele nebeneinander verschraubt sind, rasten die Stecker zusammen = durchgehender Stromkreis

## Paneelvarianten

| Typ | Anteil | Inhalt |
|-----|---|---|
| **P** — Durchleitung | ~60% | 12V Beleuchtung + 120V Durchleitungskabel. Keine Steckdosen. |
| **O** — Steckdose | ~18% | 12V Beleuchtung + Doppelsteckdose auf ~40 cm Höhe |
| **S** — Schalter + Steckdose | ~9% | 12V Beleuchtung + Schalter auf ~120 cm + Steckdose auf ~40 cm |
| **W** — Wasser + Steckdose | ~13% | 12V Beleuchtung + Steckdose + Kalt-/Warmwasser-Steigleitungen + Grauwasserabfluss |

Alle Varianten teilen denselben Rahmen, dieselbe Bambus-Ausfachung, denselben Mörtel. Nur die eingebetteten Installationen unterscheiden sich.

## Mörtel

- **Mischung:** 1:4 Portlandzement : sauberer Flusssand
- **Zusätze:** Polypropylenfaser (6–12 mm) zur Rissverhinderung in der Aushärtungsphase + puzzolanischer Zusatz (Vulkanasche, Reishülsenasche oder Metakaolin)
- **Auftrag:** Verguss auf Rütteltisch (siehe [Bauprozess](04-bauprozess.md))
- **Gesamte Wanddicke:** ~85 mm (Mörtel + Guadua + Mörtel)
- **Das Puzzolan** reduziert den Mörtel-pH-Wert über die Zeit und verlangsamt den Abbau des eingebetteten Bambus

Paneel-Querschnitt

## Deckschichten (auf der Baustelle nach der Installation aufgetragen)

1. **Hühnerdrahtgeflecht** — verzinktes Sechseckgeflecht (25 mm Maschenweite), auf beide Seiten geklammert. Bietet mechanischen Verbund für die Mörtel-/Putzhaftung.
2. **Feines Aluminiumgitter** (optional) — Standard-Insekten-/Staubschutzgitter, 1–1,5 mm Maschenweite. Blockiert Insekten, Feinstaub und Pollen am Eindringen durch die Mörtelmatrix. Als sekundäre Eigenschaft bietet die Aluminiumschicht auch messbare Hochfrequenzdämpfung.
3. **Kalkputz** — 3–5 mm, handgeglättet. Atmungsaktiv, antimykotisch, selbstheilend. Optional: gehäckselte getrocknete Grasfaser für Rissbeständigkeit.
4. **Kalkanstrich** — Kalk + Wasser, mit Pinsel aufgetragen. Sanftes mattes Finish. Jeder Pinselstrich einzigartig.

## Gewichtsaufschlüsselung (ungefähr)

| Komponente | Gewicht |
|---|---|
| Stahlrahmen | ~18 kg |
| HDPE-Blöcke | ~1 kg |
| Bambusstreifen + Diagonalen | ~12 kg |
| Mörtel (85 mm × 1 m × 2,5 m) | ~120 kg |
| Draht, Gitter, Leerrohr, Kabel | ~6 kg |
| **Total** | **~155 kg** |

Tragbar von 3–4 Personen mit einer einfachen Tragelehre.

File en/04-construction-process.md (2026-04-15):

# Construction Process

> **SVG update pending**: some diagrams in this chapter were generated for the previous T-bar frame spec and have been temporarily unlinked until regenerated for the current **L 40×40×4 mm angle** spec. See [`SVG-STATUS.md`](../SVG-STATUS.md) at the repo root.

## Workshop Setup

All panels are built in a covered workshop — weather-independent, quality-controlled, assembly-line efficient. Minimum workshop requirements:

- Covered area: ~6 × 4 m (roof, open sides acceptable)
- Welding station (frame fabrication only)
- Drill press or hand drill
- 2× vibration tables (~1.2 × 2.7 m each) for workshop-pour production model, **or** formwork + in-situ mortar pump for the preferred in-situ pour model (see [Panel Anatomy § Weight Breakdown](02-panel-anatomy.md))
- Sand supply for bed
- Mortar mixer (electric or hand)
- Basic hand tools: screwdrivers, wire cutters, pliers, staple gun

Assembly Sequence

## Production Steps

### Step 1: Frame Fabrication

> _Wall-panel-frame diagram pending — the previous frame SVG shows T-bar geometry and is not representative of the L-angle frame. See `SVG-STATUS.md`._

1. Cut L 40×40×4 angle to length: 2× 1.0 m (top/bottom) + 2× 2.5 m (sides). Commodity stock from Gerdau Diaco / Acesco / Ferrasa, 6 m sticks
2. Mitre-cut the corners at 45° (or straight-cut with one leg lapped over the other — either produces a clean rectangular frame)
3. Weld corners in a jig — all frames identical. Optional small corner gussets (60×60×3 plate) can be welded across each inside corner for rigidity during handling
4. Drill clamping holes every ~70 mm along the top and bottom angle webs (one per two bamboo strips, ~14 holes per bar, ~28 total)
5. Hot-dip galvanize the completed frame (batch process — send 20–50 frames at once)

**All frames are identical regardless of panel variant.** The jig ensures consistent dimensions. One jig, one frame, forever.

### Step 2: HDPE Blocks

1. Cut HDPE stock to 30 × 30 mm × 1,000 mm (2 per panel)
2. Cut corner notches: 10 × 10 mm at each end (4 notches per block, 8 per panel)
3. Mount blocks on top and bottom angle webs using screws or adhesive

### Step 3: Electrical

1. Route 12V cable through PVC conduit
2. Route 120V cable through separate PVC conduit
3. Mount E10 sockets (3 near top, each side)
4. For Type O/S: mount outlet box, wire pigtail to main cable
5. For Type S: mount switch box at 120 cm height
6. For Type W: mount water risers (CPVC/PEX supply, PVC drain) with capped stub-outs
7. Attach snap connectors at both vertical edges (2-pin for 12V, 3-pin for 120V)

### Step 4: Bamboo Strips (Side 1)

1. Place panel frame flat on work table, side 1 up
2. Lay vertical bamboo strips against the web, between the HDPE blocks
3. Leave ~20 mm gaps between strips for mortar penetration
4. Place PVC conduit with cables between strips, against web
5. Thread diagonal strip through bottom-left HDPE notch, across to top-right notch (at web level)
6. Pre-tension diagonal and secure at both ends

> _Screw-clamping diagram pending — the previous clamping SVG shows T-bar web geometry; the L-angle clamping detail is similar in principle (clamping strip → bamboo → screw through web) but geometrically different. See `SVG-STATUS.md`._

### Step 5: Screw-Clamping (Side 1)

1. Place steel clamping strip (flat bar, 3 mm × 40 mm × 1,000 mm) over the bamboo strips at the top angle web
2. Align holes in clamping strip with holes in the L-angle web
3. Drive stainless steel screws through: clamping strip → bamboo strips → web holes
4. The clamping strip flexes to accommodate natural thickness variation — self-adjusting
5. Repeat at bottom angle
6. Wire-tie diagonal to each vertical strip at crossings (~8–10 ties)

**Time: ~5 minutes per side for clamping, ~3 minutes for wire ties**

### Step 6: Flip and Repeat (Side 2)

1. Flip panel
2. Repeat steps 4–5 on the other side
3. Diagonal on side 2 runs from top-left to bottom-right (opposing the side 1 diagonal — together they form an X)

### Step 7: Mesh

1. Lay chicken wire over side 1, extending 20 mm past frame edges (for overlap with adjacent panels)
2. Staple or wire-tie to frame and bamboo strips
3. If using aluminum insect mesh: place under chicken wire
4. Flip and repeat on side 2

### Step 8: Mortar Pour

Mortar Pour Process

This is the key innovation in application method:

1. **Prepare vibration table:** Level surface, motor mounted underneath
2. **Spread sand bed:** ~30 mm of clean dry sand on the table surface. The sand conforms to any panel face irregularities and prevents mortar adhesion to the table.
3. **Place panel face-down** on the sand bed (chicken wire side touching sand)
4. **Mix mortar:** 1:4 cement:sand + PP fiber + pozzolanic admixture, W/C ~0.45–0.50 (pourable but not liquid)
5. **Pour mortar** over the exposed back of the panel, filling between strips and covering the mesh
6. **Start vibration:** Run table for 30–60 seconds. The vibration:
   - Drives mortar through the gaps between strips
   - Fills the center cavity completely
   - Eliminates voids and air pockets
   - Mortar penetrates to the front face mesh (now resting on sand)
7. **Screed** excess mortar level with the frame edges
8. **Trowel** smooth (this becomes the interior face)

> **Vibration table build guide:** A DIY vibration table design (motor, platform, springs) will be published in this repository once the design has been tested and proven safe in practice. Until then, any flat platform with a concrete vibrator clamped to the edge will work for initial experiments.

**Why vibration table on sand bed?**
- Gravity + vibration = complete fill, no voids
- Sand bed = no mold needed, sand conforms to panel shape
- No spraying equipment needed (cheaper than spray mortar)
- One-sided pour fills both sides — mortar flows through strip gaps
- Consistent quality — vibration eliminates human error

### Step 9: Curing

1. Cover panel with plastic sheet to retain moisture
2. Keep moist for minimum 7 days (mist spray or damp burlap)
3. Full strength at 28 days
4. Panels can be stacked vertically (edge-on) after 7 days to save space
5. Mark each panel with variant type and production date

**Production rate: 3–4 panels per day** with 2 vibration tables running in parallel, team of 4–6 people. Active work per panel: ~15–20 minutes. Passive curing: 7–28 days (panels cure while new ones are produced).

### Step 10: Transport and Installation

1. Transport panels to building site using simple A-frame cart or truck
2. Bolt panels into steel building frame at column positions (pre-welded bolt tabs on columns)
3. Adjacent panels touch mortar-to-mortar
4. Snap-connect electrical between adjacent panels (12V + 120V)
5. Test circuits before finishing

### Step 11: On-Site Finishing

1. Fill any joints between panels with mortar
2. Apply chicken wire mesh over joints (if not already overlapping from panel edges)
3. Apply lime plaster: 3–5 mm, hand-troweled, both faces
4. Allow to cure (keep moist for 3–5 days)
5. Apply lime wash: 2–3 thin coats with brush

The finished wall is seamless — no visible joints, no visible steel, no visible screws. Just smooth lime plaster with the texture of a hand-made wall.

### Step 12: Bathroom Waterproofing

Bathroom and shower zones require waterproof treatment instead of lime plaster:

1. **Shower walls:** apply liquid waterproof membrane (Sika-1 or similar) directly to the mortar panel face — 2 coats, brush-on. Then flexible tile adhesive + ceramic/porcelain tiles. **No lime plaster in the shower zone.**
2. **Bathroom floor (entire):** waterproof membrane on the slab surface + ceramic tiles. The slab must have a 2% fall toward the floor drain (formed during the slab pour).
3. **Bathroom walls outside shower:** lime plaster is acceptable, or tiles for easy cleaning.
4. **Ceiling (under mezzanine):** lime plaster — not directly sprayed.

The mortar panel surface provides excellent adhesion for the liquid membrane — no additional prep needed. Just clean the panel face and apply.

### Drainage (planned in the slab)

All drainage must be installed BEFORE the foundation slab is poured:

- **Toilet drain:** 4" (100mm) PVC pipe to septic tank. Position is fixed — cannot be moved later.
- **Shower floor drain:** 2" (50mm) PVC with trap. Slab recessed ~20mm in shower area to contain water.
- **Sink drains:** 1.5" (40mm) PVC with trap. Kitchen sink through the slab; bathroom sink through the W-type water panel or slab.
- **Cleanout:** accessible fitting outside the building on the drain line.

The W-type panel provides supply risers (hot/cold CPVC). Drainage is always in the slab — gravity drainage needs slope that panels cannot provide.

## Quality Checklist

- [ ] Frame dimensions within ±2 mm
- [ ] All clamping holes drilled and aligned
- [ ] Bamboo strips borate-treated (green/blue tint visible)
- [ ] Diagonal pre-tensioned (should ring when tapped)
- [ ] All wire ties tight
- [ ] Electrical circuits tested before mortar (12V and 120V)
- [ ] Mortar consistency correct (slump test)
- [ ] Vibration run for full 30–60 seconds
- [ ] No visible voids on pour face after vibration
- [ ] Panel marked with type and date
- [ ] Cured minimum 7 days before handling

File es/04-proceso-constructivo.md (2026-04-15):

# Proceso Constructivo

> **Actualización de SVG pendiente:** algunos diagramas en este capítulo fueron generados para la especificación anterior del marco con perfil T y han sido temporalmente desvinculados hasta que se regeneren para la especificación actual de **ángulo L 40×40×4 mm**. Ver [`SVG-STATUS.md`](../SVG-STATUS.md) en la raíz del repositorio.

## Preparación del Taller

Todos los paneles se construyen en un taller cubierto — independiente del clima, con control de calidad, eficiente como línea de ensamble. Requisitos mínimos del taller:

- Área cubierta: ~6 × 4 m (techo, lados abiertos aceptable)
- Estación de soldadura (solo para fabricación de marcos)
- Taladro de columna o taladro manual
- 2× mesas vibradoras (~1,2 × 2,7 m cada una) para el modelo de producción de vertido en taller, **o** encofrado + bomba de mortero in situ para el modelo preferido de vertido in situ (ver [Anatomía del Panel § Desglose de Peso](02-anatomia-del-panel.md))
- Suministro de arena para la cama
- Mezcladora de mortero (eléctrica o manual)
- Herramientas manuales básicas: destornilladores, cortafrío, alicates, grapadora

Secuencia de Ensamble

## Pasos de Producción

### Paso 1: Fabricación del Marco

> _Diagrama del marco del panel pendiente — el SVG anterior del marco muestra geometría de perfil T y no es representativo del marco de ángulo L. Ver `SVG-STATUS.md`._

1. Cortar ángulo L 40×40×4 a longitud: 2× 1,0 m (superior/inferior) + 2× 2,5 m (laterales). Stock comercial de Gerdau Diaco / Acesco / Ferrasa, barras de 6 m
2. Cortar las esquinas a inglete a 45° (o cortar a escuadra con un ala traslapada sobre la otra — ambos producen un marco rectangular limpio)
3. Soldar esquinas en una plantilla — todos los marcos son idénticos. Opcionalmente, pequeñas cartelas de esquina (60×60×3 platina) pueden soldarse sobre cada esquina interior para rigidez durante el manejo
4. Perforar agujeros de sujeción cada ~70 mm a lo largo de las almas del ángulo superior e inferior (uno por cada dos tiras de bambú, ~14 agujeros por barra, ~28 en total)
5. Galvanizar en caliente el marco completo (proceso por lotes — enviar 20–50 marcos a la vez)

**Todos los marcos son idénticos sin importar la variante del panel.** La plantilla asegura dimensiones consistentes. Una plantilla, un marco, para siempre.

### Paso 2: Bloques de HDPE

1. Cortar HDPE a 30 × 30 mm × 1.000 mm (2 por panel)
2. Cortar muescas de esquina: 10 × 10 mm en cada extremo (4 muescas por bloque, 8 por panel)
3. Montar bloques en las almas del ángulo L superior e inferior usando tornillos o adhesivo

### Paso 3: Instalación Eléctrica

1. Pasar cable 12V por conducto de PVC
2. Pasar cable 120V por conducto de PVC separado
3. Montar portalámparas E10 (3 cerca de la parte superior, cada lado)
4. Para Tipo O/S: montar caja de tomacorriente, conectar ramal al cable principal
5. Para Tipo S: montar caja de interruptor a 120 cm de altura
6. Para Tipo W: montar acometidas de agua (suministro CPVC/PEX, desagüe PVC) con terminaciones tapadas
7. Fijar conectores rápidos en ambos bordes verticales (2 pines para 12V, 3 pines para 120V)

### Paso 4: Tiras de Bambú (Lado 1)

1. Colocar marco del panel plano sobre mesa de trabajo, lado 1 arriba
2. Colocar tiras verticales de bambú contra el alma, entre los bloques de HDPE
3. Dejar ~20 mm de espacio entre tiras para penetración del mortero
4. Colocar conducto de PVC con cables entre las tiras, contra el alma
5. Pasar la tira diagonal por la muesca inferior izquierda del HDPE, cruzando hacia la muesca superior derecha (a nivel del alma)
6. Pre-tensionar la diagonal y asegurar en ambos extremos

> _Diagrama de sujeción con tornillos pendiente — el SVG anterior muestra geometría del alma del perfil T; el detalle de sujeción con ángulo L es similar en principio (tira de sujeción → bambú → tornillo a través del alma) pero geométricamente diferente. Ver `SVG-STATUS.md`._

### Paso 5: Sujeción con Tornillos (Lado 1)

1. Colocar tira de sujeción de acero (platina 3 mm × 40 mm × 1.000 mm) sobre las tiras de bambú en el alma del ángulo superior
2. Alinear agujeros de la tira de sujeción con los agujeros del alma del ángulo L
3. Atornillar con tornillos de acero inoxidable a través de: tira de sujeción → tiras de bambú → agujeros del alma
4. La tira de sujeción se flexiona para acomodar la variación natural de espesor — autoajustable
5. Repetir en el ángulo inferior
6. Amarrar con alambre la diagonal a cada tira vertical en los cruces (~8–10 amarres)

**Tiempo: ~5 minutos por lado para sujeción, ~3 minutos para amarres de alambre**

### Paso 6: Voltear y Repetir (Lado 2)

1. Voltear el panel
2. Repetir los pasos 4–5 en el otro lado
3. La diagonal del lado 2 va de arriba izquierda a abajo derecha (opuesta a la del lado 1 — juntas forman una X)

### Paso 7: Malla

1. Colocar malla de gallinero sobre el lado 1, extendiéndose 20 mm más allá de los bordes del marco (para traslape con paneles adyacentes)
2. Grapar o amarrar con alambre al marco y a las tiras de bambú
3. Si se usa malla de aluminio contra insectos: colocar debajo de la malla de gallinero
4. Voltear y repetir en el lado 2

### Paso 8: Vertido de Mortero

Proceso de Vertido de Mortero

Esta es la innovación clave en el método de aplicación:

1. **Preparar mesa vibradora:** Superficie nivelada, motor montado debajo
2. **Extender cama de arena:** ~30 mm de arena limpia y seca sobre la superficie de la mesa. La arena se conforma a cualquier irregularidad de la cara del panel y previene la adherencia del mortero a la mesa.
3. **Colocar panel boca abajo** sobre la cama de arena (lado de malla de gallinero tocando la arena)
4. **Mezclar mortero:** 1:4 cemento:arena + fibra de PP + adición puzolánica, A/C ~0,45–0,50 (vertible pero no líquido)
5. **Verter mortero** sobre la parte trasera expuesta del panel, llenando entre las tiras y cubriendo la malla
6. **Iniciar vibración:** Hacer funcionar la mesa por 30–60 segundos. La vibración:
   - Empuja el mortero a través de los espacios entre las tiras
   - Llena la cavidad central completamente
   - Elimina vacíos y bolsas de aire
   - El mortero penetra hasta la malla de la cara frontal (que descansa sobre la arena)
7. **Enrasar** el exceso de mortero a ras con los bordes del marco
8. **Llana** lisa (esta se convierte en la cara interior)

> **Guía de construcción de mesa vibradora:** Un diseño de mesa vibradora hecho en casa (motor, plataforma, resortes) se publicará en este repositorio una vez que el diseño haya sido probado y comprobado como seguro en la práctica. Mientras tanto, cualquier plataforma plana con un vibrador de concreto prensado al borde funcionará para experimentos iniciales.

**¿Por qué mesa vibradora sobre cama de arena?**
- Gravedad + vibración = llenado completo, sin vacíos
- Cama de arena = no se necesita molde, la arena se conforma a la forma del panel
- No se necesita equipo de rociado (más barato que mortero rociado)
- Vertido de un solo lado llena ambos lados — el mortero fluye a través de los espacios entre tiras
- Calidad consistente — la vibración elimina el error humano

### Paso 9: Curado

1. Cubrir panel con lámina plástica para retener humedad
2. Mantener húmedo por mínimo 7 días (rocío con nebulizador o arpillera húmeda)
3. Resistencia completa a los 28 días
4. Los paneles pueden apilarse verticalmente (de canto) después de 7 días para ahorrar espacio
5. Marcar cada panel con el tipo de variante y la fecha de producción

**Tasa de producción: 3–4 paneles por día** con 2 mesas vibradoras funcionando en paralelo, equipo de 4–6 personas. Trabajo activo por panel: ~15–20 minutos. Curado pasivo: 7–28 días (los paneles curan mientras se producen nuevos).

### Paso 10: Transporte e Instalación

1. Transportar paneles a la obra usando un carro en A sencillo o camión
2. Empernar paneles al marco de acero en las posiciones de las columnas (pestañas de pernos pre-soldadas en las columnas)
3. Los paneles adyacentes se tocan mortero con mortero
4. Conectar rápidamente la electricidad entre paneles adyacentes (12V + 120V)
5. Probar circuitos antes del acabado

### Paso 11: Acabado en Obra

1. Rellenar cualquier junta entre paneles con mortero
2. Aplicar malla de gallinero sobre las juntas (si no hay traslape de los bordes del panel)
3. Aplicar pañete de cal: 3–5 mm, aplicado a llana, ambas caras
4. Dejar curar (mantener húmedo por 3–5 días)
5. Aplicar lechada de cal: 2–3 capas delgadas con brocha

El muro terminado es sin costuras — sin juntas visibles, sin acero visible, sin tornillos visibles. Solo pañete de cal liso con la textura de un muro hecho a mano.

## Lista de Verificación de Calidad

- [ ] Dimensiones del marco dentro de ±2 mm
- [ ] Todos los agujeros de sujeción perforados y alineados
- [ ] Tiras de bambú tratadas con borato (tinte verde/azul visible)
- [ ] Diagonal pre-tensionada (debe sonar al golpearla)
- [ ] Todos los amarres de alambre apretados
- [ ] Circuitos eléctricos probados antes del mortero (12V y 120V)
- [ ] Consistencia del mortero correcta (prueba de asentamiento)
- [ ] Vibración completa por 30–60 segundos
- [ ] Sin vacíos visibles en la cara de vertido después de la vibración
- [ ] Panel marcado con tipo y fecha
- [ ] Curado mínimo 7 días antes de manipular

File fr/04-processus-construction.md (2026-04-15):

# Processus de construction

> **Mise a jour SVG en attente :** certains diagrammes de ce chapitre ont ete generes pour l'ancienne specification du cadre en T et ont ete temporairement deconnectes en attendant leur regeneration pour la specification actuelle de **corniere L 40x40x4 mm**. Voir [`SVG-STATUS.md`](../SVG-STATUS.md) a la racine du depot.

## Installation de l'atelier

Tous les panneaux sont fabriques dans un atelier couvert -- independant de la meteo, avec controle qualite et efficacite de chaine de montage. Exigences minimales de l'atelier :

- Surface couverte : ~6 x 4 m (toit, cotes ouverts acceptables)
- Poste de soudure (fabrication des cadres uniquement)
- Perceuse a colonne ou perceuse portative
- 2x tables vibrantes (~1,2 x 2,7 m chacune)
- Approvisionnement en sable pour le lit
- Malaxeur a mortier (electrique ou manuel)
- Outils a main de base : tournevis, pinces coupantes, pinces, agrafeuse

Sequence d'assemblage

## Etapes de production

### Etape 1 : Fabrication du cadre

> _Diagramme du cadre du panneau en attente -- l'ancien SVG du cadre montre la geometrie en T et n'est pas representatif du cadre en corniere L. Voir `SVG-STATUS.md`._

1. Couper la corniere L 40x40x4 aux longueurs : 2x 1,0 m (haut/bas) + 2x 2,5 m (cotes). Stock courant chez Gerdau Diaco / Acesco / Ferrasa, barres de 6 m
2. Couper les angles en onglet a 45° (ou couper droit avec une aile recouvrant l'autre -- les deux donnent un cadre rectangulaire propre)
3. Souder les angles dans un gabarit -- tous les cadres sont identiques. De petits goussets d'angle optionnels (plat 60×60×3) peuvent etre soudes en travers de chaque angle interieur pour la rigidite a la manutention
4. Percer les trous de serrage tous les ~70 mm le long des ames superieures et inferieures de la corniere (un pour deux lattes de bambou, ~14 trous par barre, ~28 au total)
5. Galvaniser a chaud les cadres finis (processus par lot -- envoyer 20-50 cadres a la fois)

**Tous les cadres sont identiques quelle que soit la variante de panneau.** Le gabarit garantit des dimensions constantes. Un gabarit, un cadre, pour toujours.

### Etape 2 : Blocs en PEHD

1. Couper le stock PEHD a 30 x 30 mm x 1 000 mm (2 par panneau)
2. Couper les encoches d'angle : 10 x 10 mm a chaque extremite (4 encoches par bloc, 8 par panneau)
3. Monter les blocs sur les ames de la corniere L haut et bas avec des vis ou de l'adhesif

### Etape 3 : Electricite

1. Passer le cable 12V dans la gaine PVC
2. Passer le cable 120V dans une gaine PVC separee
3. Monter les douilles E10 (3 pres du haut, chaque face)
4. Pour le type O/S : monter le boitier de prise, relier le pigtail au cable principal
5. Pour le type S : monter le boitier d'interrupteur a 120 cm de hauteur
6. Pour le type W : monter les colonnes montantes d'eau (alimentation CPVC/PEX, evacuation PVC) avec des bouchons
7. Fixer les connecteurs rapides aux deux bords verticaux (2 broches pour 12V, 3 broches pour 120V)

### Etape 4 : Lattes de bambou (face 1)

1. Poser le cadre du panneau a plat sur la table de travail, face 1 vers le haut
2. Disposer les lattes verticales de bambou contre l'ame, entre les blocs en PEHD
3. Laisser des espaces de ~20 mm entre les lattes pour la penetration du mortier
4. Placer la gaine PVC avec les cables entre les lattes, contre l'ame
5. Passer la latte diagonale a travers l'encoche inferieure gauche du bloc PEHD, en travers jusqu'a l'encoche superieure droite (au niveau de l'ame)
6. Pre-tendre la diagonale et la fixer aux deux extremites

> _Diagramme du serrage par vis en attente -- l'ancien SVG montre la geometrie de l'ame en T ; le detail de serrage en corniere L est similaire en principe (bande de serrage → bambou → vis a travers l'ame) mais geometriquement different. Voir `SVG-STATUS.md`._

### Etape 5 : Serrage par vis (face 1)

1. Placer la bande de serrage en acier (plat 3 mm x 40 mm x 1 000 mm) sur les lattes de bambou au niveau de l'ame de la corniere superieure
2. Aligner les trous de la bande de serrage avec ceux de l'ame de la corniere L
3. Visser les vis en acier inoxydable a travers : bande de serrage, lattes de bambou, trous de l'ame
4. La bande de serrage se flexe pour s'adapter aux variations naturelles d'epaisseur -- auto-ajustable
5. Repeter sur la corniere inferieure
6. Ligaturer la diagonale a chaque latte verticale aux croisements (~8-10 ligatures)

**Temps : ~5 minutes par face pour le serrage, ~3 minutes pour les ligatures**

### Etape 6 : Retourner et repeter (face 2)

1. Retourner le panneau
2. Repeter les etapes 4-5 de l'autre cote
3. La diagonale de la face 2 va du coin superieur gauche au coin inferieur droit (oppose a la diagonale de la face 1 -- ensemble elles forment un X)

### Etape 7 : Grillage

1. Poser le grillage a poule sur la face 1, depassant de 20 mm les bords du cadre (pour le recouvrement avec les panneaux adjacents)
2. Agrafer ou ligaturer au cadre et aux lattes de bambou
3. Si utilisation d'un grillage anti-insectes en aluminium : le placer sous le grillage a poule
4. Retourner et repeter sur la face 2

### Etape 8 : Coulage du mortier

Processus de coulage du mortier

C'est l'innovation cle en matiere de methode d'application :

1. **Preparer la table vibrante :** Surface de niveau, moteur monte en dessous
2. **Etaler le lit de sable :** ~30 mm de sable propre et sec sur la surface de la table. Le sable s'adapte a toute irregularite de la face du panneau et empeche l'adherence du mortier a la table.
3. **Placer le panneau face vers le bas** sur le lit de sable (le cote grillage a poule touche le sable)
4. **Preparer le mortier :** 1:4 ciment:sable + fibre PP + adjuvant pouzzolanique, E/C ~0,45-0,50 (coulable mais pas liquide)
5. **Couler le mortier** sur le dos expose du panneau, en remplissant entre les lattes et en couvrant le grillage
6. **Demarrer la vibration :** Faire fonctionner la table pendant 30-60 secondes. La vibration :
   - Fait penetrer le mortier a travers les espaces entre les lattes
   - Remplit completement la cavite centrale
   - Elimine les vides et les poches d'air
   - Le mortier penetre jusqu'au grillage de la face avant (reposant sur le sable)
7. **Araser** l'exces de mortier au niveau des bords du cadre
8. **Lisser a la truelle** (cela devient la face interieure)

> **Guide de construction de la table vibrante :** Un plan de table vibrante DIY (moteur, plateforme, ressorts) sera publie dans ce depot une fois la conception testee et jugee sure en pratique. En attendant, toute plateforme plate avec un vibrateur a beton fixe au bord fonctionnera pour les premieres experimentations.

**Pourquoi une table vibrante sur lit de sable ?**
- Gravite + vibration = remplissage complet, zero vide
- Lit de sable = pas de moule necessaire, le sable s'adapte a la forme du panneau
- Pas d'equipement de projection necessaire (moins couteux que le mortier projete)
- Un coulage d'un seul cote remplit les deux faces -- le mortier s'ecoule a travers les espaces entre les lattes
- Qualite constante -- la vibration elimine l'erreur humaine

### Etape 9 : Durcissement

1. Couvrir le panneau avec une bache plastique pour retenir l'humidite
2. Maintenir humide pendant minimum 7 jours (brumisation ou toile de jute humide)
3. Resistance maximale a 28 jours
4. Les panneaux peuvent etre empiles verticalement (sur chant) apres 7 jours pour economiser de l'espace
5. Marquer chaque panneau avec le type de variante et la date de production

**Cadence de production : 3-4 panneaux par jour** avec 2 tables vibrantes fonctionnant en parallele, equipe de 4-6 personnes. Travail actif par panneau : ~15-20 minutes. Durcissement passif : 7-28 jours (les panneaux durcissent pendant que de nouveaux sont produits).

### Etape 10 : Transport et installation

1. Transporter les panneaux sur le chantier en utilisant un simple chariot a cadre en A ou un camion
2. Boulonner les panneaux dans l'ossature metallique du batiment aux emplacements des poteaux (pattes de fixation pre-soudees sur les poteaux)
3. Les panneaux adjacents se touchent mortier contre mortier
4. Connecter l'electricite entre panneaux adjacents par connexion rapide (12V + 120V)
5. Tester les circuits avant les finitions

### Etape 11 : Finitions sur site

1. Combler les joints entre panneaux avec du mortier
2. Appliquer le grillage a poule sur les joints (si le recouvrement depuis les bords des panneaux n'est pas suffisant)
3. Appliquer l'enduit a la chaux : 3-5 mm, a la truelle, les deux faces
4. Laisser durcir (maintenir humide pendant 3-5 jours)
5. Appliquer le badigeon de chaux : 2-3 couches fines au pinceau

Le mur fini est sans couture -- pas de joints visibles, pas d'acier visible, pas de vis visibles. Juste un enduit a la chaux lisse avec la texture d'un mur fait main.

## Liste de controle qualite

- [ ] Dimensions du cadre dans une tolerance de +/-2 mm
- [ ] Tous les trous de serrage perces et alignes
- [ ] Lattes de bambou traitees au borate (teinte verte/bleue visible)
- [ ] Diagonale pre-tendue (doit sonner lorsqu'on la tapote)
- [ ] Toutes les ligatures serrees
- [ ] Circuits electriques testes avant le mortier (12V et 120V)
- [ ] Consistance du mortier correcte (essai d'affaissement)
- [ ] Vibration effectuee pendant 30-60 secondes completes
- [ ] Aucun vide visible sur la face de coulage apres vibration
- [ ] Panneau marque avec le type et la date
- [ ] Durcissement minimum de 7 jours avant manipulation

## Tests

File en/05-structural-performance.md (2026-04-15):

# Structural Performance

## System Architecture

This panel system was designed to work **with a steel column-and-beam frame** — the configuration we recommend for multi-story buildings in seismic zones. In that configuration, the steel frame carries gravity and seismic loads while the panels provide lateral bracing, weather enclosure, thermal mass, and integrated services.

However, the panels are **structurally capable of working without a steel building frame**. With compression capacity far exceeding typical residential loads (two side L-angle posts at L 40×40×4), a row of panels can comfortably carry a second floor and roof without an independent steel structure. A simple timber or bamboo ring beam at the top connects the panels and distributes the roof load.

**Two configurations:**

| Configuration | Use case | Panel role |
|---|---|---|
| **With steel frame** (recommended) | Multi-story, high seismic zones, commercial/institutional | Infill — panels bolt into frame, steel carries primary loads |
| **Without steel frame** (simpler, lower cost) | Single story + loft/mezzanine, moderate seismic zones, residential | Load-bearing — panels carry roof and upper floor directly |

The load capacity estimates below apply to both configurations. The steel frame adds redundancy and moment resistance, but is not required for the panels to perform structurally.

## Seismic Performance

### Diagonal Bracing

Each panel contains two diagonal bamboo strips (one per side, opposing corners), forming an X when viewed from the front. Under seismic loading:

1. **Shear → tension conversion:** When the building frame racks sideways, one diagonal goes into tension while the opposite goes into compression. The bamboo diagonal in tension resists the racking force efficiently — bamboo has excellent tensile strength (150–200 MPa for Guadua angustifolia).
2. **Pre-tension:** Diagonals are installed with slight pre-tension, eliminating slack and ensuring immediate engagement under load.
3. **Wire tie grid:** Galvanized wire ties at every diagonal-vertical crossing (~16–20 ties total) distribute the diagonal force across the full panel face, preventing localized failure.

**Estimated improvement: 3–5× racking resistance** compared to panels without diagonal bracing.

### The )( Profile and Diagonal Interference

Profile and Interference

The HDPE blocks hold bamboo strips 30 mm from the web at top and bottom. Without the diagonal, strips would flex inward to ~5 mm from the web at mid-height, creating a smooth )( curve.

**In practice, the diagonal modifies this profile.** The diagonal strip (20 mm thick) runs at web level behind the vertical strips. At each of the ~22 crossing points in the middle 77% of the panel, the diagonal holds the vertical strip at 20 mm from the web — preventing full flex. Between crossings, strips flex slightly more. The result is a **ribbed )( profile**: a series of rigid nodes (at wire-tied crossings) with slight flex between them.

This interference is **by design and beneficial:**

- **Out-of-plane resistance:** The mortar between the strip layers still forms an arch, but with more pronounced ribs at each crossing — creating more mechanical interlock points than a smooth curve.
- **Mechanical interlock:** The varying mortar thickness at and between crossings locks the bamboo strips more securely than a uniform gap would.
- **Buckling resistance:** Strips held at 20 mm from the web (vs 5 mm with natural flex) contribute **7× more** to the wall's moment of inertia. This increases the critical buckling load by ~10% — meaning the diagonal improves not just racking resistance but also vertical load capacity.

| Zone | Panel height | Gap to web | Behavior |
|---|---|---|---|
| HDPE block zone (top/bottom) | 0–12% and 88–100% | 30 mm | Free flex, no interference |
| Interference zone (middle) | 12–88% | 20 mm (held by diagonal) | Diagonal acts as spacer, wire ties lock crossings |

**For builders:** The diagonal strip is installed first (threaded through HDPE notches at web level), then the vertical strips are placed against it. At crossing points, the vertical strip rests on the diagonal — they touch, and the wire tie locks them together. No notching, cutting, or special treatment is needed. The mortar fills all gaps during the vibration table pour.

### Ductile Failure Mode

The combination of bamboo strips, wire ties, and mortar creates a composite that fails gradually:

1. First: mortar cracks (visible warning)
2. Then: wire ties stretch (energy absorption)
3. Then: bamboo strips deform (high ductility)
4. The steel frame remains intact throughout — the building does not collapse

This is fundamentally different from unreinforced masonry, which fails brittlely (sudden collapse with no warning).

## Fire Resistance

- **Mortar encasement:** The bamboo strips are fully encased in mortar (~85 mm wall thickness). Mortar is non-combustible and acts as thermal insulation for the bamboo.
- **Bamboo charring:** Even if fire penetrates the mortar, bamboo chars slowly and predictably (similar to timber construction). The steel frame behind maintains structural integrity.
- **Lime plaster finish:** Non-combustible. Provides additional fire protection.
- **No exposed bamboo:** Once installed and finished, no bamboo is visible or accessible to flame.

## Thermal Performance

- **Thermal mass:** ~85 mm of mortar provides significant thermal mass — absorbs heat during the day, releases at night. Reduces temperature swings in tropical climates.
- **Breathability:** Lime plaster is vapor-permeable. Moisture passes through the wall rather than getting trapped, preventing condensation and mold.
- **No insulation gap:** The system does not include a thermal insulation layer. In tropical climates (the primary target), thermal mass is more valuable than insulation. For temperate climates, an external insulation layer can be added outside the lime plaster.

## Acoustic Performance

The dense mortar core provides good sound attenuation:

- **Estimated STC (Sound Transmission Class):** 40–45 for a single panel wall
- **With lime plaster on both sides:** STC 42–48
- **Comparison:** Standard concrete block wall: STC 40–45. The panel system is comparable.

## Load Capacity

> **Disclaimer:** The values below are conservative analytical estimates based on material properties and geometry. They are NOT based on laboratory testing. Do not use these values for structural engineering without independent verification. Actual performance depends on material quality, workmanship, and connection details. See [Testing Needed](#testing-needed) below.

### Panel Self-Weight

| Component | Weight |
|---|---|
| Steel L-angle frame (L 40×40×4, 7 m at 2.42 kg/m + clamping strips + gussets) | ~22 kg |
| Mortar, cement-sand, baseline (0.147 m³ net × ~2 000 kg/m³) | ~294 kg |
| Bamboo strips + diagonals (30 % cavity density) | ~42 kg |
| Lime plaster (10 mm each face × 1 800 kg/m³) | ~90 kg |
| HDPE blocks, wire, mesh, conduit, cables, lime wash, misc | ~12 kg |
| **Total panel weight, baseline mix** | **~460 kg** |
| **Weight per m² of wall, baseline** | **~184 kg/m²** |
| Total panel weight, optimized bahareque mix (pozzolanic lime + pasto estrella + 5 mm plaster) | ~380 kg |
| Weight per m² of wall, optimized | ~152 kg/m² |

For comparison: 150 mm concrete block wall ≈ 180 kg/m². The panel system at baseline is roughly equivalent to conventional masonry in weight per unit area; the optimized bahareque mix is ~15 % lighter. Both specs are dramatically lighter than reinforced concrete (~300 kg/m² for a 125 mm poured wall) and carry far lower embodied CO₂ per unit area.

### Axial (Vertical) Load

Each panel has two vertical L-angle side posts that can carry significant compressive loads:

| Element | Cross-section | Conservative axial capacity |
|---|---|---|
| Side L-angle post (L 40×40×4 mm) | A ≈ 304 mm² | ~36 kN per post (at σ = 120 MPa, ~50 % of A36 yield) |
| Two side L-angle posts per panel | 2 × 304 mm² | ~72 kN per panel |

**What this means in practice:**

A typical single-story house with a loft/mezzanine and terracotta tile roof imposes roughly 200–400 kg of load per linear meter of wall (roof + ceiling + mezzanine floor + live load), i.e. ~2–4 kN/m. A single 1 m panel with ~72 kN of steel-alone axial capacity provides **roughly 18–36× the typical residential demand** — and the mortar and bamboo contribute additional capacity that has not yet been quantified through testing.

**The panels carry a second floor and roof comfortably.** The analytical estimate of steel-alone capacity is already many times above typical residential loads, but exact composite capacity requires lab validation.

When used **with a separate steel building frame** (steel columns between panels), this panel axial capacity is pure reserve margin — the columns carry the gravity loads. When used **without a separate building frame**, the panels are the load-bearing structure. In that case, a timber or bamboo ring beam at the top of the wall distributes the roof load evenly across all panels and ties them together.

Buckling is not a concern at these load levels **when the L-angle is embedded in the panel composite**: the 85 mm mortar wall thickness provides continuous lateral stiffness to the angle frame, and the panel height-to-thickness ratio (~2,500/85 ≈ 29) is well within accepted slenderness limits for reinforced walls. The diagonal bamboo bracing adds racking and out-of-plane stiffness to the composite.

**Important: open-profile weak-axis limitation.** Open structural profiles — L-angles, T-bars, C-channels — have minimal stiffness about their weak axis. A freestanding L 40×40×4 post without panel bracing (I_min ≈ 3.8 × 10⁴ mm⁴ about the weak axis through the heel) would buckle under modest load. The 36 kN per L-angle capacity stated above is the **axial yield capacity** and is ONLY achievable when the angle is continuously braced by the panel infill (mortar + guadua). This distinction is critical for construction sequencing — the L-angle frame must not be axially loaded before panels are poured, cured, and carrying composite load. For freestanding columns in multi-story buildings, open profiles are not appropriate — use square hollow section (SHS) instead.

### Lateral (In-Plane / Racking) Load

This is the panel's primary structural contribution — resisting horizontal forces from wind and earthquakes.

**Without diagonal bracing (mortar + vertical strips only):**

Conservative estimate based on mortar shear strength (τ ≈ 0.3 MPa for 1:4 cement:sand mortar) across the panel cross-section:

- Shear area: ~85 mm × 1,000 mm = 85,000 mm²
- Conservative shear capacity: 85,000 × 0.3 = ~25 kN per panel
- With safety factor 3: **~8 kN working load per panel**

**With diagonal bracing (the designed configuration):**

The diagonal bamboo strip (60 × 20 mm, Guadua angustifolia) in tension:

- Cross-section: 1,200 mm²
- Conservative tensile strength: 80 MPa (using ~50% of published 150–200 MPa)
- Diagonal tension capacity: 1,200 × 80 = ~96 kN
- Horizontal component (cos 69°): ~96 × 0.36 = ~34 kN per diagonal
- Two diagonals (one per side, one in tension): ~34 kN
- Wire ties and mortar interlock add additional resistance
- With safety factor 3: **~12–15 kN working racking load per panel**

**For context:** A 3 m wide wall section (3 panels) provides ~36–45 kN of racking resistance. A single-story residential building in a moderate seismic zone (PGA 0.2g) with 30 kN of seismic mass above the wall needs roughly 6 kN of base shear resistance per linear meter of wall. Three panels per meter provide 4–5× this requirement.

These are very conservative numbers. The mortar matrix, wire tie grid, and )( profile all contribute additional resistance not accounted for above.

### Out-of-Plane (Wind / Impact) Load

The panel resists pressure perpendicular to the wall face (wind suction/pressure, impact):

- The mortar arch created by the )( profile acts as a shallow vault between the rigid top and bottom L-angle members
- Conservative estimate for uniform wind pressure, treating the panel as a simply supported slab:

| Parameter | Value |
|---|---|
| Panel span (between top/bottom L-angles) | 2.5 m |
| Panel width | 1.0 m |
| Mortar thickness (minimum, at center) | ~55 mm |
| Mortar flexural strength (conservative) | 1.0 MPa |
| Estimated uniform pressure capacity | ~0.7 kPa |
| With safety factor 2 | **~0.35 kPa working load** |

**For context:** 0.35 kPa ≈ wind speed ~25 m/s (90 km/h). For higher wind zones, the steel frame (not the panel) carries the wind load through the beam-to-column connections. The panel only needs to resist local pressure between its own frame members.

The bamboo strip grid and wire ties provide significant additional out-of-plane resistance not captured in the simple slab model — the panel is a composite, not a plain mortar slab.

### Point Loads (Fixtures, Shelves, Cabinets)

| Fixture type | Anchor method | Conservative capacity |
|---|---|---|
| Light items (pictures, clocks, towel hooks) | Masonry nail or screw into mortar | 5–10 kg per anchor |
| Medium items (shelves, mirrors, small cabinets) | Plastic expansion anchor in mortar (6–8 mm) | 15–25 kg per anchor |
| Heavy items (kitchen cabinets, water heater, TV mount) | Through-bolt to steel L-angle web | 50–100 kg per anchor |
| Very heavy items (bookshelf, full pantry) | Multiple through-bolts to L-angle + distribution plate | 200+ kg per mounting point |

**Tip:** The L-angle frame runs along the panel perimeter at a known position (flush with the panel face, web extending inward). A stud-finder or magnet locates the vertical posts easily. Through-bolting to the angle web provides reliable, high-capacity anchorage comparable to steel stud framing.

### Summary — Conservative Capacity in kg per Panel

For builders and non-engineers, here are the same numbers expressed in kilograms. These are **very conservative working loads** (already divided by safety factors of 2–3). Actual failure loads are 2–3× higher.

| Load type | Direction | Conservative working capacity | What this means in practice |
|---|---|---|---|
| **Racking (seismic/wind)** | Horizontal, in the wall plane | **~1,200–1,500 kg per panel** | A typical single-story house needs ~600 kg of racking resistance per meter of wall — one panel provides 2× that. |
| **Out-of-plane (wind pressure)** | Perpendicular to wall face | **~90 kg spread over the panel face** | Equivalent to ~36 kg/m² uniform pressure. A person leaning hard against the wall (~80 kg on ~0.3 m²) is well within capacity. |
| **Axial (vertical)** | Downward, through the panel | **Far exceeds residential loads** | The two side L-angle posts alone carry many times a typical roof + upper floor per meter of wall. Panels can carry a second story and roof without a separate steel building frame. Exact capacity to be validated through testing. |
| **Point load to mortar** | Pull-out / shear at anchor | **~15–25 kg per anchor** | A shelf bracket with 2 anchors holds 30–50 kg safely. |
| **Point load to L-angle** | Through-bolt | **~50–100 kg per bolt** | A kitchen cabinet with 4 through-bolts holds 200–400 kg safely. |

> **Important:** These are estimates, not tested values. They will be validated through physical testing. Do not use for structural engineering without independent verification. When in doubt, attach heavy items to the steel building frame, not to the panel.

## Durability (80–100 Year Design Life)

| Component | Degradation mechanism | Prevention | Expected life |
|---|---|---|---|
| Steel frame | Corrosion | Hot-dip galvanizing (85 μm+) | 80–100 years (non-coastal) |
| Bamboo strips | Insect attack, fungal decay | Borate treatment + mortar encasement (alkaline, anaerobic) | 80+ years |
| Mortar | Carbonation, weathering | Protected by lime plaster (sacrificial layer) | 100+ years |
| Lime plaster | Surface erosion, micro-cracking | Self-healing (carbonation fills cracks), renewable lime wash | Indefinite with maintenance |
| Lime wash | UV degradation, rain erosion | Reapply every 5–10 years | 5–10 years per coat |
| Electrical | Insulation degradation | PVC conduit allows cable replacement without opening wall | Cables: 30–50 years, replaceable |
| HDPE blocks | None significant | UV-protected (inside wall) | 100+ years |

### Maintenance Schedule

| Interval | Action | Estimated cost |
|---|---|---|
| Every 5–10 years | Lime wash renewal | $50–100 per building |
| Every 15–20 years | Inspect lime plaster, patch cracks | $100–300 per building |
| Every 30–40 years | Inspect electrical, replace cables if needed | $200–500 per building |
| At 40 years | Inspect steel frame at accessible points (spot re-galvanize if needed) | $200–400 |
| **Lifetime total** | | **$1,400–2,000** |

## Testing Needed

**All load capacity values above are analytical estimates.** They will be validated through physical testing as part of this project's development. The first panels will be built and tested before any building is occupied.

Planned testing program:

- [ ] **Racking shear tests** (ASTM E564 or equivalent) — panels with and without diagonals, to validate the 3–5× improvement estimate
- [ ] **Out-of-plane load tests** — uniform pressure and point impact, to validate the )( profile benefit
- [ ] **Fire resistance tests** (ASTM E119 or equivalent) — time to structural failure
- [ ] **Cyclic seismic tests** — full-scale shake table or quasi-static cyclic loading, to verify ductile failure mode
- [ ] **Connection tests** — panel-to-column bolt tab capacity, snap connector durability
- [ ] **Long-term weathering tests** — accelerated aging of mortar-encased bamboo samples
- [ ] **Acoustic transmission tests** (ASTM E90) — STC measurement
- [ ] **Point load pull-out tests** — masonry anchor and through-bolt capacity in mortar + L-angle frame

Test results will be published in this repository as they become available. If you have access to testing facilities and want to contribute, please get in touch — collaborative testing across different bamboo species and mortar mixes will make this system stronger for everyone.

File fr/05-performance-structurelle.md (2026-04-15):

# Performance structurelle

## Architecture du systeme

Ce systeme de panneaux a ete concu pour fonctionner **avec une ossature en acier poteaux-poutres** -- la configuration que nous recommandons pour les batiments a plusieurs etages en zones sismiques. Dans cette configuration, l'ossature en acier supporte les charges gravitaires et sismiques tandis que les panneaux assurent le contreventement lateral, l'enveloppe climatique, la masse thermique et les equipements integres.

Cependant, les panneaux sont **structurellement capables de fonctionner sans ossature en acier**. Avec une capacite de compression depassant largement les charges residentielles typiques (deux montants lateraux en corniere L L 40x40x4), une rangee de panneaux peut aisement porter un deuxieme etage et une toiture sans structure en acier independante. Une simple lisse haute en bois ou en bambou relie les panneaux en tete et repartit la charge de toiture.

**Deux configurations :**

| Configuration | Cas d'usage | Role du panneau |
|---|---|---|
| **Avec ossature en acier** (recommande) | Plusieurs etages, zones hautement sismiques, commercial/institutionnel | Remplissage -- les panneaux sont boulonnes dans l'ossature, l'acier supporte les charges principales |
| **Sans ossature en acier** (plus simple, moins couteux) | Un etage + mezzanine, zones sismiques moderees, residentiel | Porteur -- les panneaux supportent directement la toiture et l'etage superieur |

Les estimations de capacite portante ci-dessous s'appliquent aux deux configurations. L'ossature en acier ajoute de la redondance et de la resistance en flexion, mais n'est pas necessaire pour que les panneaux fonctionnent structurellement.

## Performance sismique

### Contreventement diagonal

Chaque panneau contient deux lattes diagonales en bambou (une par face, coins opposes), formant un X vu de face. Sous charge sismique :

1. **Conversion cisaillement vers traction :** Lorsque l'ossature du batiment se deforme lateralement, une diagonale passe en traction tandis que l'opposee passe en compression. La diagonale en bambou en traction resiste efficacement a l'effort de contreventement -- le bambou possede une excellente resistance en traction (150-200 MPa pour la Guadua angustifolia).
2. **Pre-tension :** Les diagonales sont installees avec une legere pre-tension, eliminant le jeu et assurant une mise en charge immediate.
3. **Grille de ligatures :** Les ligatures en fil galvanise a chaque croisement diagonale-verticale (~16-20 ligatures au total) repartissent l'effort diagonal sur toute la surface du panneau, empechant la rupture localisee.

**Amelioration estimee : 3 a 5 fois la resistance au contreventement** par rapport aux panneaux sans contreventement diagonal.

### Le profil )(

Les blocs en PEHD maintiennent les lattes de bambou a 30 mm de l'ame en haut et en bas. A mi-hauteur, les lattes flechissent vers l'interieur en direction de l'ame. Le mortier remplit cet espace variable, creant une section transversale en arc naturel :

- **Resistance hors plan :** L'arc de mortier agit comme une voute surbaissee, repartissant efficacement les charges de vent ou d'impact vers les bords rigides du cadre.
- **Verrouillage mecanique :** Le mortier d'epaisseur variable bloque les lattes de bambou en place -- elles ne peuvent etre retirees sans casser le mortier.

### Mode de rupture ductile

La combinaison de lattes de bambou, de ligatures en fil metallique et de mortier cree un composite qui rompt progressivement :

1. D'abord : le mortier se fissure (avertissement visible)
2. Puis : les ligatures s'etirent (absorption d'energie)
3. Puis : les lattes de bambou se deforment (haute ductilite)
4. L'ossature en acier reste intacte tout au long -- le batiment ne s'effondre pas

Cela differe fondamentalement de la maconnerie non armee, qui rompt de maniere fragile (effondrement soudain sans avertissement).

## Resistance au feu

- **Enrobage de mortier :** Les lattes de bambou sont entierement enrobees de mortier (~85 mm d'epaisseur de mur). Le mortier est incombustible et agit comme isolant thermique pour le bambou.
- **Carbonisation du bambou :** Meme si le feu penetre le mortier, le bambou se carbonise lentement et de maniere previsible (similaire a la construction en bois). L'ossature en acier derriere maintient l'integrite structurelle.
- **Enduit a la chaux :** Incombustible. Fournit une protection supplementaire contre le feu.
- **Pas de bambou expose :** Une fois installe et fini, aucun bambou n'est visible ni accessible a la flamme.

## Performance thermique

- **Masse thermique :** ~85 mm de mortier fournissent une masse thermique significative -- absorbe la chaleur le jour, la restitue la nuit. Reduit les variations de temperature dans les climats tropicaux.
- **Respirabilite :** L'enduit a la chaux est permeable a la vapeur d'eau. L'humidite traverse le mur plutot que d'etre piegee, empechant la condensation et les moisissures.
- **Pas de lame d'air isolante :** Le systeme n'inclut pas de couche d'isolation thermique. Dans les climats tropicaux (la cible principale), la masse thermique a plus de valeur que l'isolation. Pour les climats temperes, une couche d'isolation externe peut etre ajoutee par-dessus l'enduit a la chaux.

## Performance acoustique

Le noyau dense en mortier offre une bonne attenuation sonore :

- **STC estime (Sound Transmission Class) :** 40-45 pour un mur a panneau simple
- **Avec enduit a la chaux sur les deux faces :** STC 42-48
- **Comparaison :** Mur en bloc de beton standard : STC 40-45. Le systeme de panneaux est comparable.

## Capacite portante

> **Avertissement :** Les valeurs ci-dessous sont des estimations analytiques prudentes basees sur les proprietes des materiaux et la geometrie. Elles ne sont PAS basees sur des essais en laboratoire. Ne pas utiliser ces valeurs pour l'ingenierie structurelle sans verification independante. La performance reelle depend de la qualite des materiaux, de la mise en oeuvre et des details d'assemblage. Voir [Essais necessaires](#essais-necessaires) ci-dessous.

### Poids propre du panneau

| Composant | Poids |
|---|---|
| Cadre en corniere L en acier (L 40x40x4, 7 m a 2,42 kg/m + bandes de serrage + goussets) | ~22 kg |
| Mortier de noyau (de base : ciment-sable, ~0,147 m3, densite durcie ~2 000 kg/m3) | ~294 kg |
| Lattes de bambou + diagonales (~30 % densite de cavite) | ~38 kg |
| Blocs PEHD, fil, grillage, gaine, cables | ~6 kg |
| Enduit a la chaux (10 mm les deux faces) | ~100 kg |
| **Poids total du panneau, melange de base** | **~460 kg** |
| **Poids par m2 de mur, base** | **~184 kg/m2** |
| Poids total du panneau, melange bahareque optimise (chaux pouzzolanique + pasto estrella + enduit 5 mm) | ~380 kg |
| Poids par m2 de mur, optimise | ~152 kg/m2 |
| Poids d'expedition de l'assemblage a sec (cadre + bambou + grillage + equipements, avant coulage) | ~75 kg |

Pour comparaison : un mur en bloc de beton de 150 mm pese environ 180 kg/m2. Le systeme de panneaux (melange de base) pese a peu pres autant que la maconnerie conventionnelle par unite de surface ; le melange bahareque optimise est ~15 % plus leger. Critique pour la logistique : le **poids d'expedition de l'assemblage a sec (~75 kg)** est la forme sous laquelle le panneau est transporte de l'atelier au chantier (le mortier est coule sur place).

### Charge axiale (verticale)

Chaque panneau possede deux montants lateraux verticaux en corniere L capables de supporter des charges de compression significatives :

| Element | Section | Capacite axiale prudente |
|---|---|---|
| Montant lateral en corniere L (L 40x40x4 mm) | A = 304 mm2 | ~36 kN par montant (a sigma = 120 MPa, ~50 % de la limite elastique A36) |
| Deux montants lateraux par panneau | 2 x 304 mm2 | ~72 kN par panneau (~7 200 kg) |

**Ce que cela signifie en pratique :**

Une maison typique a un etage avec mezzanine et toiture en tuiles terre cuite impose environ 200-400 kg de charge par metre lineaire de mur (toiture + plafond + plancher de mezzanine + charge d'exploitation). Un seul panneau de 1 m peut supporter **18 a 36 fois cette exigence**. **Les panneaux n'ont pas besoin d'une ossature en acier separee pour porter un deuxieme etage et une toiture.**

Utilises **avec une ossature en acier**, cette capacite axiale est une pure marge de reserve -- l'acier supporte les charges gravitaires. Utilises **sans ossature en acier**, les panneaux sont la structure porteuse. Dans ce cas, une lisse haute en bois ou en bambou en tete du mur repartit la charge de toiture uniformement sur tous les panneaux et les relie entre eux.

Le flambage n'est pas une preoccupation a ces niveaux de charge **lorsque la corniere L est noyee dans le composite du panneau** : l'epaisseur de mur en mortier de 85 mm fournit au cadre angulaire une rigidite laterale continue, et le rapport hauteur/epaisseur du panneau (~2 500/85 = 29) est bien en deca des limites d'elancement acceptees pour les murs armes.

**Important : limitation des profiles ouverts sur l'axe faible.** Les profiles structurels ouverts -- cornieres L, profiles T, profiles C -- ont une rigidite minimale autour de leur axe faible. Un montant L 40x40x4 autoportant sans contreventement par le panneau (I_min = 3,8 x 10⁴ mm⁴ autour de l'axe faible passant par le talon) flamberait sous une charge modeste. La capacite de 36 kN par corniere L indiquee ci-dessus est la **capacite de limite elastique axiale** et n'est atteignable QUE lorsque la corniere est continument contreventee par le remplissage du panneau (mortier + guadua). Cette distinction est cruciale pour le sequencage de la construction -- le cadre en corniere L ne doit pas etre charge axialement avant que les panneaux soient coules, durcis et travaillent en composite. Pour les colonnes autoportantes dans les batiments a plusieurs etages, les profiles ouverts ne conviennent pas -- utiliser un tube carre (SHS) a la place.

### Charge laterale (dans le plan / contreventement)

C'est la contribution structurelle principale du panneau -- resister aux forces horizontales du vent et des seismes.

**Sans contreventement diagonal (mortier + lattes verticales uniquement) :**

Estimation prudente basee sur la resistance au cisaillement du mortier (tau = 0,3 MPa pour un mortier 1:4 ciment:sable) sur la section du panneau :

- Surface de cisaillement : ~85 mm x 1 000 mm = 85 000 mm2
- Capacite de cisaillement prudente : 85 000 x 0,3 = ~25 kN par panneau
- Avec coefficient de securite 3 : **~8 kN en charge de service par panneau**

**Avec contreventement diagonal (la configuration concue) :**

La latte diagonale en bambou (60 x 20 mm, Guadua angustifolia) en traction :

- Section : 1 200 mm2
- Resistance en traction prudente : 80 MPa (utilisant ~50% des 150-200 MPa publies)
- Capacite de traction diagonale : 1 200 x 80 = ~96 kN
- Composante horizontale (cos 69 deg) : ~96 x 0,36 = ~34 kN par diagonale
- Deux diagonales (une par face, une en traction) : ~34 kN
- Les ligatures et le verrouillage du mortier ajoutent une resistance supplementaire
- Avec coefficient de securite 3 : **~12-15 kN en charge de service de contreventement par panneau**

**En contexte :** Une section de mur de 3 m de large (3 panneaux) fournit ~36-45 kN de resistance au contreventement. Un batiment residentiel a un etage en zone sismique moderee (PGA 0,2g) avec 30 kN de masse sismique au-dessus du mur necessite environ 6 kN de resistance a l'effort tranchant a la base par metre lineaire de mur. Trois panneaux par metre fournissent 4 a 5 fois cette exigence.

Ce sont des chiffres tres prudents. La matrice de mortier, la grille de ligatures et le profil )( contribuent tous a une resistance supplementaire non comptabilisee ci-dessus.

### Charge hors plan (vent / impact)

Le panneau resiste a la pression perpendiculaire a la face du mur (succion/pression du vent, impact) :

- L'arc de mortier cree par le profil )( agit comme une voute surbaissee entre les profiles en T superieur et inferieur rigides
- Estimation prudente pour une pression de vent uniforme, en traitant le panneau comme une dalle simplement appuyee :

| Parametre | Valeur |
|---|---|
| Portee du panneau (entre profiles en T haut/bas) | 2,5 m |
| Largeur du panneau | 1,0 m |
| Epaisseur du mortier (minimum, au centre) | ~55 mm |
| Resistance en flexion du mortier (prudente) | 1,0 MPa |
| Capacite estimee en pression uniforme | ~0,7 kPa |
| Avec coefficient de securite 2 | **~0,35 kPa en charge de service** |

**En contexte :** 0,35 kPa correspond a une vitesse de vent de ~25 m/s (90 km/h). Pour les zones de vent plus fort, l'ossature en acier (pas le panneau) supporte la charge de vent via les assemblages poutre-poteau. Le panneau doit seulement resister a la pression locale entre ses propres elements de cadre.

La grille de lattes de bambou et les ligatures fournissent une resistance hors plan supplementaire significative non captee dans le modele de dalle simple -- le panneau est un composite, pas une simple dalle de mortier.

### Charges ponctuelles (fixations, etageres, placards)

| Type de fixation | Methode d'ancrage | Capacite prudente |
|---|---|---|
| Elements legers (cadres, horloges, pateres) | Clou de maconnerie ou vis dans le mortier | 5-10 kg par ancrage |
| Elements moyens (etageres, miroirs, petits placards) | Cheville a expansion plastique dans le mortier (6-8 mm) | 15-25 kg par ancrage |
| Elements lourds (placards de cuisine, chauffe-eau, support TV) | Boulon traversant vers l'ame de la corniere L | 50-100 kg par ancrage |
| Elements tres lourds (bibliotheque, garde-manger plein) | Boulons traversants multiples vers la corniere L + plaque de repartition | 200+ kg par point de fixation |

**Conseil :** L'ame de la corniere L se trouve a une position connue (centre de l'epaisseur du mur). Un detecteur de montant ou un aimant la localise facilement. Le boulonnage traversant vers l'ame fournit un ancrage fiable et de haute capacite comparable a une ossature a montants metalliques.

### Resume -- Capacite prudente en kg par panneau

Pour les constructeurs et non-ingenieurs, voici les memes chiffres exprimes en kilogrammes. Ce sont des **charges de service tres prudentes** (deja divisees par des coefficients de securite de 2-3). Les charges de rupture reelles sont 2-3 fois plus elevees.

| Type de charge | Direction | Capacite de service prudente | Ce que cela signifie en pratique |
|---|---|---|---|
| **Contreventement (sismique/vent)** | Horizontale, dans le plan du mur | **~1 200-1 500 kg par panneau** | Une force horizontale de 1,2-1,5 tonnes appliquee en tete d'un seul panneau avant qu'il atteigne sa limite de service. Une maison typique a un etage necessite ~600 kg de resistance au contreventement par metre de mur -- un panneau en fournit le double. |
| **Hors plan (pression du vent)** | Perpendiculaire a la face du mur | **~90 kg repartis sur la surface du panneau** | Equivalent a ~36 kg/m2 de pression uniforme. Une personne s'appuyant fortement contre le mur (~80 kg sur ~0,3 m2) est bien en deca de la capacite. |
| **Axiale (verticale)** | Vers le bas, a travers le panneau | **Depasse largement les charges residentielles (~7 200 kg de limite elastique axiale par panneau en composite)** | Les deux montants en corniere L supportent bien plus que la charge typique d'une toiture + etage superieur par metre de mur. Les panneaux peuvent porter un deuxieme etage et une toiture sans ossature en acier separee. |
| **Charge ponctuelle dans le mortier** | Arrachement / cisaillement a l'ancrage | **~15-25 kg par ancrage** | Une equerre d'etagere avec 2 ancrages supporte 30-50 kg en toute securite. |
| **Charge ponctuelle sur la corniere L** | Boulon traversant | **~50-100 kg par boulon** | Un placard de cuisine avec 4 boulons traversants supporte 200-400 kg en toute securite. |

> **Important :** Ce sont des estimations, pas des valeurs testees. Elles seront validees par des essais physiques. Ne pas utiliser pour l'ingenierie structurelle sans verification independante. En cas de doute, fixer les elements lourds a l'ossature metallique du batiment, pas au panneau.

## Durabilite (duree de vie de conception de 80-100 ans)

| Composant | Mecanisme de degradation | Prevention | Duree de vie attendue |
|---|---|---|---|
| Ossature en acier | Corrosion | Galvanisation a chaud (85 um+) | 80-100 ans (non cotier) |
| Lattes de bambou | Attaque d'insectes, degradation fongique | Traitement au borate + enrobage de mortier (alcalin, anaerobie) | 80+ ans |
| Mortier | Carbonatation, erosion | Protege par l'enduit a la chaux (couche sacrificielle) | 100+ ans |
| Enduit a la chaux | Erosion de surface, microfissuration | Auto-cicatrisant (la carbonatation comble les fissures), badigeon de chaux renouvelable | Indefinie avec entretien |
| Badigeon de chaux | Degradation UV, erosion par la pluie | Renouveler tous les 5-10 ans | 5-10 ans par couche |
| Electricite | Degradation de l'isolant | La gaine PVC permet le remplacement des cables sans ouvrir le mur | Cables : 30-50 ans, remplacables |
| Blocs en PEHD | Aucune significative | Proteges des UV (a l'interieur du mur) | 100+ ans |

### Calendrier de maintenance

| Intervalle | Action | Cout estime |
|---|---|---|
| Tous les 5-10 ans | Renouvellement du badigeon de chaux | 50-100 $ par batiment |
| Tous les 15-20 ans | Inspection de l'enduit a la chaux, colmatage des fissures | 100-300 $ par batiment |
| Tous les 30-40 ans | Inspection electrique, remplacement des cables si necessaire | 200-500 $ par batiment |
| A 40 ans | Inspection de l'ossature en acier aux points accessibles (re-galvanisation ponctuelle si necessaire) | 200-400 $ |
| **Total sur la duree de vie** | | **1 400-2 000 $** |

## Essais necessaires

**Toutes les valeurs de capacite portante ci-dessus sont des estimations analytiques.** Elles seront validees par des essais physiques dans le cadre du developpement de ce projet. Les premiers panneaux seront construits et testes avant qu'un batiment ne soit occupe.

Programme d'essais prevu :

- [ ] **Essais de cisaillement par contreventement** (ASTM E564 ou equivalent) -- panneaux avec et sans diagonales, pour valider l'estimation d'amelioration de 3-5x
- [ ] **Essais de charge hors plan** -- pression uniforme et impact ponctuel, pour valider le benefice du profil )(
- [ ] **Essais de resistance au feu** (ASTM E119 ou equivalent) -- temps jusqu'a la rupture structurelle
- [ ] **Essais sismiques cycliques** -- table vibrante en grandeur reelle ou chargement cyclique quasi-statique, pour verifier le mode de rupture ductile
- [ ] **Essais d'assemblage** -- capacite des pattes de boulonnage panneau-poteau, durabilite des connecteurs rapides
- [ ] **Essais de vieillissement accelere** -- vieillissement accelere d'echantillons de bambou enrobe de mortier
- [ ] **Essais de transmission acoustique** (ASTM E90) -- mesure du STC
- [ ] **Essais d'arrachement de charges ponctuelles** -- capacite des chevilles de maconnerie et des boulons traversants dans le mortier + corniere L

Les resultats des essais seront publies dans ce depot au fur et a mesure de leur disponibilite. Si vous avez acces a des installations d'essai et souhaitez contribuer, contactez-nous -- des essais collaboratifs sur differentes especes de bambou et differents dosages de mortier rendront ce systeme plus robuste pour tous.

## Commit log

2026-03-28 updated name
    [01_frame.stl, 02_hdpe_blocks.stl, 03_guadua_verticals.stl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]
2026-03-28 added pdf, some improvements
    [01_frame.stl, 02_hdpe_blocks.stl, 03_guadua_verticals.stl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]
2026-03-30 Correct SVG technical drawings and sync all translations
    The initial SVG diagrams were rough drafts with various inaccuracies in perspective, assembly order, component placement, and proportions.
    This commit corrects:
    - Assembly order: web → HDPE block → bamboo strips → clamping strip
    - HDPE blocks added to all cross-section and clamping system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
2026-03-31 v0.2.0 — Floor panel concept: bamboo bowstring beam
    New chapter (EN + ES): proposes extending BaharequeModular to horizontal floor/ceiling spans using a bamboo bowstring beam — a tied-arch where bamboo carries compression (arch) and tension (tie), wit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
    New SVGs: floor-panel-side.svg and floor-panel-top.svg showing the bowstring concept with all layers (terracotta, cork, fiber-rich mortar, bamboo arch, cross-piece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
2026-04-15 v0.3.0
    - L-angle frame, corrected weights, optimized bahareque mix - Frame: T 30×30×3 asymmetric → L 40×40×4 commodity angle - Weights: 75 kg dry / 440 kg baseline / 360 kg optimized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
    [01_frame.stl, 01a_frame_front.stl, 01b_frame_rear.stl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]
